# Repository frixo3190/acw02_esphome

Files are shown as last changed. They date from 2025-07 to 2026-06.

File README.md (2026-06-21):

# ACW02 ESPHome Module  

Custom ESPHome component for **Teknopoint** and **Airton** (Airton ref: 409729) AC units using the **Tuya ACW02 Wi-Fi module**.

---

## Weekly build status (auto build with last esphome version)

**ESP32 D1 Mini WROOM 32**  
 &nbsp;
 &nbsp;


**Lolin ESP32 C3 mini**  
 &nbsp;
 &nbsp;


**XIAO ESP32 C3**  
 &nbsp;
 &nbsp;


**XIAO ESP32 C6**  
 &nbsp;
 &nbsp;


---
## 📑 Table of Contents

- [⚠️ Compatibility Warning](#️-compatibility-warning)
- [✅ Community Compatibility List](#-community-compatibility-list)
- [📌 Contribute](#-contribute)
- [📋 Requirements](#-requirements)
- [⚙️ Settings](#️-settings)
  - [📁 Base Configuration](#-base-configuration)
  - [📶 Wi-Fi & Web Server Configuration](#-wi-fi--web-server-configuration)
- [🛠️ Build](#️-build)
  - [📦 Update](#-update)
- [🔍 Interface Details](#-interface-details)
- [🏠 Bonus Jeedom Configuration](#-bonus-jeedom-configuration)
- [📦 Components for Forhorse version](#-components-for-forhorse-version-thanks-to-him)
- [📦 Components for original version](#-components-for-original-version-mine)
  - [⚙️ Choosing the ESP32 Board](#️-choosing-the-esp32-board)
- [🧵 PCB Soldering & Wiring](#-pcb-soldering--wiring)
- [🧱 3D Files](#-3d-files)
  - [🖨️ Printing Material](#️-printing-material)
  - [📂 Available in the `3Dfiles/` directory](#-available-in-the-3dfiles-directory)
  - [🔩 Components](#-components-1)
  - [🧷 Assembly](#-assembly)
- [🧾 Option: QR Code Info](#-option-qr-code-info)
- [❗ Notes](#-notes)
- [⚠️ Disclaimer & Safety Notice](#️-disclaimer--safety-notice)
- [🛡️ License](#️-license)

---
## ⚠️ Compatibility Warning  

> **Important**  
> - Works on most **Teknopoint** units *(unconfirmed but no known issues so far, see the [Community Compatibility List](#-community-compatibility-list))*.  
> - Works on most **Airton** units *(unconfirmed but no known issues so far, see the [Community Compatibility List](#-community-compatibility-list))*.  
> - **Exception – Airton**: AC units using the **Wi-Fi module 409945** are **not compatible** with this firmware.  
>   - These units use a **Tuya MCU UART protocol** (`55 AA 03 ...`) instead of the custom `7A 7A ...` protocol implemented here.  
>   - You can still use **all provided hardware parts** (PCB, wiring, and 3D-printed enclosure) from this repository.  
>   - For these models, use this doc **[ACW02 ESPHome Tuya MCU integration](./docs/TUYA_MCU_SETUP.md)** instead — a basic configuration example is provided in that document and can be adapted to your needs.
> - **Exception – Some Airton mainboards**: Certain Airton units using control boards with a reference similar to `SMVHXX-XBXXXXX` may provide insufficient power on the Wi-Fi module connector for an ESP32-based ACW02 replacement.
>   - Symptoms may include random reboots, Wi-Fi instability, connection failures, or ESP32 brownout resets.
>   - If you experience these issues, power the ACW02 module from an external **5 V USB supply** (micro usb, usb c... depends on the ESP32's USB connector) while keeping the UART connection to the AC unit.
>   - In this configuration, the **original 12 V supply from the AC board must be disconnected** (but keep the GND) from the Wi-Fi/ACW02 connector to avoid back-powering or instability. (In this configuration, the polulu module is no longer necessary.)
>   - example:
    https://www.amazon.fr/dp/B0DLK81PNN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
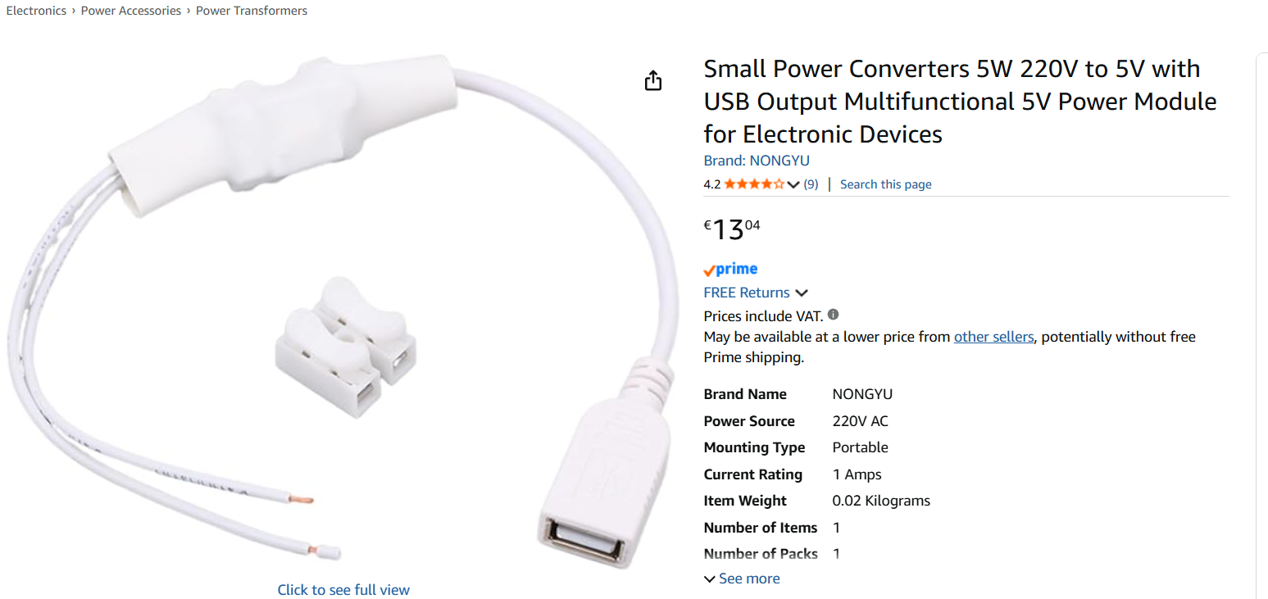
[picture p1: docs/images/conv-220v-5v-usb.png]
    
>   - This converter needs to be connected to the main power supply of the indoor unit, which is normally 220v.
>   - This issue appears to be related to the available current on specific board revisions and does not affect all Airton units.
>   - Further community feedback is welcome to identify the affected board revisions more precisely.
>   - All versions have affected my versions and that of Forhorse.

---

## ✅ Community Compatibility List  

A non-exhaustive list of tested models is available here:  
👉 [COMPATIBILITY.md](https://github.com/devildant/acw02_esphome/blob/main/COMPATIBILITY.md)  

---

## 📌 Contribute  

Help improve this project by reporting your unit compatibility.  
If your model is not referenced, please submit a report (**tested units only**):  
👉 [Submit your unit](https://github.com/devildant/acw02_esphome/issues/new?template=unit_report.yml)  
PS: If you encounter a problem, please post an issue before putting your incompatible model.

---

## 📋 Requirements

- Home Assistant with **MQTT integration** enabled and properly configured
- Enable the WIFI with the AC remote

## ⚙️ Settings

### 📁 Base Configuration

Open `esphome-acw02-en.yaml` or `esphome-acw02-fr.yaml` depending on your preferred language.

If you want to compile using the ESPHome Builder add-on in Home Assistant, use the files from the `HA-esphome-builder` folder instead (`ha-esphome-builder-acw02-en.yaml` or `ha-esphome-builder-acw02-fr.yaml`).

Edit the `substitutions` section — you can modify:

- `dev_name`
- `dev_friendly`
- `api_encrypted_key`
- `ota_password`
- `ap_password`
- `web_server_username`
- `web_server_password`

```yaml
substitutions:
  dev_name: acw02-salon
  dev_friendly: ACW02 salon
  lang: "en"
  api_encrypted_key: "D2oldc0VP++fni6src89tCSC0UwBhNPgyc8vgYN8/mA="
  ota_password: "REPLACE_WITH_YOUR_PASSWORD"
  ap_password: "fallbackpassword"
  web_server_username: admin
  web_server_password: admin
  # ESP32 D1 mini WROOM 32
  board: esp32dev
  TX: GPIO17
  RX: GPIO16
  
  ## LOLIN ESP32 C3 MINI
  # board: lolin_c3_mini
  # TX: GPIO21
  # RX: GPIO20

  ## XIAO (seeeds studio) ESP32 C3
  # board: seeed_xiao_esp32c3
  # TX: GPIO21
  # RX: GPIO20

  ## XIAO (seeeds studio) ESP32 C6
  # board: seeed_xiao_esp32c6
  # TX: GPIO16
  # RX: GPIO17
```

⚠️ **The configuration depends on the ESP32 card chosen (Comment/uncomment the blocks)**  
 - **ESP32 D1 mini WROOM 32**
    ```
    # ESP32 D1 mini WROOM 32
    board: esp32dev
    TX: GPIO17
    RX: GPIO16
    ```
 - **LOLIN ESP32 C3 MINI**
    ```
    # LOLIN ESP32 C3 MINI
    board: lolin_c3_mini
    TX: GPIO21
    RX: GPIO20
    ```
 - **XIAO (seeeds studio) ESP32 C3**
    ```
    # XIAO (seeeds studio) ESP32 C3
    board: seeed_xiao_esp32c3
    TX: GPIO21
    RX: GPIO20
    ```
 - **XIAO (seeeds studio) ESP32 C6**
    ```
    # XIAO (seeeds studio) ESP32 C6
    board: seeed_xiao_esp32c6
    TX: GPIO16
    RX: GPIO17
    ```

🔑 I recommend visiting [this page](https://esphome.io/components/api.html) to generate a unique `api_encrypted_key`.

---

### 📶 Wi-Fi & Web Server Configuration

Open `secrets.yaml` and fill in your Wi-Fi credentials and desired web server access:

```yaml
wifi_ssid: "testesp32"
wifi_password: "testesp32"
wifi_ssid2: "testesp32"
wifi_password2: "testesp32"
wifi_ssid3: "testesp32"
wifi_password3: "testesp32"
```

---

## 🛠️ Build

- [Build on Windows (native)](docs/install_from_windows_directly.md)  
- [Build on MACOS (native)](docs/install_from_macos_directly.md)
- [Build on Windows with Docker](docs/install_from_docker_win.md)
- Build with ESPHome Builder (2025.7.5 minimum) with Home Assistant add-on:  
  Use the files in the [`HA-esphome-builder`](HA-esphome-builder) folder with the Home Assistant ESPHome add-on:  
  - [`ha-esphome-builder-acw02-fr.yaml`](HA-esphome-builder/ha-esphome-builder-acw02-fr.yaml) – version française  
  - [`ha-esphome-builder-acw02-en.yaml`](HA-esphome-builder/ha-esphome-builder-acw02-en.yaml) – English version  

### 📦 Update

> **🔁 After updating:**  
> I recommend pressing the **"G1: Rebuild MQTT Entities"** button to ensure all MQTT discovery topics are refreshed properly.

---

## 🔍 Interface Details

👉 [See Interface Details](docs/interface_details.md)

---

## 🏠 Bonus Jeedom Configuration

> **Note:** Jeedom is **not officially supported**. This is provided as an **informational guide only**.

- [Enable on Jeedom](docs/enable_on_jeedom.md)  

---
### 📦 Components for Forhorse version (thanks to him)
- **PCB**
  - **[Forhorse PCB](https://github.com/devildant/acw02_esphome/blob/main/docs/version_Forhorse.md)**
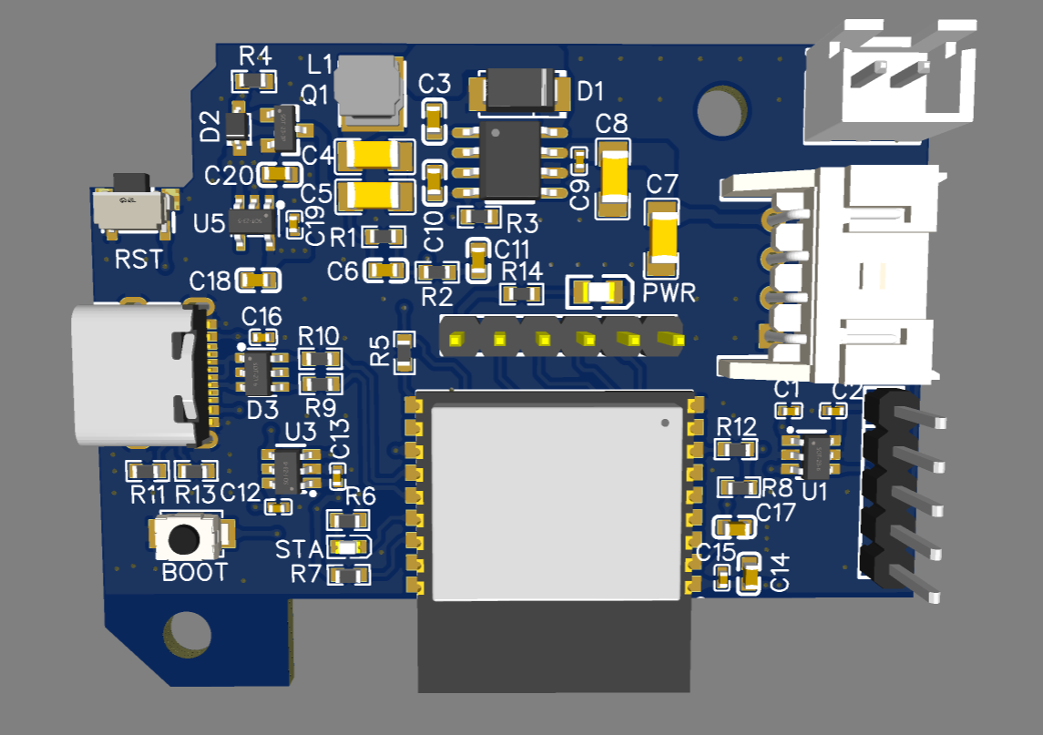
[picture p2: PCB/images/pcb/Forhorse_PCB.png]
Forhorse
    

- **Components**
  - **[Connector: JST XA 2.5 male/male 4 pins (standard direction) (x1)](https://www.aliexpress.com/item/1005008857984831.html)** 

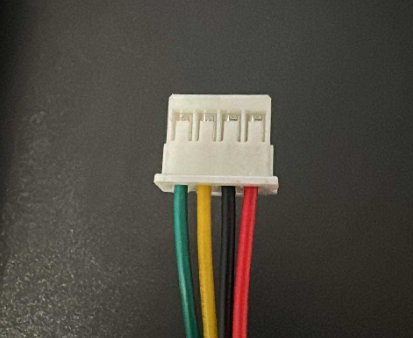
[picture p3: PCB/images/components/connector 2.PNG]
JST order
    

- **Configuration board in yaml**:
```yaml
 # LOLIN ESP32 C3 MINI
 board: lolin_c3_mini
 TX: GPIO21
 RX: GPIO20
```

- **(Optional) Additional configuration to add to the yaml file at the end (currently not linked to the firmware)**:
```yaml
## Start of the section for the STA LED
# Off when everything is OK
# slow blinking in case of warning (Wi-Fi connection issue, etc.)
# fast blinking in case of error
status_led:
  pin:
    number: GPIO03
    inverted: true
## End of the section for the STA LED

## Start of the section for the remote temperature probe
# Temperature probe
sensor:
  - platform: ntc
    id: external_temperature_sensor
    sensor: resistance_sensor
    calibration:
      b_constant: 3950
      reference_temperature: 25°C
      reference_resistance: 10kOhm
    name: NTC Temperature

  # Source sensors:
  - platform: resistance
    id: resistance_sensor
    sensor: source_sensor
    configuration: DOWNSTREAM
    resistor: 10kOhm
    name: Resistance Sensor
    internal: True

  - platform: adc
    id: source_sensor
    pin: GPIO01
    attenuation: 12db
    update_interval: never
    internal: True

switch:
  - platform: gpio
    pin: GPIO10
    id: ntc_vcc
    internal: True

interval:
  - interval: 10s #adjust frequency of measurement refresh here
    then:
      - switch.turn_on: ntc_vcc
      - component.update: source_sensor
      - switch.turn_off: ntc_vcc
## End of the section for the remote temperature probe
```

### 📦 Components for original version (mine)

- **[12V → 5V Regulator D24V10F5](https://shop.mchobby.be/fr/regulateurs/554--regul-5v-1a-step-down-d24v10f5-3232100005549-pololu.html)**  
  [Manufacturer](https://www.pololu.com/product/2831)  
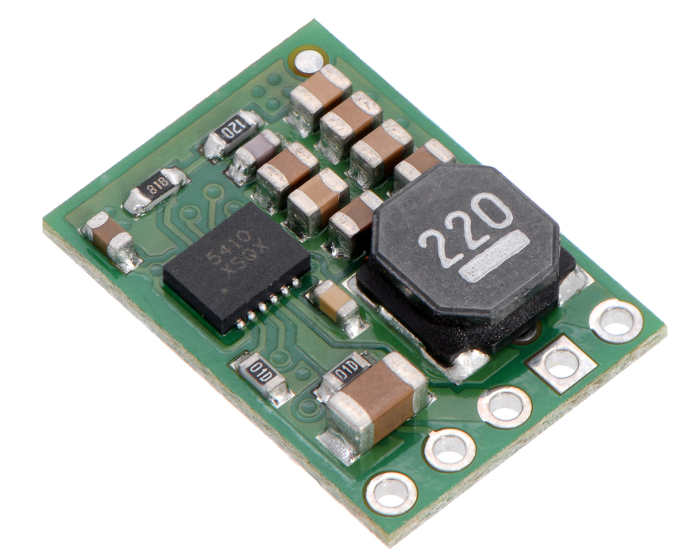
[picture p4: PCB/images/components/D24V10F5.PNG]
D24V10F5
  

- **Channels Logic Level Converter**

  > **2 options available:**  
  > You can either choose a ready-made module based on the CYT1076,  
  > or use a custom board (to be assembled by JLCPCB) designed around two SN74LVC2T45DCUR.  
  > In practice, the second solution is far more optimized for UART communication.  
  > Personally, I recommend this option: a bit more expensive but much more efficient.  
  > (Of course, I might be slightly biased since I designed it myself 🙂)

  - **[4 Channels Logic Level Converter Bi-Directional Shifter (x1): CYT1076](https://amzn.eu/d/2MhG08s)**  
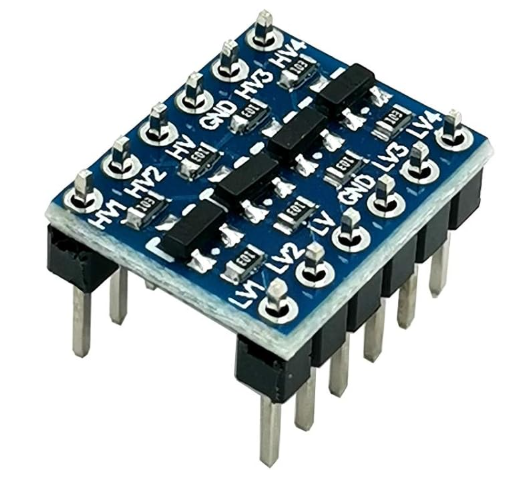
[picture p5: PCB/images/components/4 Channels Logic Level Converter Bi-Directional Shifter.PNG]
CYT1076
    

  - **Channels Logic Level Converter (x1): SN74LVC2T45DCUR**  
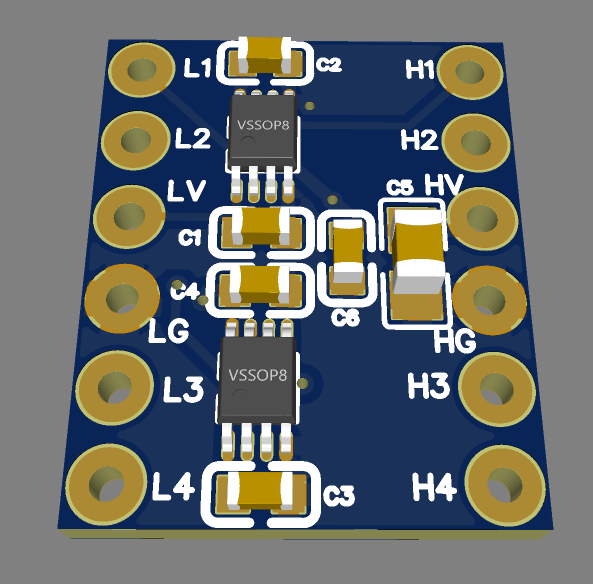
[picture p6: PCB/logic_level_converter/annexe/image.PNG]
SN74LVC2T45DCUR
      
    - 📥 [Download ZIP (GERBER, BOM, Pick & Place)](https://github.com/devildant/acw02_esphome/raw/main/PCB/logic_level_converter/uart_conv_gerber_BOM_PickAndPlace.zip)
    - 👉 [JLCPCB Assembly Guide](docs/uart_convert_jlcpcb.md)

- **PCB and ESP32 (2 options available)**

  - **[ESP32 D1 MINI WROOM 32](https://github.com/devildant/acw02_esphome/blob/main/docs/version_esp32_D1_mini_wroom32.md)**  
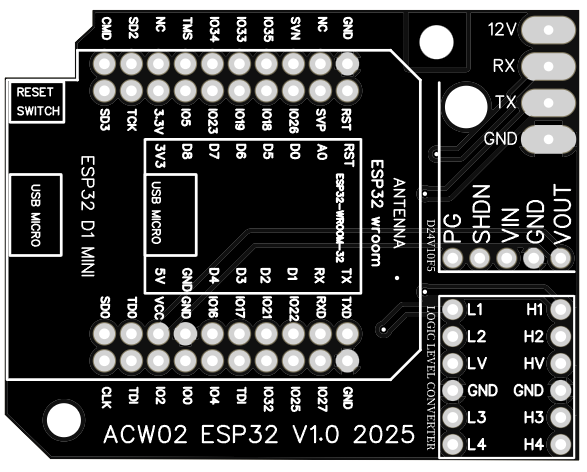
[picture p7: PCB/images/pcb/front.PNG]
front
      
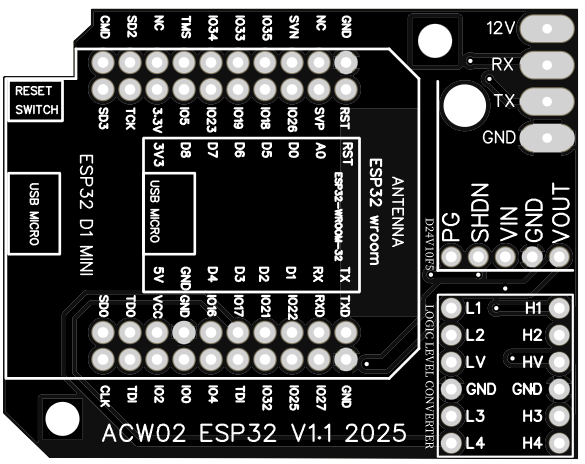
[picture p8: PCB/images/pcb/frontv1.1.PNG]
front
    

  - **[LOLIN ESP32 C3 MINI](https://github.com/devildant/acw02_esphome/blob/main/docs/version_lolin_esp32_C3.md)**  
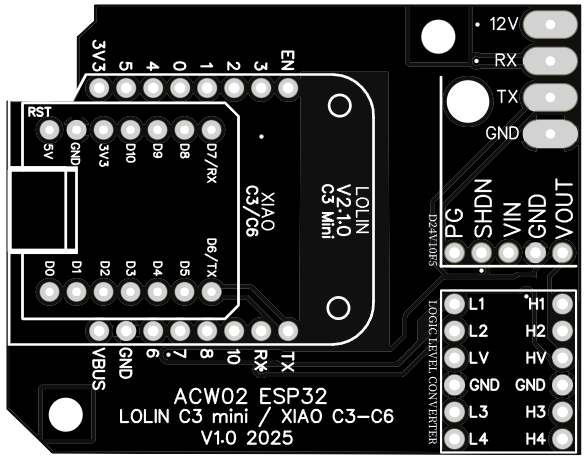
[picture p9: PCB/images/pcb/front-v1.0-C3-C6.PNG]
front
    

  - **[XIAO ESP32 C3-C6](https://github.com/devildant/acw02_esphome/blob/main/docs/version_xiao_esp32_C3_C6.md)**  
    front

- **[5 pins male 2.54mm (x1): MaleL7.5-1X5P](https://fr.aliexpress.com/item/1005007128029220.html)**  
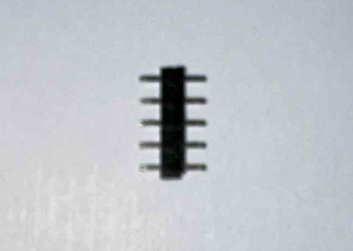
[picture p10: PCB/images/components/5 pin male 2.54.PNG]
  

- **[6 pins male 2.54mm (x2): MaleL7.5-1X6P](https://fr.aliexpress.com/item/1005007128029220.html)**  
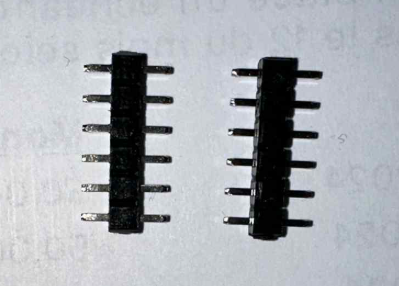
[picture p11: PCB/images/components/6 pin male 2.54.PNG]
  

- **[Connector: JST XA 2.5 male 4 pins (Reverse direction) (x1)](https://www.aliexpress.com/item/1005008857984831.html)**  
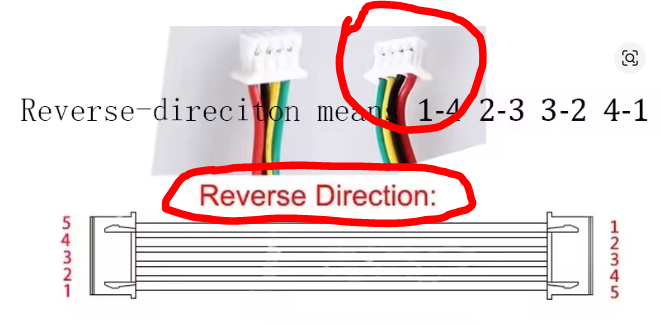
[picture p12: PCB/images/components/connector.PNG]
JST
  

📌 Important: Use reverse wiring for the following order:  
JST order

---

### ⚙️ Choosing the ESP32 Board

Several ESP32 boards can be used with this module. Each has its own pros and cons depending on your needs.

#### ESP32 D1 MINI WROOM 32
- ✅ Used for development, therefore the most tested version  
- ✅ Built-in **reset** button on the case  
- ❌ Many cheap clones with poor 5V → 3.3V regulator (may cause malfunction)  
- ❌ Slightly weaker Wi-Fi signal due to component layout and antenna position  
- ❌ No external antenna support  

#### LOLIN ESP32 C3 MINI (Not recommended)
- ✅ Built-in **reset** button on the case  
- ✅ Better Wi-Fi signal compared to ESP32 D1 MINI WROOM 32  
- ❌ No external antenna support
- ❌ Trouble with modern WIFI router > WIFI 4 (qood singal but WIFI TX/RX very slow, i detect lot of difficulty with wifi 6 in 2.4GHZ)

#### XIAO ESP32 C3
- ✅ External antenna support (Wi-Fi signal ≥ LOLIN ESP32 C3 MINI)  
- ❌ No **reset** button on the case  

#### XIAO ESP32 C6
- ✅ External antenna support  
- ❌ Antenna **not included** (must be purchased separately, internal antenna has very poor reception) 
- ❌ No **reset** button on the case  
- ❌ Average Wi-Fi signal, often weaker than ESP32 D1 MINI WROOM 32 with internal antenna (that's why you need buy the external antenna)

---

### 🧵 PCB Soldering & Wiring

- RED = 12V  
- BLACK = RX  
- YELLOW = TX  
- GREEN = GND

---

## 🧱 3D Files

### 🖨️ Printing Material  

| Material | Compatible | Notes |
|---|---|---|
| PLA | ❌ No | Not recommended (low heat resistance) |
| PETG | ✅ Yes (recommended) | Good balance of strength & printability |
| ABS | ✅ Yes | Better heat resistance |
| ASA | ✅ Yes | UV resistant, suitable for outdoors |
| PC | ✅ Yes | Very strong & heat resistant |

> ⚠️ **Why not use PLA?**  
> - PLA has a glass transition temperature of only **45–50 °C (or even lower)**.  
> - By contrast, **PETG can withstand up to ~80 °C**, making it much more reliable.  
> - For electronic components that generate heat, PLA is unsafe in warm environments — especially if your AC unit also provides **heating**.  

### 📂 Available in the `3Dfiles/` directory:

#### Version 1

- [acw02 case bottom (.stl)](https://github.com/devildant/acw02_esphome/raw/main/3Dfiles/D1-MIMI/Version%201/acw02%20case%20bot.stl)
- [acw02 case top (.stl)](https://github.com/devildant/acw02_esphome/raw/main/3Dfiles/D1-MIMI/Version%201/acw02%20case%20top.stl)
- [Alternative: top case with thermo cable hole](https://github.com/devildant/acw02_esphome/raw/main/3Dfiles/D1-MIMI/Version%201/acw02%20case%20top%20cable%20with%20thermo.stl)

#### Version 2

- [acw02 case bot with air flow (.stl)](https://github.com/devildant/acw02_esphome/raw/main/3Dfiles/D1-MIMI/Version%202/acw02%20case%20bot%20with%20air%20flow.stl)
- [acw02 case top air flow (.stl)](https://github.com/devildant/acw02_esphome/raw/main/3Dfiles/D1-MIMI/Version%202/acw02%20case%20top%20air%20flow.stl)
- [acw02 case top cable with thermo air flow (.stl)](https://github.com/devildant/acw02_esphome/raw/main/3Dfiles/D1-MIMI/Version%202/acw02%20case%20top%20cable%20with%20thermo%20air%20flow.stl)
- [acw02 case top cable with thermo plastic card (.stl)](https://github.com/devildant/acw02_esphome/raw/main/3Dfiles/D1-MIMI/Version%202/acw02%20case%20top%20cable%20with%20thermo%20plastic%20card.stl)
- [acw02 case top plastic card (.stl)](https://github.com/devildant/acw02_esphome/raw/main/3Dfiles/D1-MIMI/Version%202/acw02%20case%20top%20plastic%20card.stl)
- [card (.stl)](https://github.com/devildant/acw02_esphome/raw/main/3Dfiles/D1-MIMI/Version%202/card.stl)

#### Version 2 for pcb Forhorse
- [full pcb acw02 case bot with air flow (.stl)](https://github.com/devildant/acw02_esphome/raw/main/3Dfiles/full%20pcb%20by%20Forhorse/full%20pcb%20acw02%20case%20bot%20with%20air%20flow.stl)
- [acw02 case top air flow (.stl)](https://github.com/devildant/acw02_esphome/raw/main/3Dfiles/D1-MIMI/Version%202/acw02%20case%20top%20air%20flow.stl)
- [acw02 case top cable with thermo air flow (.stl)](https://github.com/devildant/acw02_esphome/raw/main/3Dfiles/D1-MIMI/Version%202/acw02%20case%20top%20cable%20with%20thermo%20air%20flow.stl)
- [acw02 case top cable with thermo plastic card (.stl)](https://github.com/devildant/acw02_esphome/raw/main/3Dfiles/D1-MIMI/Version%202/acw02%20case%20top%20cable%20with%20thermo%20plastic%20card.stl)
- [acw02 case top plastic card (.stl)](https://github.com/devildant/acw02_esphome/raw/main/3Dfiles/D1-MIMI/Version%202/acw02%20case%20top%20plastic%20card.stl)
- [card (.stl)](https://github.com/devildant/acw02_esphome/raw/main/3Dfiles/D1-MIMI/Version%202/card.stl)

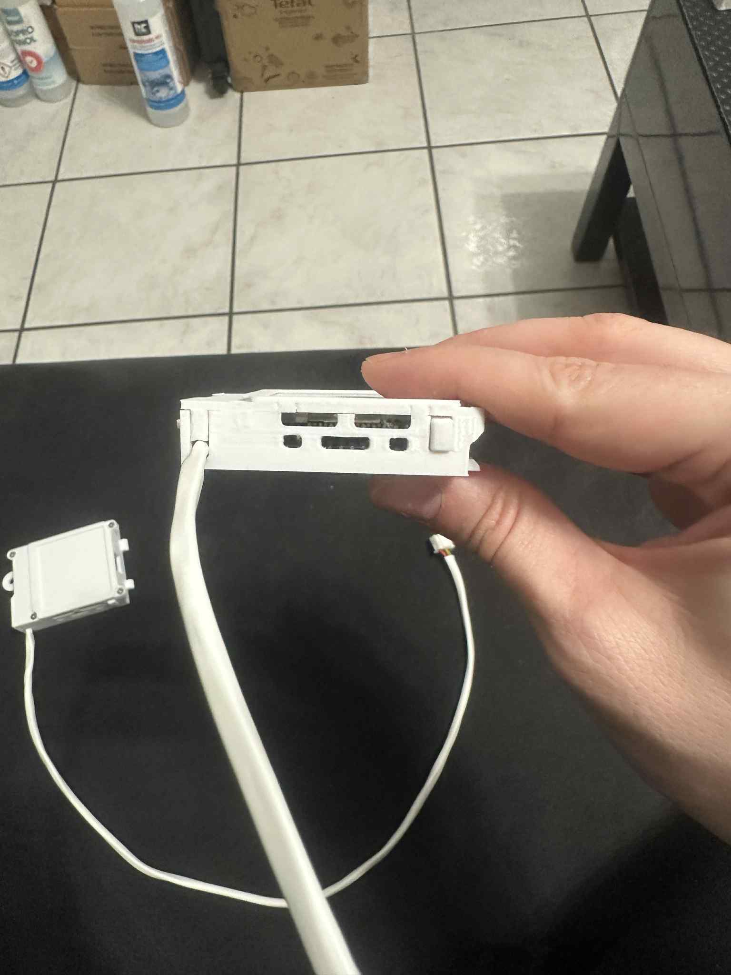
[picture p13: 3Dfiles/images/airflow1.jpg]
airflow1


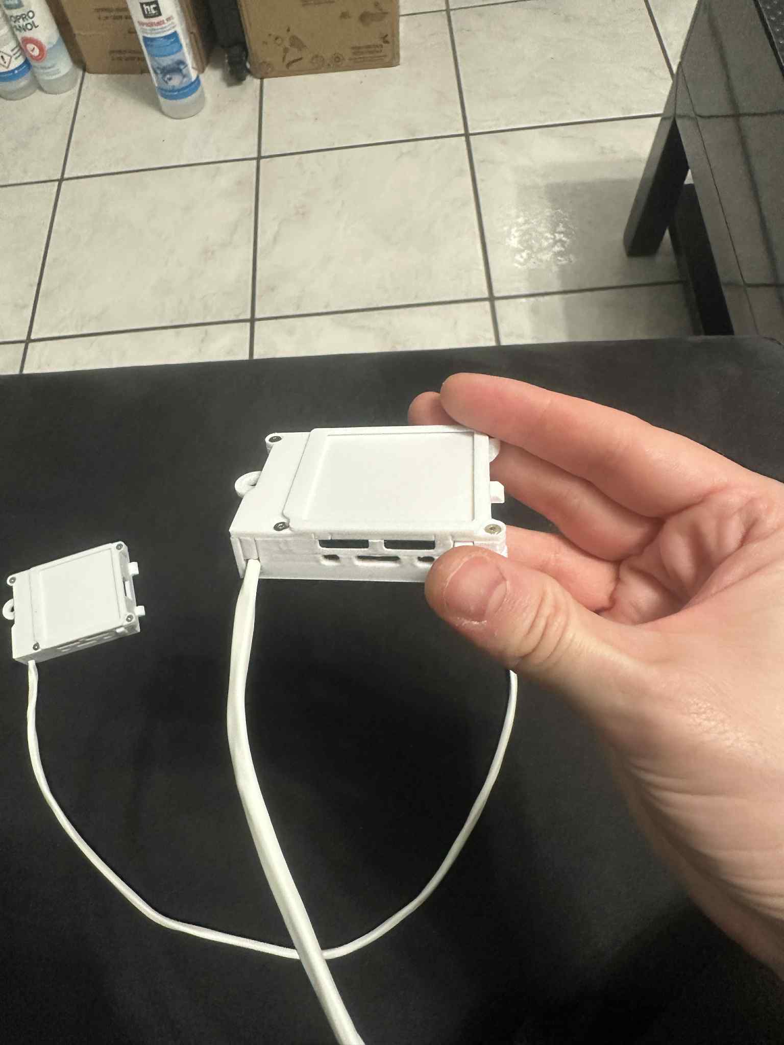
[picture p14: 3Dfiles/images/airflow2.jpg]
airflow2


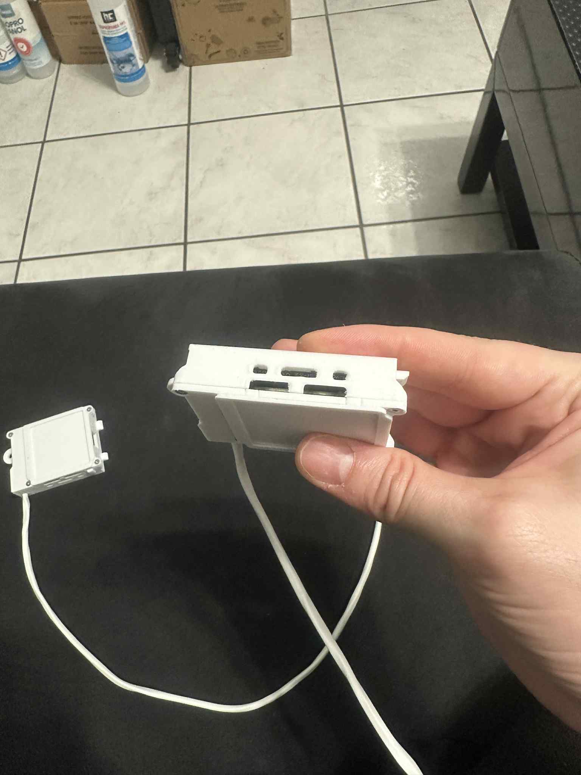
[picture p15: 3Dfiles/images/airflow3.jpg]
airflow3


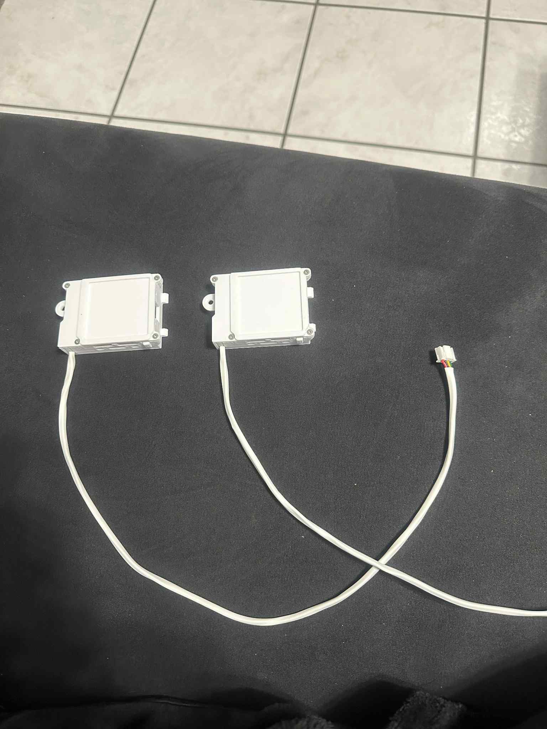
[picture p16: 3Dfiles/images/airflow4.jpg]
airflow4


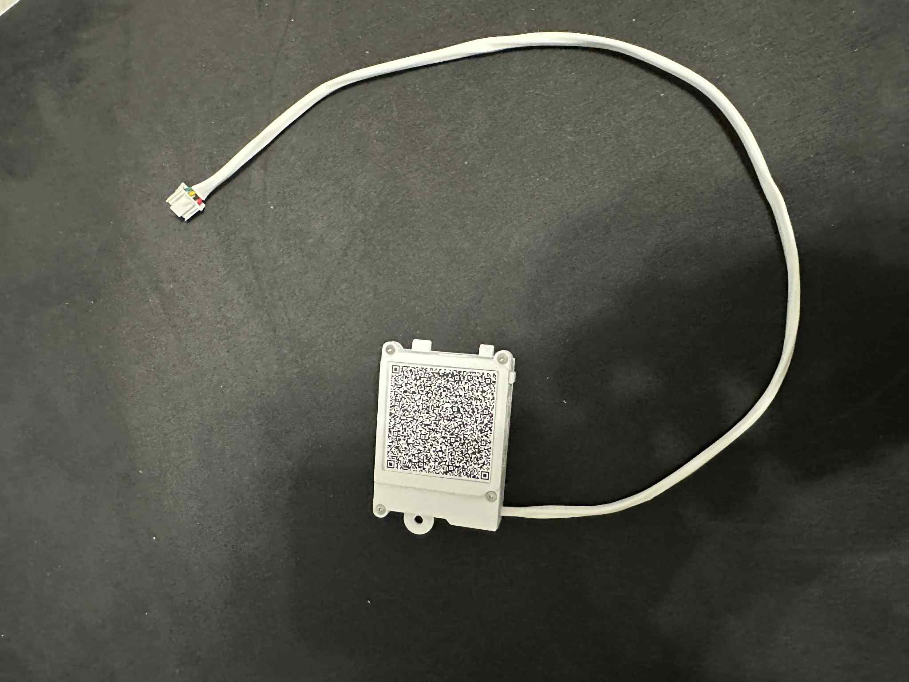
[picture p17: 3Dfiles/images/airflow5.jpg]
airflow5


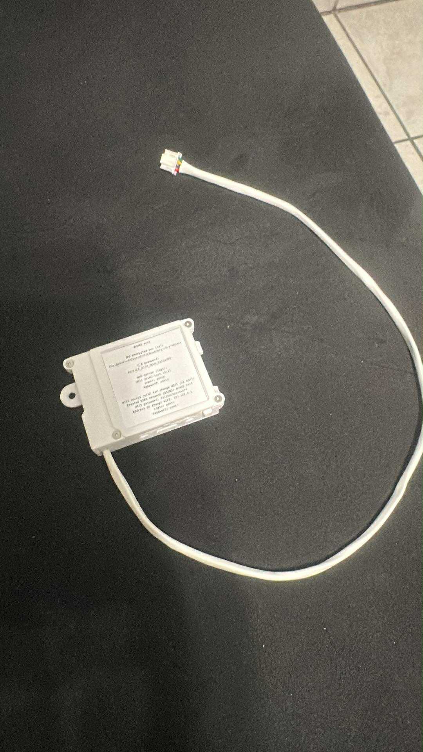
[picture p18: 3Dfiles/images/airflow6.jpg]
airflow6
 

#### For ESP32 D1 MINI WROOM 32
- [button.stl](https://github.com/devildant/acw02_esphome/raw/main/3Dfiles/D1-MIMI/button.stl)
- [solder board ESP32 D1 MINI.stl](https://github.com/devildant/acw02_esphome/raw/main/3Dfiles/D1-MIMI/solder%20board%20ESP32%20D1%20MINI.stl)

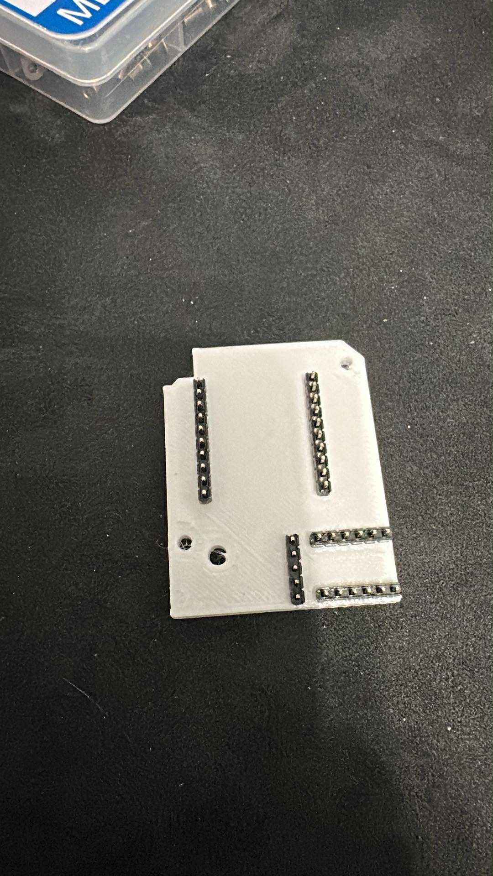
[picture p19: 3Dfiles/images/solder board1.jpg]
solder1
  

#### For LOLIN ESP32 C3 MINI
- [button lolin c3.stl](https://github.com/devildant/acw02_esphome/raw/main/3Dfiles/LOLIN-C3-XIAO-C3-C6/button%20lolin%20c3.stl)
- [solder board ESP32 C3-C6.stl](https://github.com/devildant/acw02_esphome/raw/main/3Dfiles/LOLIN-C3-XIAO-C3-C6/solder%20board%20ESP32%20C3-C6.stl)

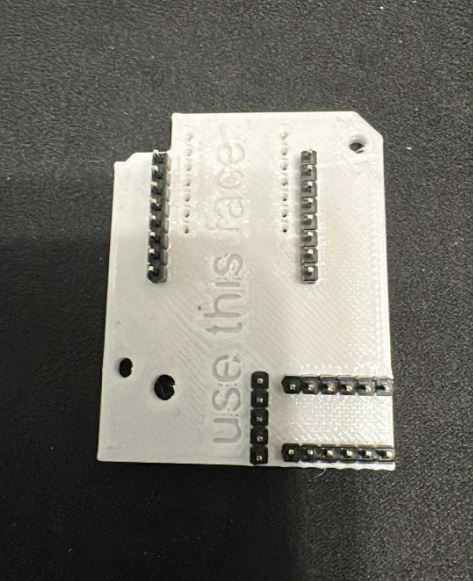
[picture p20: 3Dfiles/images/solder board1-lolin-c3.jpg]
solder1
  

#### For XIAO ESP32 C3-C6
- [solder board ESP32 C3-C6.stl](https://github.com/devildant/acw02_esphome/raw/main/3Dfiles/LOLIN-C3-XIAO-C3-C6/solder%20board%20ESP32%20C3-C6.stl)

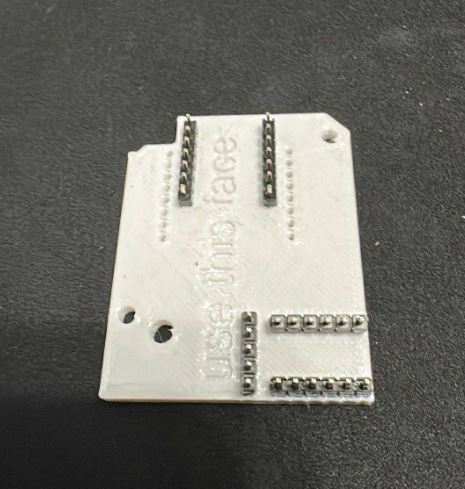
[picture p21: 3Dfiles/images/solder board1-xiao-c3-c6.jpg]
solder1
  

- support antenna (multiple config possible)
  - support antenna rigid
    - [support antenna rigid part A.stl](https://github.com/devildant/acw02_esphome/raw/main/3Dfiles/LOLIN-C3-XIAO-C3-C6/support%20antenna%20rigid%20part%20A.stl)
    - [support antenna rigid part B.stl](https://github.com/devildant/acw02_esphome/raw/main/3Dfiles/LOLIN-C3-XIAO-C3-C6/support%20antenna%20rigid%20part%20B.stl)

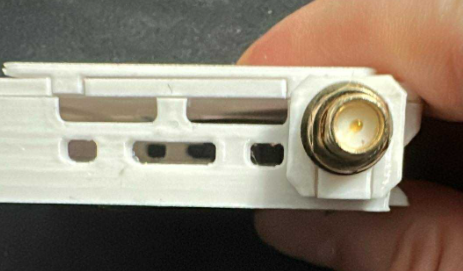
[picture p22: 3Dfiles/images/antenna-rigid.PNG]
      
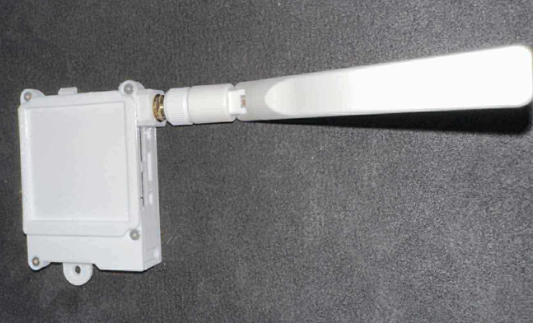
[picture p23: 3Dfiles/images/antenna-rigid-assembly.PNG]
      

  - [support antenna flex horizontal.stl](https://github.com/devildant/acw02_esphome/raw/main/3Dfiles/LOLIN-C3-XIAO-C3-C6/support%20antenna%20flex%20horizontal.stl)

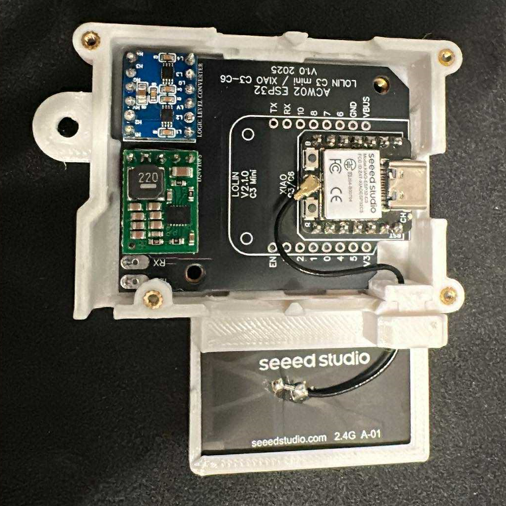
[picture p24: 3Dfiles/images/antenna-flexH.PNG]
    
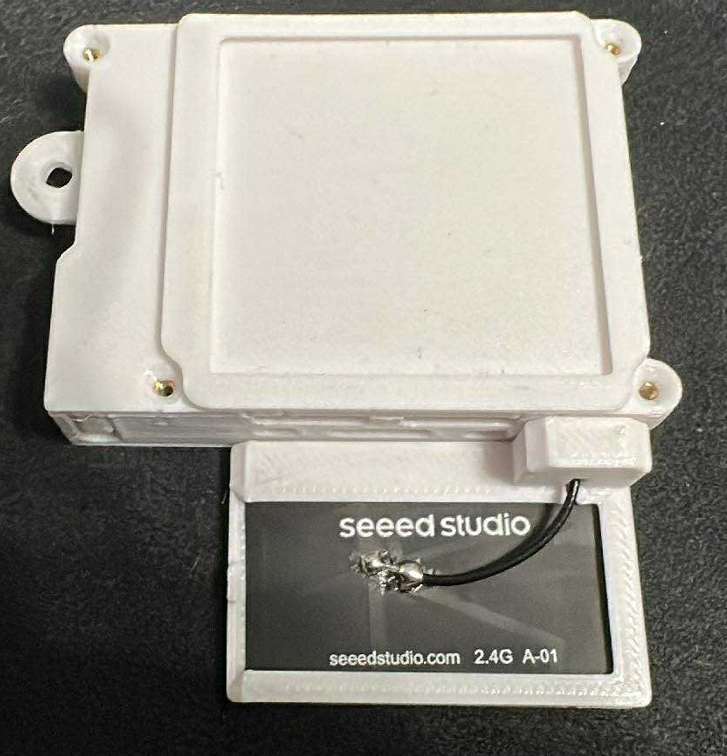
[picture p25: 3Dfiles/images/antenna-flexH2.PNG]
    

  - [support antenna flex vertical.stl](https://github.com/devildant/acw02_esphome/raw/main/3Dfiles/LOLIN-C3-XIAO-C3-C6/support%20antenna%20flex%20vertical.stl)

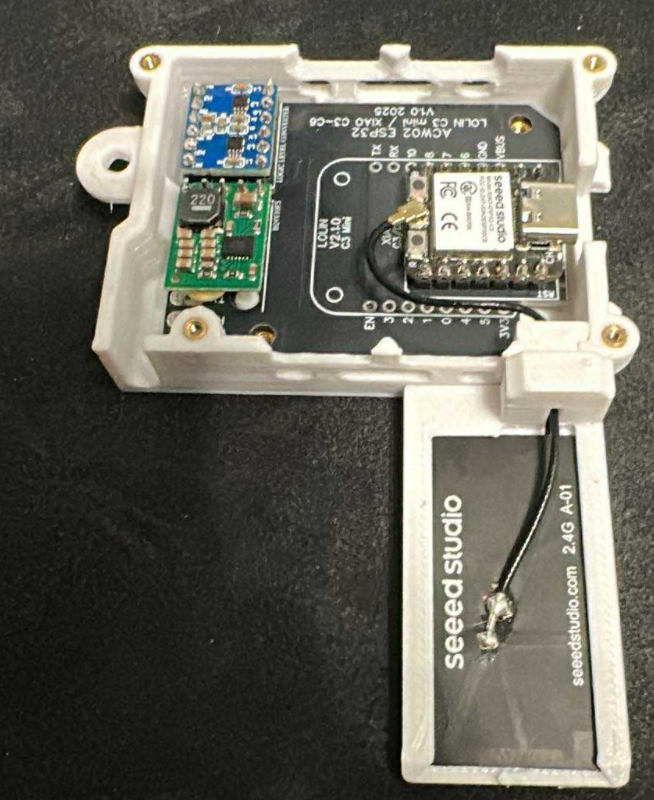
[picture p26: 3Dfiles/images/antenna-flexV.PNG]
    
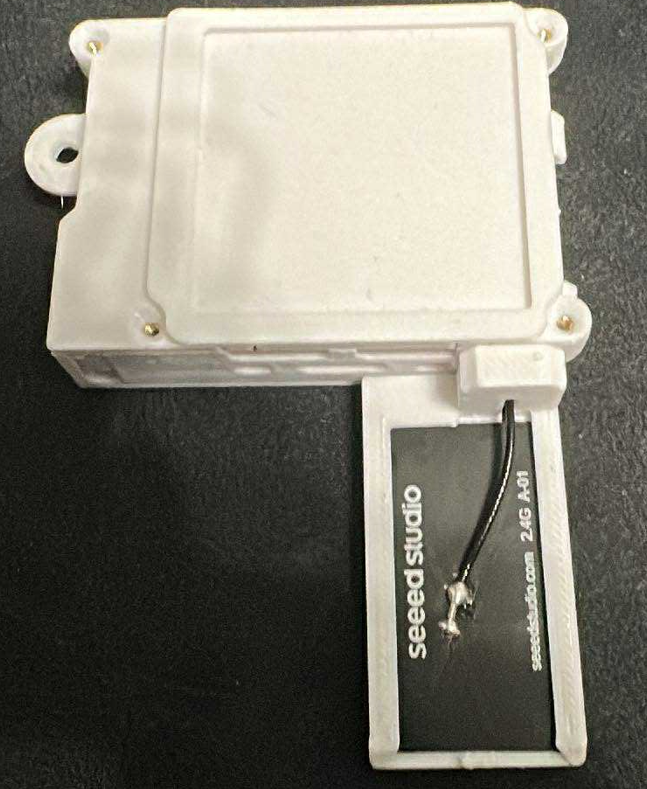
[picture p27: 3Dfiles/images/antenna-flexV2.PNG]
    

  - [support antenna flex free.stl](https://github.com/devildant/acw02_esphome/raw/main/3Dfiles/LOLIN-C3-XIAO-C3-C6/support%20antenna%20flex%20free.stl)

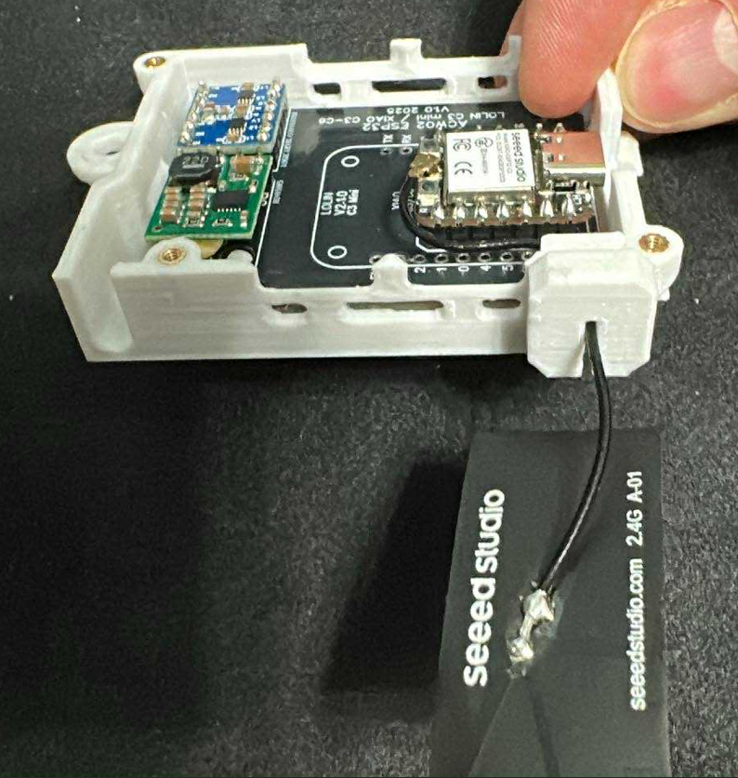
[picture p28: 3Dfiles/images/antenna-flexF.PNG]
    
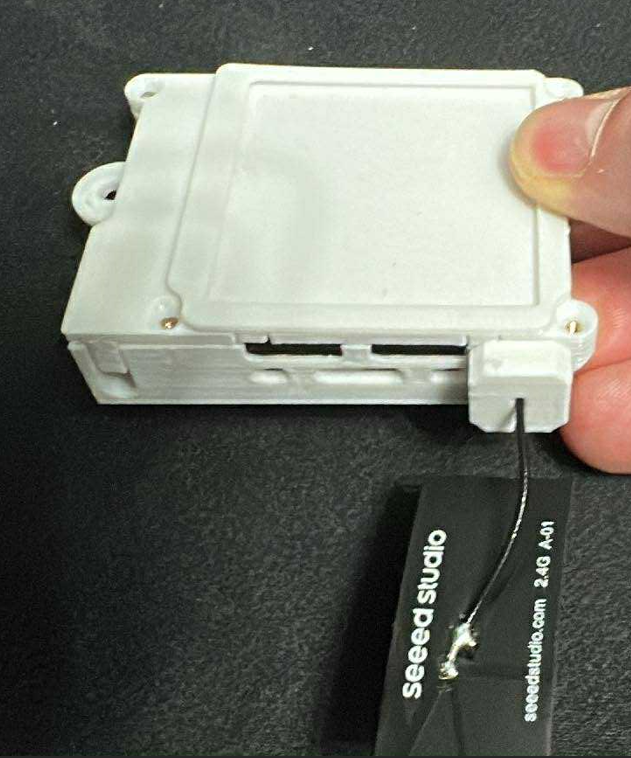
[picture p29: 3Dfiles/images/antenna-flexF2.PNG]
    

#### BONUS: for airton support
You don't seem to have a mounting bracket for the module, so I'll provide one for you to stick on your air conditioner. :) (fix with double-sided tape)

- [support airton (.stl)](https://github.com/devildant/acw02_esphome/raw/main/3Dfiles/support%20for%20airton/support%20airton.stl)

---

### 🔩 Components

- [insert M2(OD3.2mm) Length 2.5mm 50pcs (x4)](https://www.aliexpress.com/item/1005003582355741.html)  
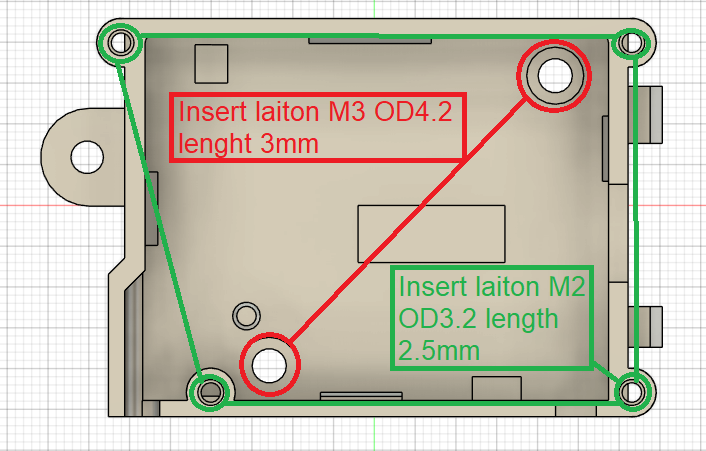
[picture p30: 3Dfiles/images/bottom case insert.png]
insert M2
  

- [insert M3(OD4.2mm) Length 3mm 50pcs (x2)](https://www.aliexpress.com/item/1005003582355741.html)  
  insert M3

- [Optional: thermo white 4.8 mm x 10 m](https://amzn.eu/d/8Y1PVUU)  
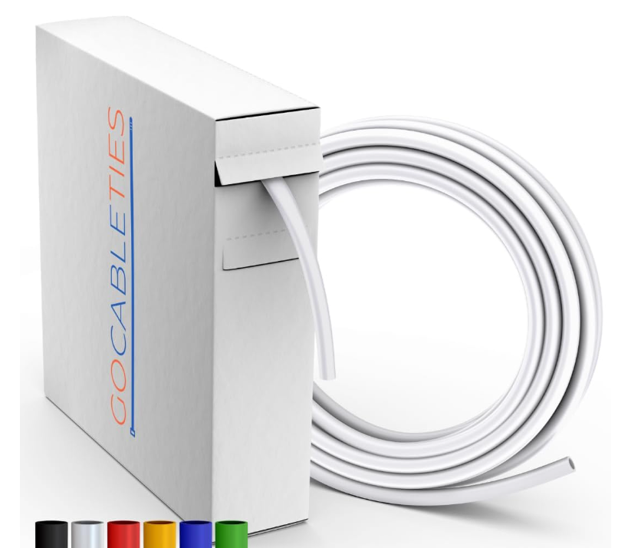
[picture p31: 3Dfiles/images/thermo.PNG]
thermo
    
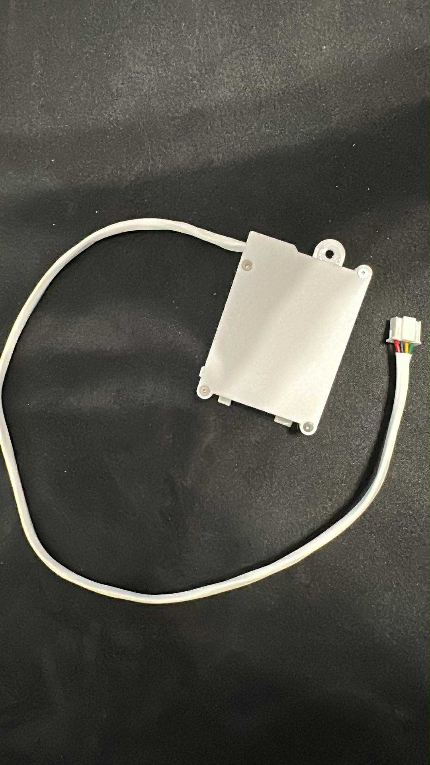
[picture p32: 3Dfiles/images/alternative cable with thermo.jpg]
thermo in place
  

- Countersunk head screw M2x6mm (x4)  
- Screw M3x4mm (x2) (+1 for airton support)

---

### 🧷 Assembly

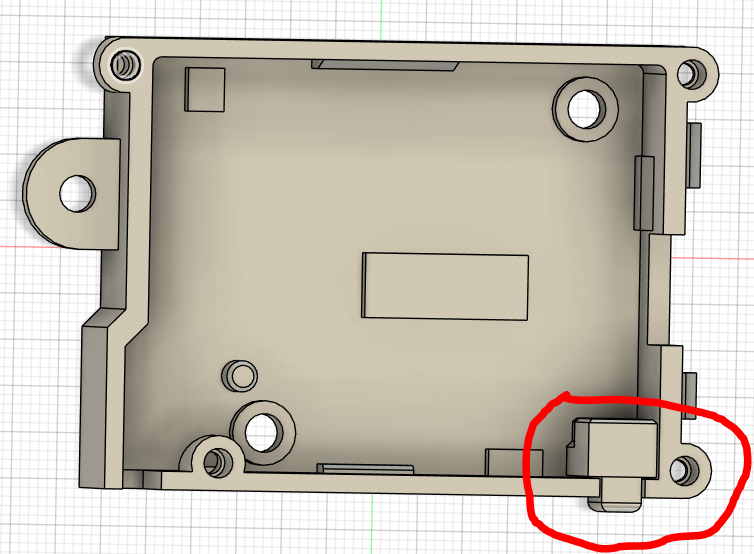
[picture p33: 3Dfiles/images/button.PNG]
button
1.   
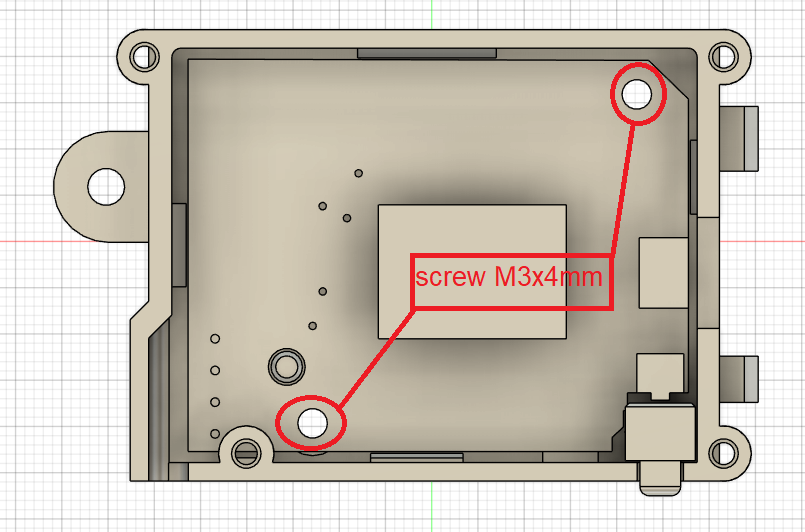
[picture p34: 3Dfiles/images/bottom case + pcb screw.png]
bottom case
2.   
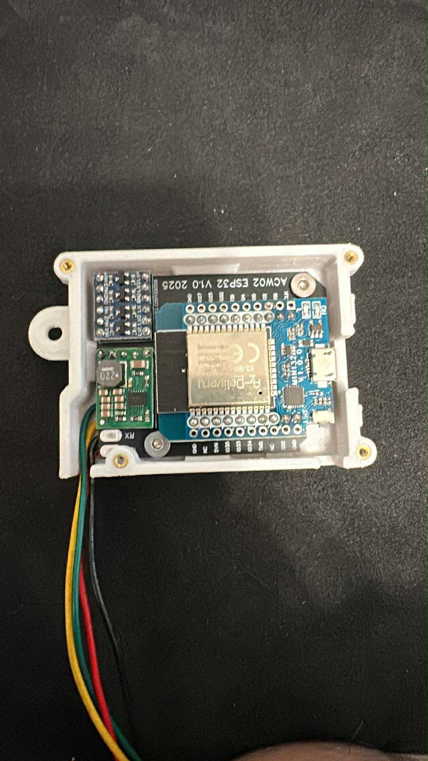
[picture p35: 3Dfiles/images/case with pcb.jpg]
case + PCB
3.   
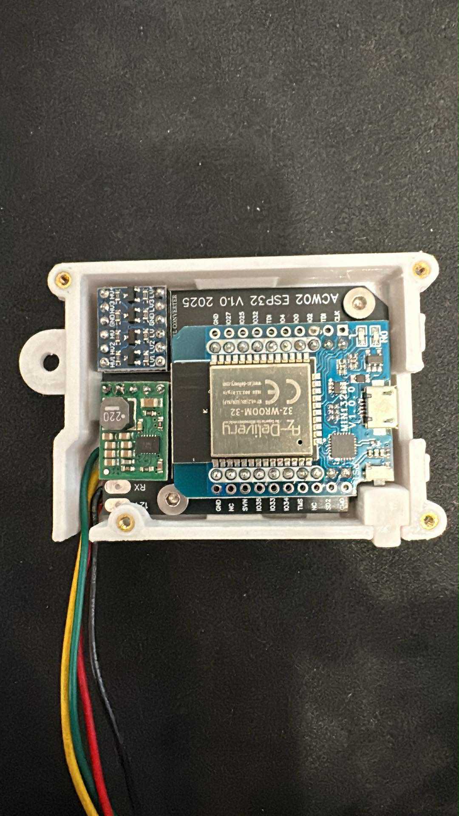
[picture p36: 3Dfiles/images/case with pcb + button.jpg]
case + PCB + button
4.   
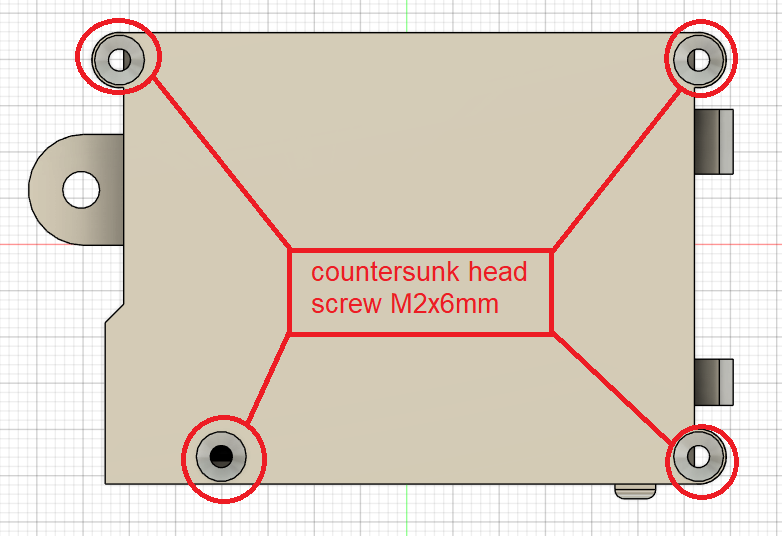
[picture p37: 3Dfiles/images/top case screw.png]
top case
5.   
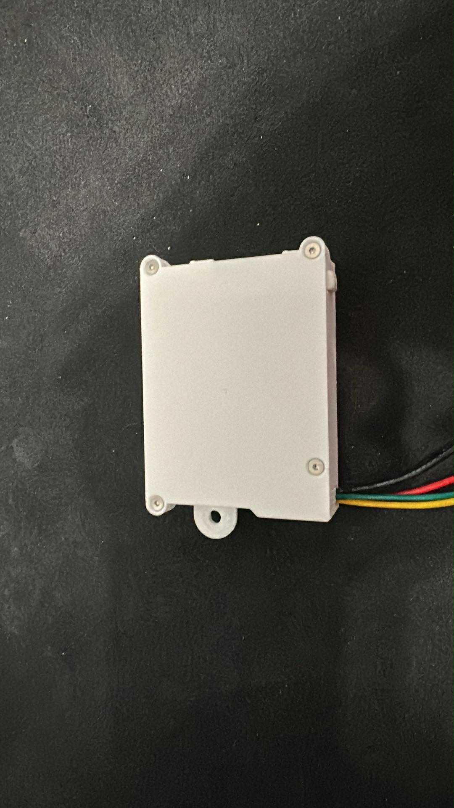
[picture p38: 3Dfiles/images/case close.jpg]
closed
6. 

#### BONUS : support airton

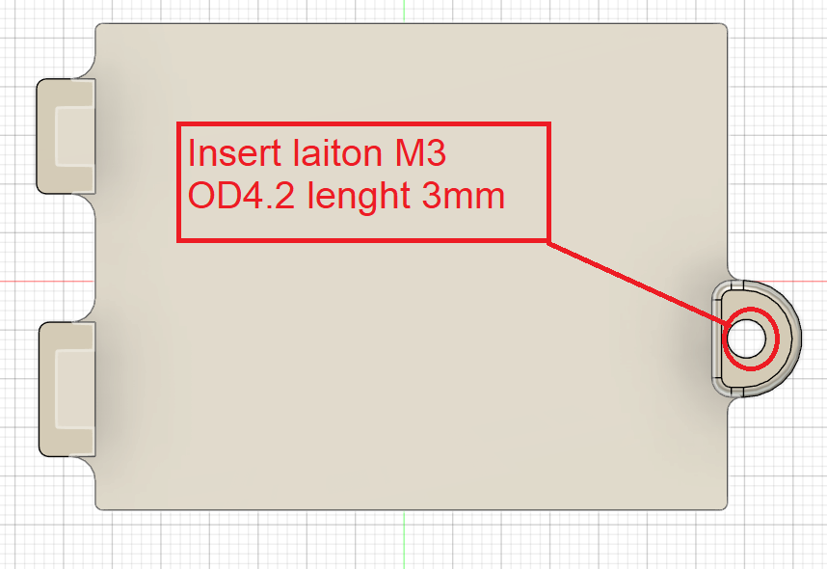
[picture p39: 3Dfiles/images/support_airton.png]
support1
1. 

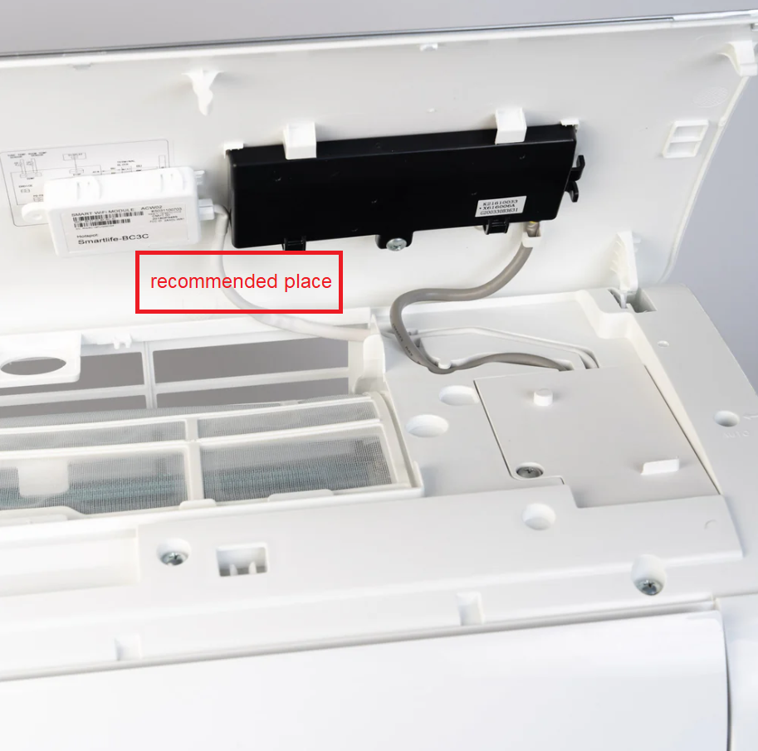
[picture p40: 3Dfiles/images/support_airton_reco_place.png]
support2
2. 

3. support3

4. support4

5. support5

---

## 🧾 Option: QR Code Info

You can generate a QR code to store module information:

1. Open `create_QRcode_info.html` in your browser.  
2. Import your YAML file (`esphome-acw02-en.yaml` or `esphome-acw02-fr.yaml`).  
3. Verify the data and click the QR code to download.  
4. Print and stick it on the module.

---

## ❗ Notes

This component requires **MQTT** to work properly.  
Please ensure you understand how to configure it with Home Assistant.

---

## ⚠️ Disclaimer & Safety Notice

🚨 **IMPORTANT — PLEASE READ BEFORE USING**  

 Working with electrical devices, HVAC systems, and embedded electronics carries inherent risks.  
Proceed **only if you fully understand what you are doing** and have the proper knowledge and equipment.  

- 🔌 Always disconnect power before modifying or connecting hardware.  
- ⚙️ Double-check wiring, pin assignments, and voltages before powering on.  
- 💥 Incorrect wiring or configuration may permanently damage your **AC unit**, **ESP module**, or **other connected components**.  
- 🔥 Electrical work should be done at your own risk and in compliance with local regulations.  

**I take no responsibility** for any direct, indirect, incidental, or consequential damages,  
including (but not limited to) **hardware failure, data loss, personal injury, fire, or electric shock** resulting from the use of this project.  

By using the files, code, or documentation provided in this repository,  
you acknowledge that you do so **entirely at your own risk**.

---

# 🛡️ License

This repository uses multiple licenses depending on content type:

- **Code** (`*.yaml`, `*.cpp`, `*.h`) — [GNU GPLv3](https://www.gnu.org/licenses/gpl-3.0.html)
- **PCB files** (`*.zip`, `*.json`) — [CC BY-NC-SA 4.0](https://creativecommons.org/licenses/by-nc-sa/4.0/)
- **3D models** (`*.f3d`, `*.stl`) — [CC BY-NC-SA 4.0](https://creativecommons.org/licenses/by-nc-sa/4.0/)

> Commercial use of PCB and 3D files is **strictly prohibited**.

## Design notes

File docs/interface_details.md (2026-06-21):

# 🔍 Interface Details

## 🎛️ Controls

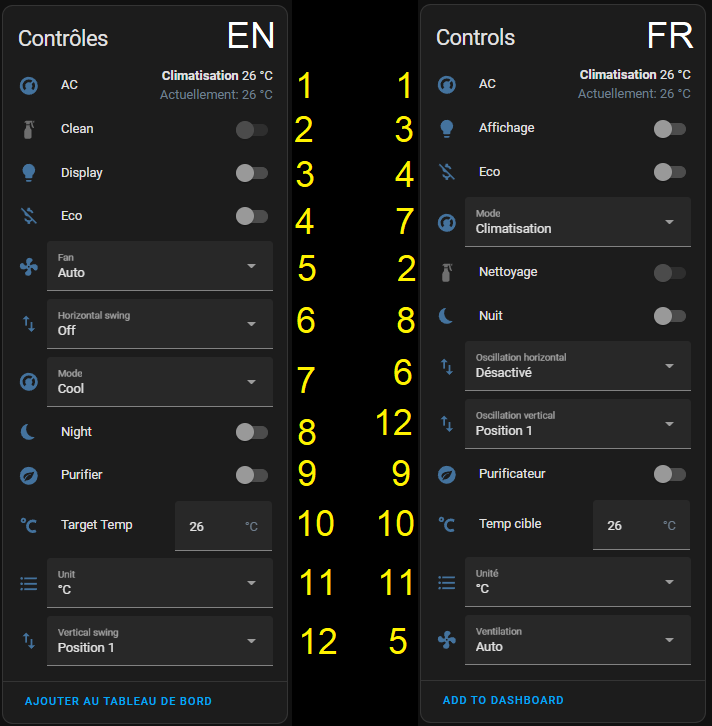
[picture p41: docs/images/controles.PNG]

controls

| #  | Description |
|---:|---|
| 1  | Climate (configured in section below) |
| 2  | Clean option — available when AC is off |
| 3  | Display option |
| 4  | Eco option — available when mode is "cool" and AC is on |
| 5  | Fan speed — available when AC is on and eco is off |
| 6  | Horizontal swing (select) |
| 7  | AC mode (select) |
| 8  | Night mode — available when mode is cool/dry/heat and AC is on |
| 9  | Purifier — available when AC is on |
| 10 | Target temperature — unavailable when eco is on or mode is auto |
| 11 | Temperature unit (°C or °F) (select) |
| 12 | Vertical swing (select) |
|  A | Configured presets (see section ⚙️ Configuration) |

---

## 📡 Sensors

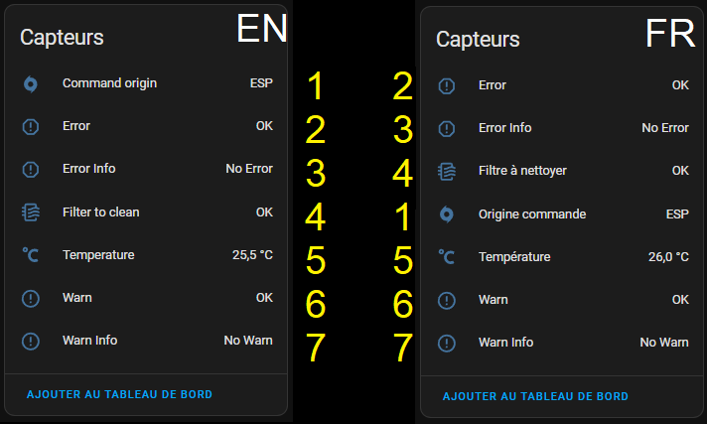
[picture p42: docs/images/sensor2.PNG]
sensor


| #  | Description |
|---:|---|
| 1  | Source of last command — Whether the last command came from the ESP or the remote |
| 2  | AC error detected |
| 3  | AC error info |
| 4  | Filter status — Indicates whether cleaning is needed (`OK` if everything is fine) |
| 5  | Ambient temperature — The current temperature reported by the AC |
| 6  | AC warn detected |
| 7  | AC warn info |

---

## ⚙️ Configuration

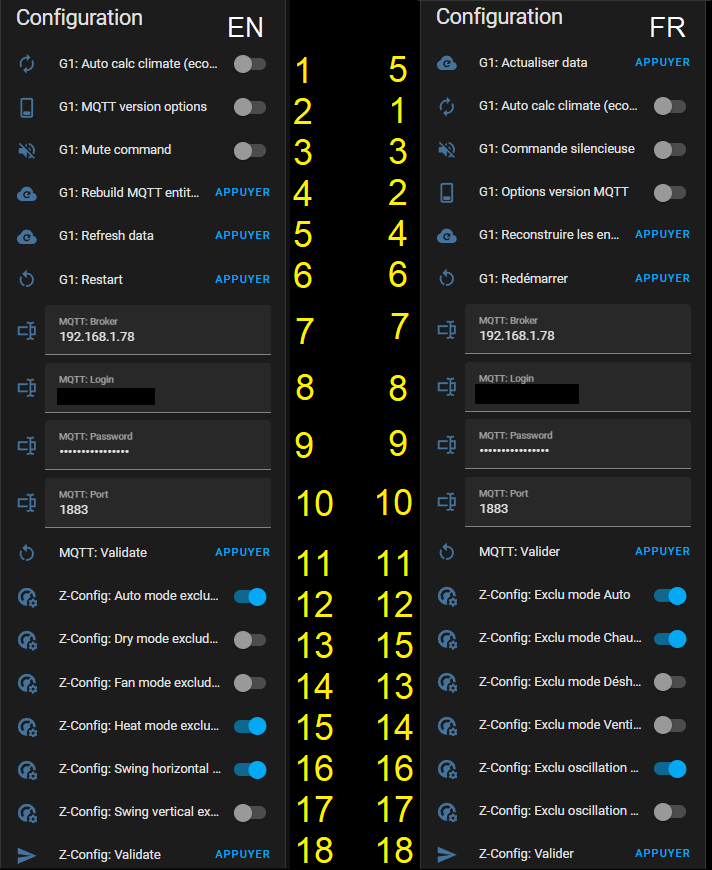
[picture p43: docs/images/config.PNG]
config

config
config
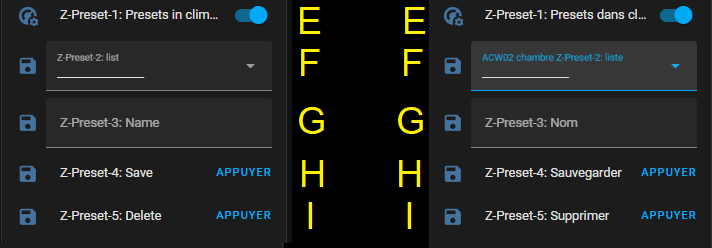
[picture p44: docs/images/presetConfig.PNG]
config


| #  | Description |
|---:|---|
| 1  | Destroy and recreate the Climate entity to reflect options like eco |
| 2  | Enable MQTT version of G1 command, Z-config exclusion and diagnostic (useful if not using ESPHome integration in Home Assistant, or if you want use the module on jeedom) |
| 3  | Mute all commands sent from ESP to the AC (except for clean action) |
| 4  | Destroy and recreate all MQTT entities |
| 5  | Request status update from AC |
| 6  | Restart the ESP |
| 7  |  MQTT IP (auto-saved; the validate button only restarts the ESP) |
| 8  |  MQTT username (auto-saved; the validate button only restarts the ESP) |
| 9  |  MQTT password (auto-saved; the validate button only restarts the ESP) |
| 10 |  MQTT port (auto-saved; the validate button only restarts the ESP) |
| 11 | Restart ESP to apply MQTT access changes |
| 12 | Disable "Auto" mode (auto-saved; validate button will recreate MQTT entities) |
| 13 | Disable "Dry" mode (auto-saved; validate button will recreate MQTT entities) |
| 14 | Disable "Fan only" mode (auto-saved; validate button will recreate MQTT entities) |
| 15 | Disable "Heat" mode (auto-saved; validate button will recreate MQTT entities) |
| 16 | Disable horizontal swing (auto-saved; validate button will recreate MQTT entities) |
| 17 | Disable vertical swing (auto-saved; validate button will recreate MQTT entities) |
| 18 | Manually recreate MQTT entities (to apply disable settings) |
| A  | option for reset or not eco/purifier when ac is turn off |
| B  | publish state delay (in ms) between 2 commands after power on, possible value [0-1000] (max 1s), 0 to disable this feature |
| C  | mute delay (in ms) between 2 commands, possible value [0-60000] (max 60s), 0 to disable this feature |
| D  | mute delay (in ms) between 2 commands after power on, possible value [0-60000] (max 60s), 0 to disable this feature |
| E  | Option to add presets to the climate entity. However, if Swing H is also enabled in the climate entity, it will be disabled |
| F  | Choose a preset from the list to configure |
| G  | Enter a name for the selected preset (limit 22 char) |
| H  | Store the current AC state in the selected preset (warning: if the mute option is enabled, the preset will be saved as muted without enabling mute) |
| I  | Delete the selected preset |

---

## 🧪 Diagnostics

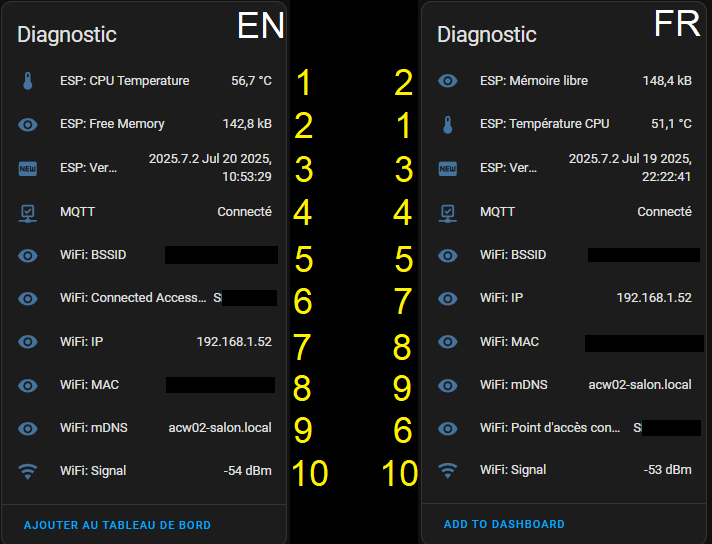
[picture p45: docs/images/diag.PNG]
diag


| #  | Description |
|---:|---|
| 1  | ESP internal temperature |
| 2  | Free memory |
| 3  | ESPHome build version |
| 4  | MQTT connection status |
| 5  | Wi-Fi BSSID |
| 6  | Wi-Fi AP name |
| 7  | Wi-Fi IP address |
| 8  | Wi-Fi MAC address |
| 9  | Local domain name for ESP web access |
| 10 | Wi-Fi signal quality |

---

## 🌐 Web Interface (example access: http://acw02-salon.local/)

### English

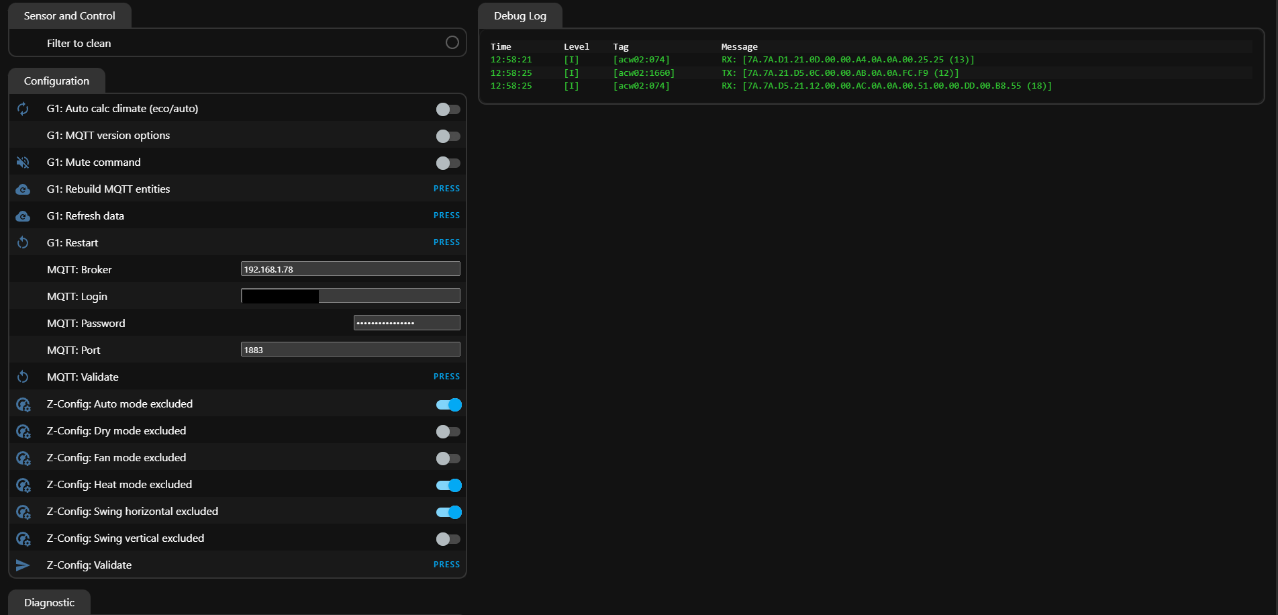
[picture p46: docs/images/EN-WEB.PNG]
weben


### French

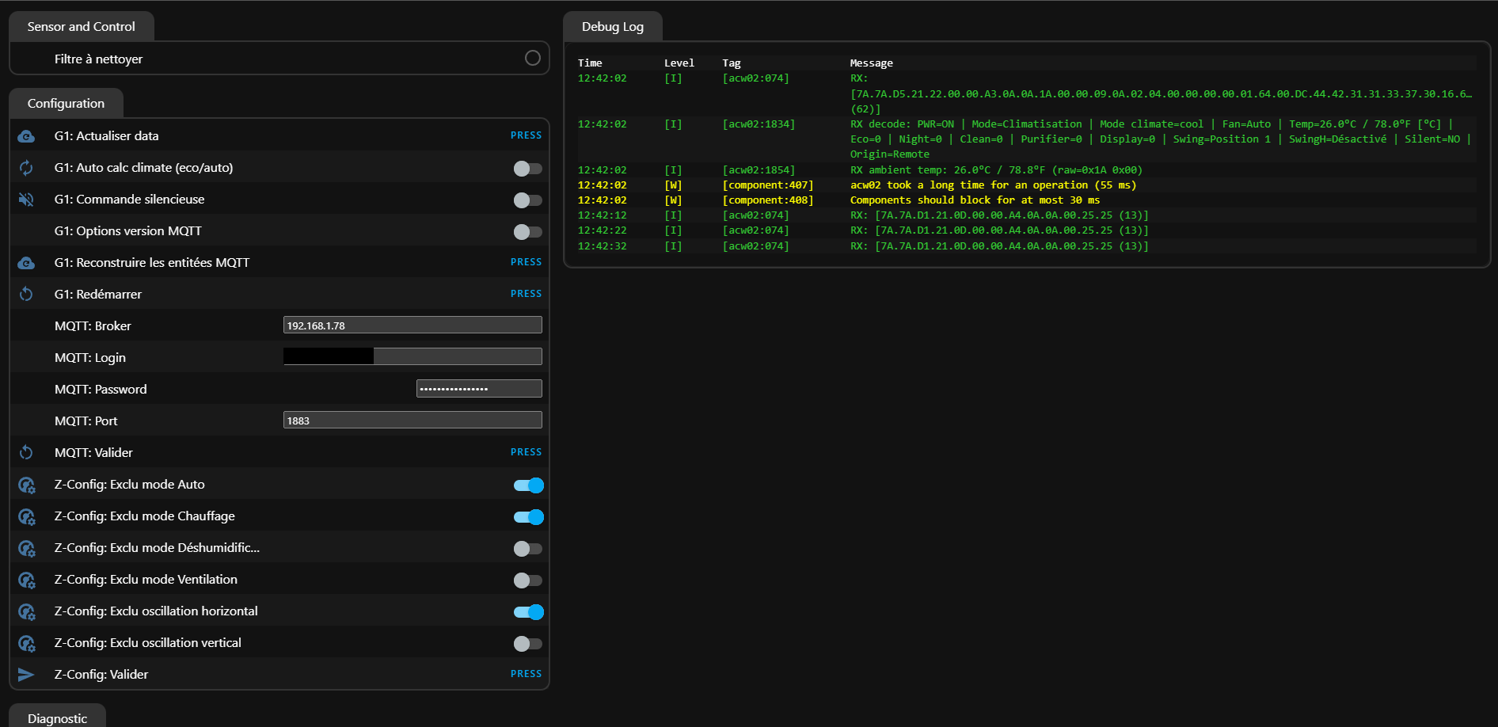
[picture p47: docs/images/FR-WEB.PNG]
webfr


## 🧩 Optional: MQTT Only Without ESPHome HA Integration (ex not connect to ha with esphome or jeedom)

### 📄 In `yaml`

Remove from the `substitutions` section:

```yaml
api_encrypted_key: "D2oldc0VP++fni6src89tCSC0UwBhNPgyc8vgYN8/mA="
```

Remove the entire `api` section:

~~api:~~  
&nbsp;&nbsp;~~encryption:~~  
&nbsp;&nbsp;&nbsp;&nbsp;~~key: ${api_encrypted_key}~~  
&nbsp;&nbsp;~~reboot_timeout: 0s # in test to avoid forcing ESPHome native integration~~

---

After connecting the climate entity, open the web interface (example: [http://acw02-salon.local/](http://acw02-salon.local/)) and configure it like this:

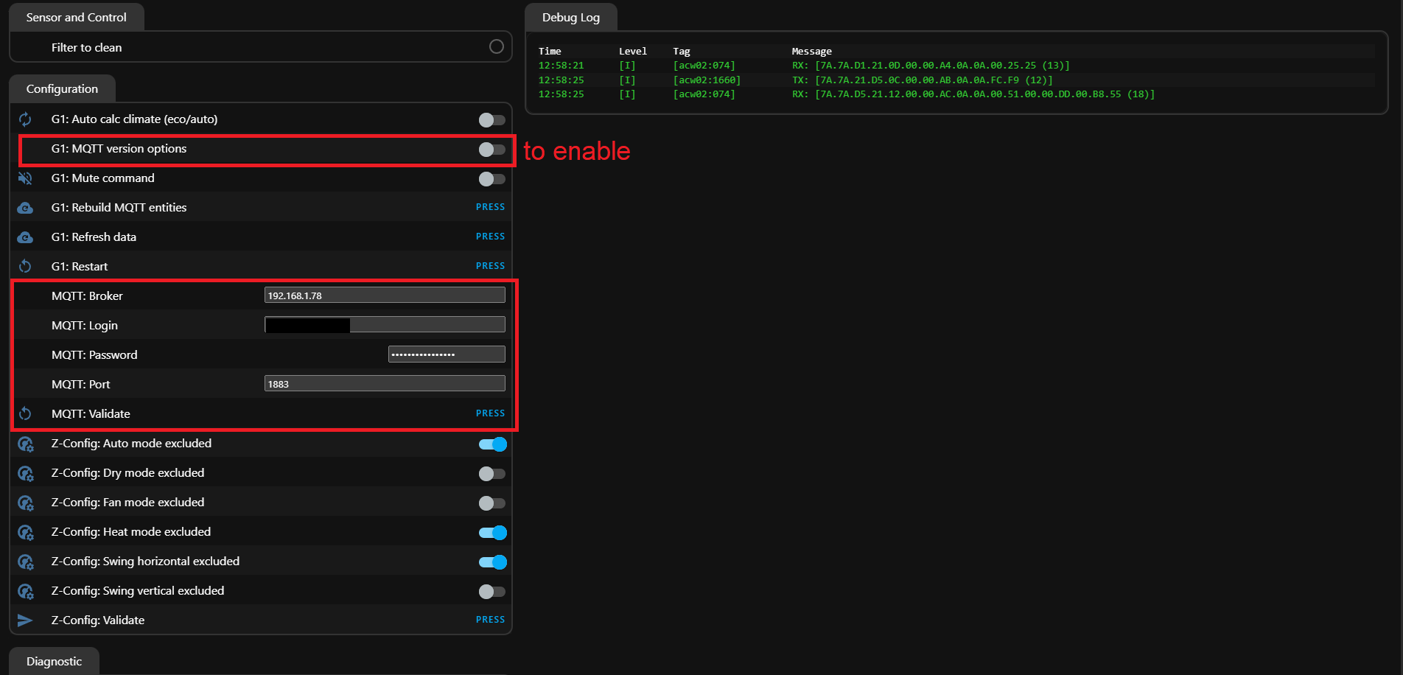
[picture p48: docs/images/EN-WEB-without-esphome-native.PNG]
webennative


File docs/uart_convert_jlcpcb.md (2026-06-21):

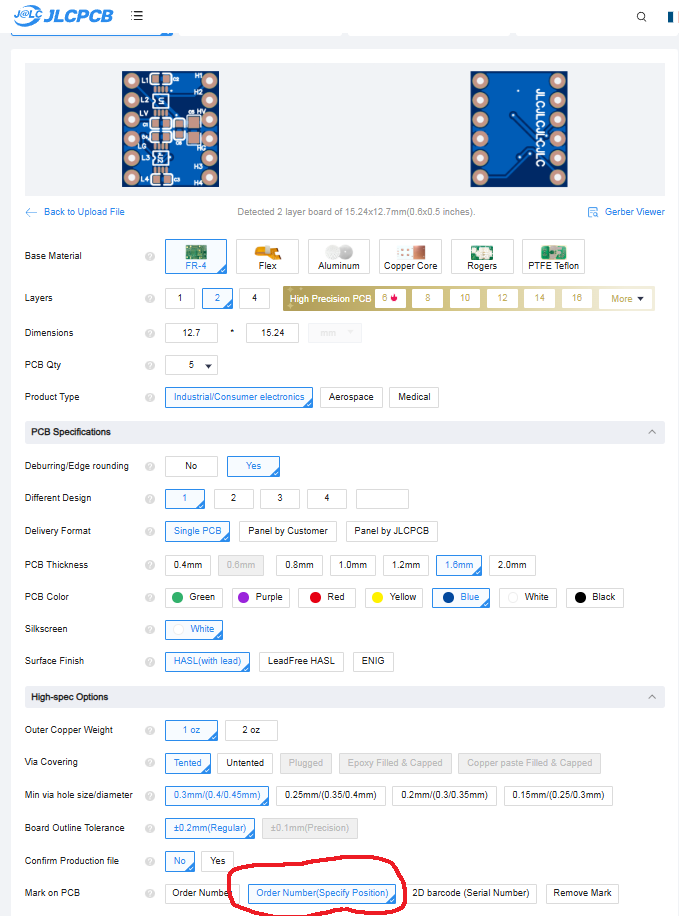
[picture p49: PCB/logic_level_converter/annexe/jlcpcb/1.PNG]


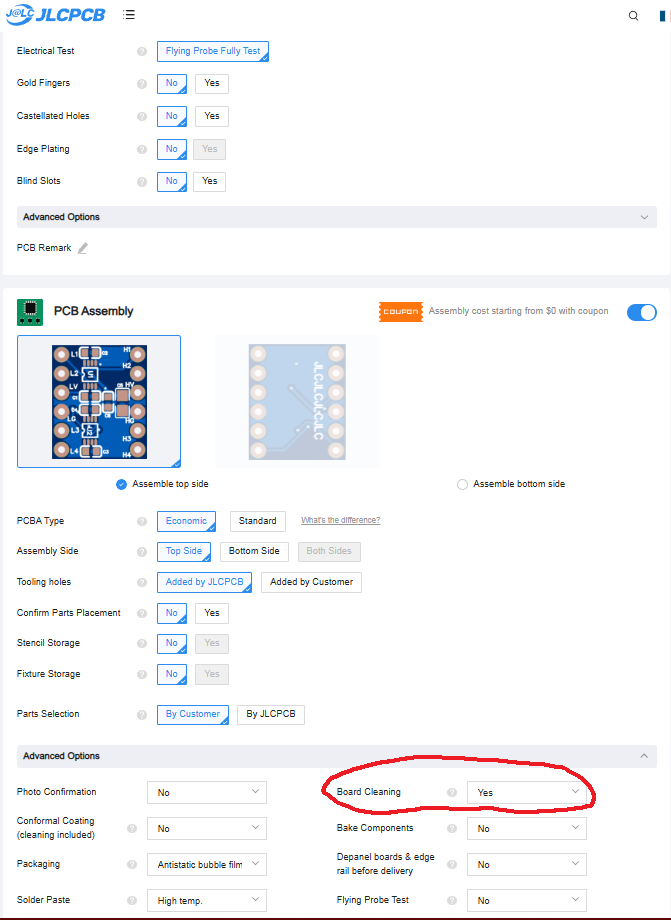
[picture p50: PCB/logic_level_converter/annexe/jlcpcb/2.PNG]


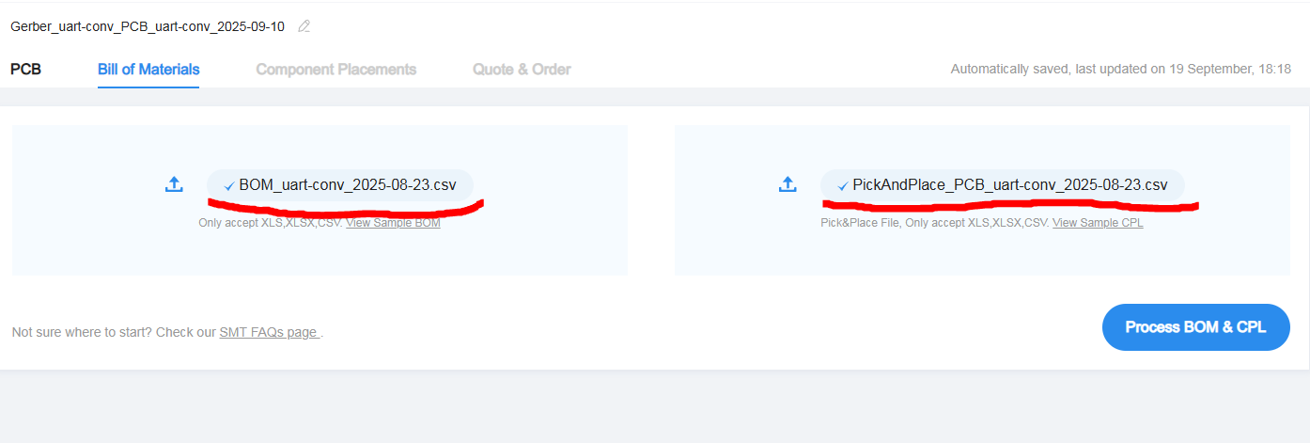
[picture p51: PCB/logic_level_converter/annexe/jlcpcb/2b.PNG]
2b


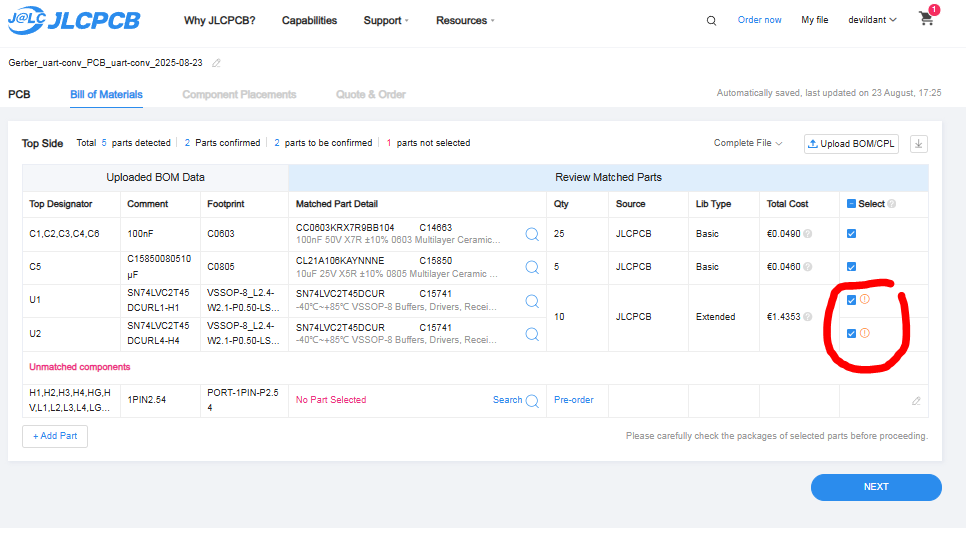
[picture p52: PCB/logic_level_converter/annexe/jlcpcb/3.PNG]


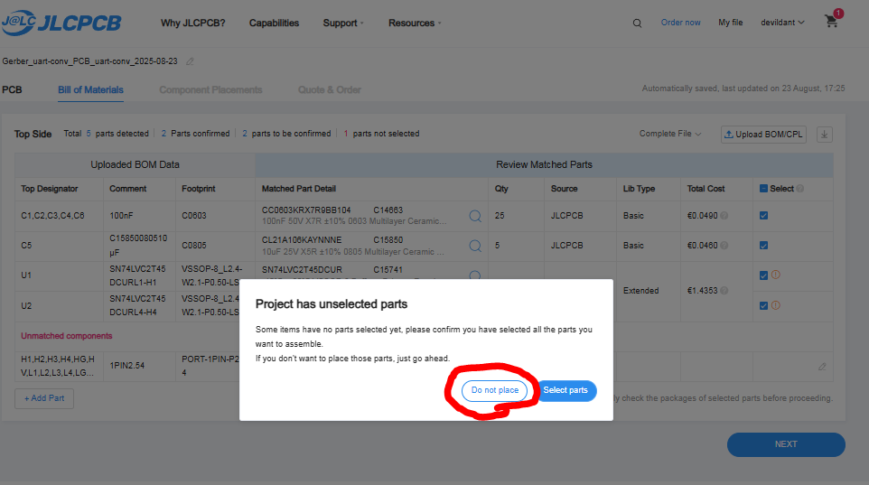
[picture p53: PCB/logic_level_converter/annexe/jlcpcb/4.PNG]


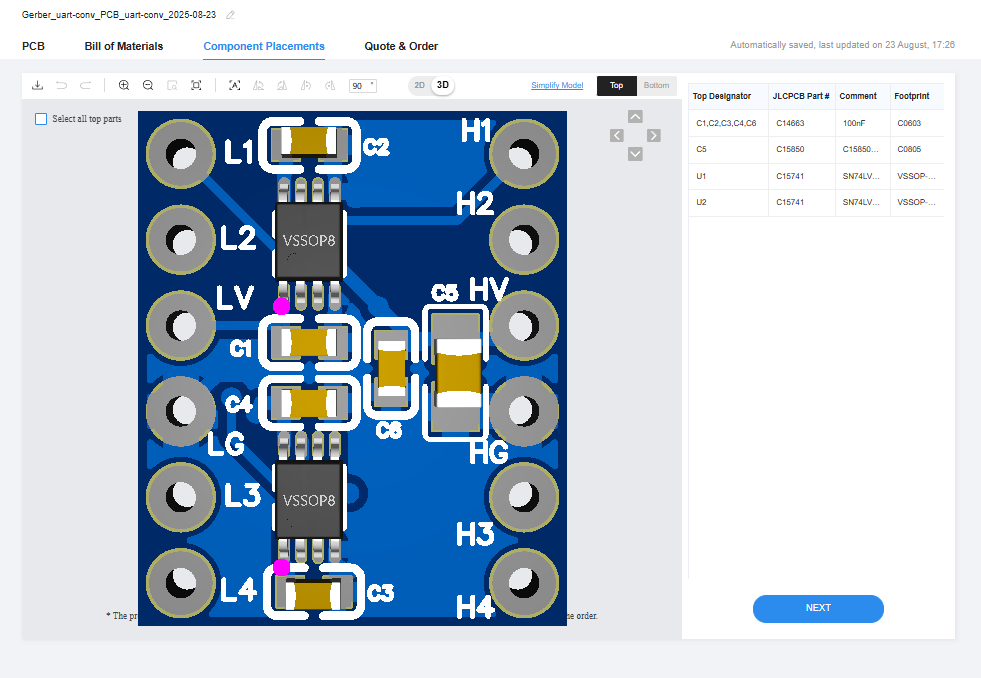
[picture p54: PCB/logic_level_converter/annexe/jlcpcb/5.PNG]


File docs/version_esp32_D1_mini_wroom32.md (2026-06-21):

# ESP32 D1 mini WROOM 32 version
## 🧩 PCB

### 📂 Gerber files available in the `PCB/` directory:

#### 🟢 Stable version (v1.0) :
📥 [Download GERBER file](https://github.com/devildant/acw02_esphome/raw/main/PCB/esp32_D1_mini_wroom32/v1.0/Gerber_climEspHome_esp32_d1_mini_PCB_climEspHome_esp32_d1_mini_2025-07-03.zip)

front  
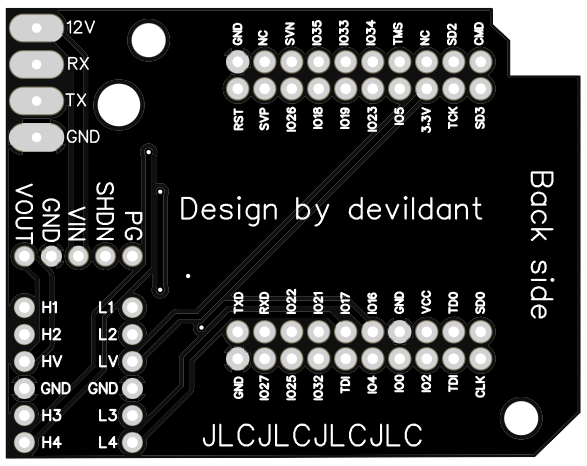
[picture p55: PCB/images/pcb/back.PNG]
back


#### 🟢 Stable version (v1.1) :
📥 [Download GERBER file](https://github.com/devildant/acw02_esphome/raw/main/PCB/esp32_D1_mini_wroom32/v1.1/Gerber_climEspHome_esp32_d1_mini_v1.1_PCB_climEspHome_esp32_d1_mini_v1.1_2025-09-0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)
 
> This revision removes the traces and copper layers under the **ESP32 antenna** to potentially improve Wi-Fi signal.  
> However, since the antenna is already raised above the PCB by the pin headers, the improvement may be negligible.  
> The PCB is **ordered but not yet tested**. 

front  
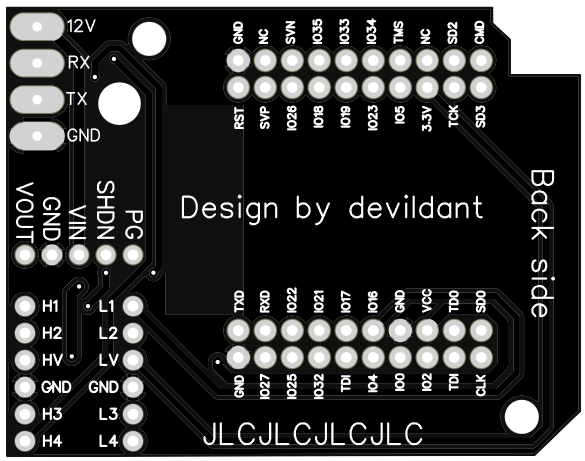
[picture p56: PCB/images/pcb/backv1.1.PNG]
back


---

### 📦 Components

- **[ESP32-WROOM-32 D1 Mini NodeMCU (micro usb version recommended (x1))](https://amzn.eu/d/3mS1B7W)**  
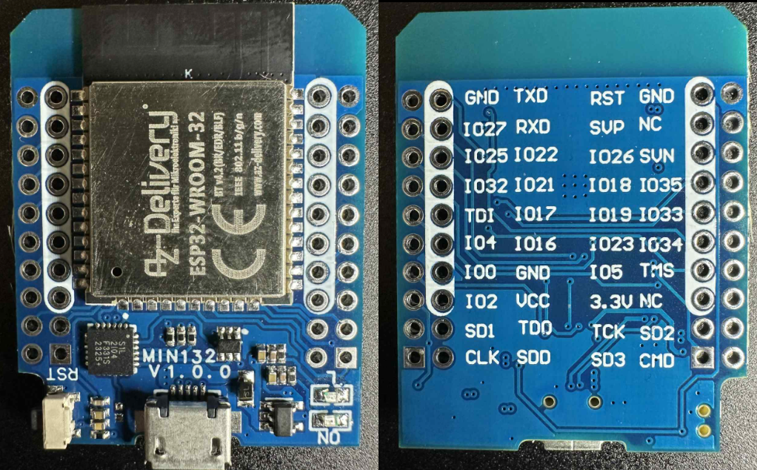
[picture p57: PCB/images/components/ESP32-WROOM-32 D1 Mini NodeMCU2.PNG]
ESP32
  

  > ⚠️ **Compatibility Warning**  
  > Avoid very cheap ESP32 D1 Mini clones (often found on AliExpress).  
  > Several users reported issues with these boards.  
  > Prefer trusted brands such as **AZDelivery** or other well-reviewed suppliers.  

  **❌ Symptoms of low-cost ESP32 incompatibility**  
  - Wi-Fi cannot be enabled on the AC (Wi-Fi logo never appears).  
  - ESP LED turns on briefly, then shuts off.  
  - Voltage on VCC drops from 5 V to ~1.8–2 V when connected to the AC board.  

  **🛠️ Why does this happen?**  
  Cheap ESP32 D1 Mini clones often cut corners in **power regulation** and **stability**:  
  - *Weak 5 V → 3.3 V regulator* — old AMS1117 regulators waste power and cannot handle Wi-Fi current peaks.  
  - *Poor decoupling capacitors* — cheap boards lack the capacitors needed to smooth fast spikes.  
  - *Inconsistent ESP32 modules* — some clones use non-genuine or B-grade chips.  

  **✅ Why AZDelivery & trusted brands work**  
  - Use original **Espressif WROOM-32** modules.  
  - Include a **modern LDO regulator** that tolerates bursts up to 500–600 mA.  
  - Proper capacitors ensure stable operation during Wi-Fi activity.  
  - As a result, even when powered from the AC’s limited 12 V port, they stay stable and connect without issue.

  **🔍 Observation**  
  By comparing ESP32 boards that work and those that don’t, I noticed visible differences.  
  If your ESP has the same configuration as in the image below (red square), it should *theoretically* be compatible.  
  It's just an observation, I don't know how to differentiate the good esp32 d1 mini cards from the bad ones, it's possible that cards with differences work
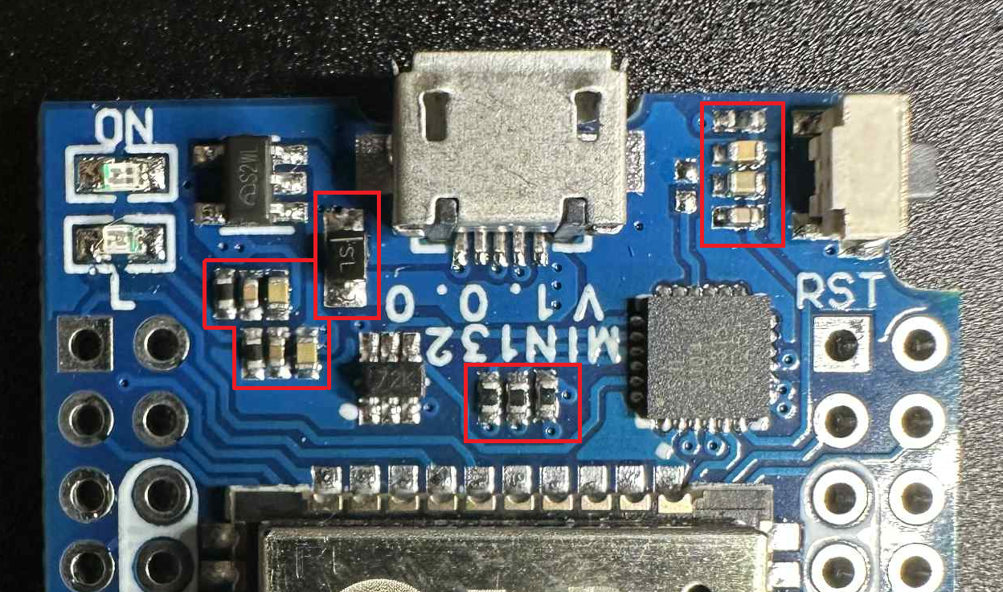
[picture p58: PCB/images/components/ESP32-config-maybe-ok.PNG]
ESP32 config
   

  Note: The images on the official AZDelivery website are not up to date, but they are on Amazon.

- **[10 pins male 2.54mm (x2): MaleL7.5-1X10P](https://fr.aliexpress.com/item/1005007128029220.html)**  
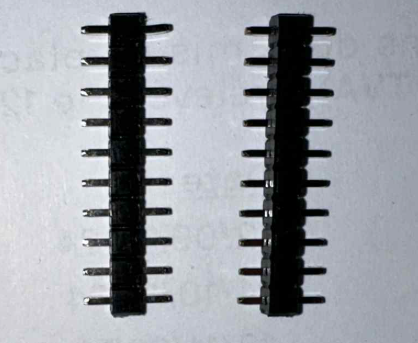
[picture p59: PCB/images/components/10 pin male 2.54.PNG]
MaleL7.5-1X5P
  

  ---
  
  ### 🧵 PCB Soldering & Wiring
  
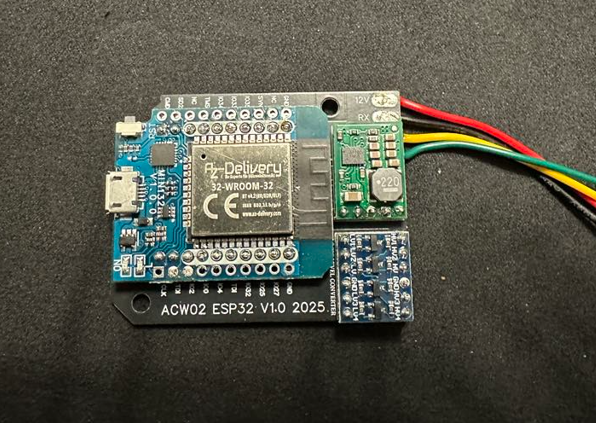
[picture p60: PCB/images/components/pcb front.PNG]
pcb front
    
  
  - RED = 12V  
  - BLACK = RX  
  - YELLOW = TX  
  - GREEN = GND
  
  🔧 Solder pins between ESP32 and PCB (red square):  
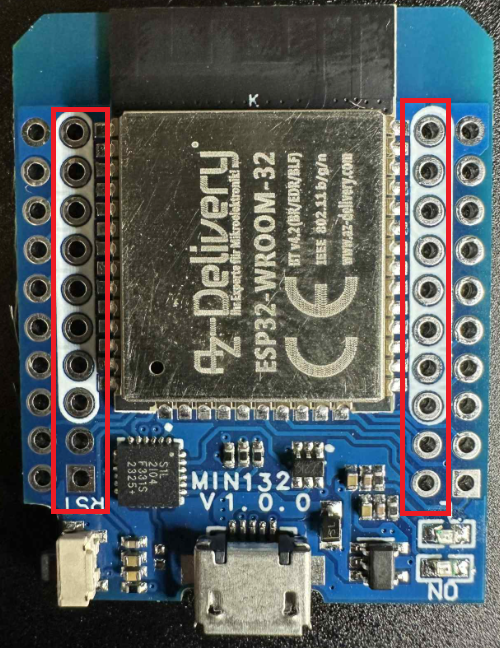
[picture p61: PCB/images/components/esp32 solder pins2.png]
solder
  
  
---

### 🧰 Solder Board Helper

[solder board ESP32 D1 MINI.stl](https://github.com/devildant/acw02_esphome/raw/main/3Dfiles/D1-MIMI/solder%20board%20ESP32%20D1%20MINI.stl)  
solder1  
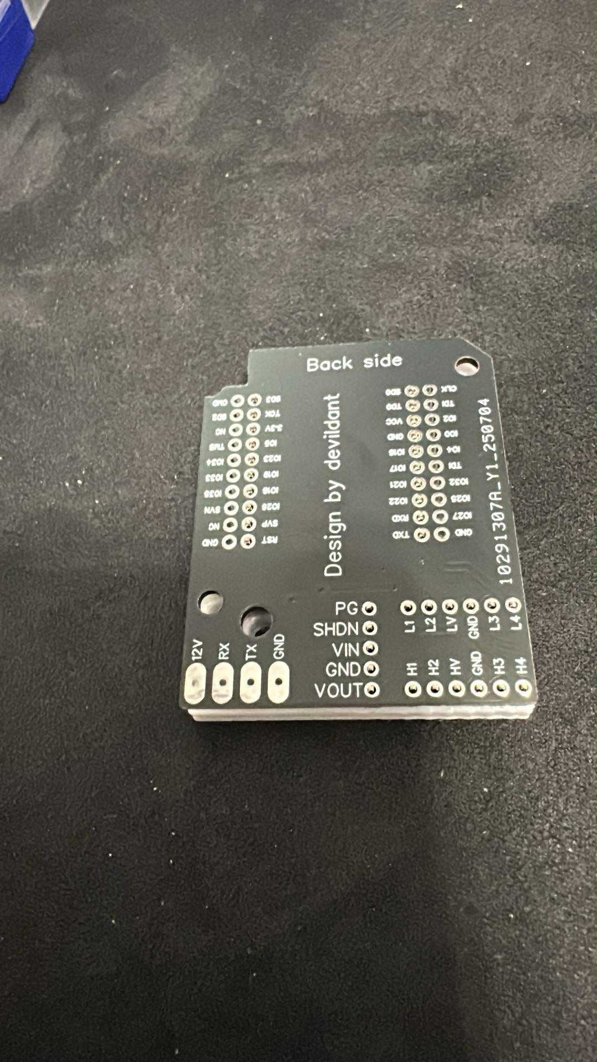
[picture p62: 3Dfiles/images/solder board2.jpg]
solder2


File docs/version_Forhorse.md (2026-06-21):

# Forhorse version
## 🧩 PCB

### 📂 Gerber files available in the `PCB/` directory:

#### Download final files:

📥 [Download GERBER file](https://github.com/devildant/acw02_esphome/raw/refs/heads/main/PCB/Forhorse_acw02_esphome_v2/Gerber_Forhorse_acw02_esphome_v2_1-PCB_PCB_acw02_esphome_2026-06-07.zip)

📥 [Download BOMM](https://github.com/devildant/acw02_esphome/raw/refs/heads/main/PCB/Forhorse_acw02_esphome_v2/BOM_Forhorse_acw02_esphome_v2_2026-06-07.csv)

📥 [Download PickAndPlace](https://github.com/devildant/acw02_esphome/raw/refs/heads/main/PCB/Forhorse_acw02_esphome_v2/PickAndPlace_1-PCB_PCB_acw02_esphome_2026-06-07.csv)

#### Download easyeda file (to import):

📥 [easyeda](https://github.com/devildant/acw02_esphome/raw/refs/heads/main/PCB/Forhorse_acw02_esphome_v2/easyeda/acw02_esphome_v2_2d715029c8f440eeab2c7ecb8ce80326.zip)

front  

---

### 📦 Components

  - **[Connector: JST XA 2.5 male/male 4 pins (standard direction) (x1)](https://www.aliexpress.com/item/1005008857984831.html)** 

  JST order

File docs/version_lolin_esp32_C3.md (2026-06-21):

# LOLIN ESP32 C3 MINI version
## 🧩 PCB

### 📂 Gerber files available in the `PCB/` directory:

#### 🟢 Stable version (v1.0) :
📥 [Download GERBER file](https://github.com/devildant/acw02_esphome/raw/main/PCB/lolin_c3_xiao_c3_xiao_c6/v1.0/Gerber_climEspHome_esp32_lolin_c3_xiao_c3_c6_PCB_climEspHome_esp32_lolin_c3_xia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)

front  
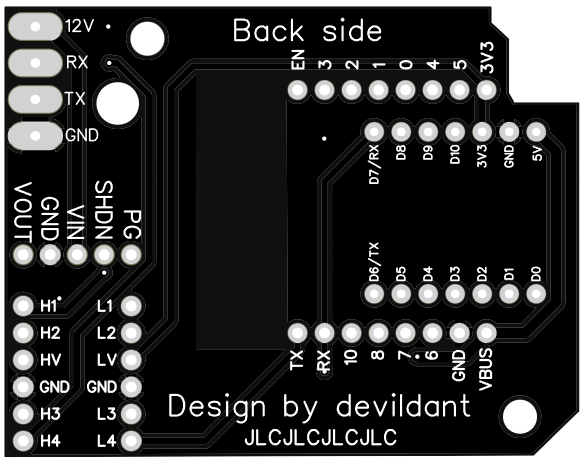
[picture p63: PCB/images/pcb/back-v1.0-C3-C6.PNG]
back


---

### 📦 Components

- **[LOLIN ESP32 C3 mini (x1)](https://www.wemos.cc/en/latest/c3/c3_mini.html)**  
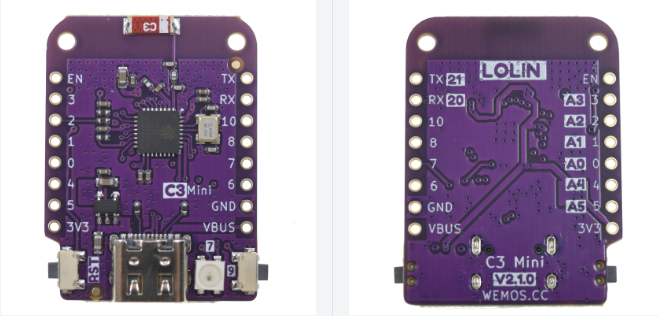
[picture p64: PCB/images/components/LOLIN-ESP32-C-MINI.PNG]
ESP32
  

- **[8 pins male 2.54mm (x2): MaleL7.5-1X8P](https://fr.aliexpress.com/item/1005007128029220.html)**  
  MaleL7.5-1X5P

  ---
  
  ### 🧵 PCB Soldering & Wiring
  
  pcb front  
  
  - RED = 12V  
  - BLACK = RX  
  - YELLOW = TX  
  - GREEN = GND

---

### 🧰 Solder Board Helper

[solder board ESP32 C3-C6.stl](https://github.com/devildant/acw02_esphome/raw/main/3Dfiles/LOLIN-C3-XIAO-C3-C6/solder%20board%20ESP32%20C3-C6.stl)  
solder1  
solder2

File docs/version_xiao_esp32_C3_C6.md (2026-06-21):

# XIAO ESP32 C3-C6 version
## 🧩 PCB

### 📂 Gerber files available in the `PCB/` directory:

#### 🟢 Stable version (v1.0) :
📥 [Download GERBER file](https://github.com/devildant/acw02_esphome/raw/main/PCB/lolin_c3_xiao_c3_xiao_c6/v1.0/Gerber_climEspHome_esp32_lolin_c3_xiao_c3_c6_PCB_climEspHome_esp32_lolin_c3_xia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)

front  
back

---

### 📦 Components

- **[ESP32 xiao C3 or C6 (x1)]**
  - **[LOLIN ESP32 C3 (x1)](https://www.seeedstudio.com/Seeed-XIAO-ESP32C3-p-5431.html)**  
  ESP32
  - **[LOLIN ESP32 C6 (x1)](https://www.seeedstudio.com/Seeed-Studio-XIAO-ESP32C6-p-5884.html)**  
  ESP32
    - **[external antenna (for c6 only because not provide, and internal antenna has very poor reception) (x1)](https://www.seeedstudio.com/2-4GHz-FPC-Antenna-2-9dBi-for-XIAO-ESP32C3-p-6439.html)**  
    ESP32

- **[7 pins male 2.54mm (x2): MaleL7.5-1X7P](https://fr.aliexpress.com/item/1005007128029220.html)**  
  MaleL7.5-1X5P

  ---
  
  ### 🧵 PCB Soldering & Wiring
  
  pcb front xiao c3  
  pcb front xiao c6  
  
  - RED = 12V  
  - BLACK = RX  
  - YELLOW = TX  
  - GREEN = GND

---

### 🧰 Solder Board Helper

[solder board ESP32 C3-C6.stl](https://github.com/devildant/acw02_esphome/raw/main/3Dfiles/LOLIN-C3-XIAO-C3-C6/solder%20board%20ESP32%20C3-C6.stl)  
solder1  
solder2

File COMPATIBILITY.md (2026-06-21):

# ACW02 ESPHome Compatibility List

_This file is generated from issues labeled `Compatibility`._

## Airton

| Commercial Model | Ref Model | Status | Notes |
|---|---|---|---|
| 409936 | SMVH18B-4B2A3NM(I) | ✅ Yes | Le module fonctionne correctement, il y a bien toutes les fonctions. Par contre, je n'ai pas de jus venant de la clim, j'ai du alimenter le module via le port USB. Je ne sais pas si c'est lié à ma clim ou à ttes les clim de cette référence. |
| 409683 | SMVH12B-2A2A3NH | ✅ Yes | _No response_ |
| 409944 | N/A | ⚠️ Partially (some functions missing) | This AC use the 409945 module, this module use tuya MCU, look this doc  **[ACW02 ESPHome Tuya MCU integration](./docs/TUYA_MCU_SETUP.md)** |
| 409943 | SMVH12L-3A1A3NB(I) | ⚠️ Partially (some functions missing) | This AC use the 409945 module, this module use tuya MCU, look this doc  **[ACW02 ESPHome Tuya MCU integration](./docs/TUYA_MCU_SETUP.md)** |
| 409942 | N/A | ⚠️ Partially (some functions missing) | This AC use the 409945 module, this module use tuya MCU, look this doc  **[ACW02 ESPHome Tuya MCU integration](./docs/TUYA_MCU_SETUP.md)** |
| 409913 | SMVH09B-2A2A3NG | ✅ Yes | _No response_ |
| 409730 | SMVH09B-2A2A3NH(I) | ✅ Yes | _No response_ |
| 409733 | SMVH12B-3A2A3NG(I) | ✅ Yes | _No response_ |
| 409731 | SMVH12B-2A2A3NH(I) | ✅ Yes | _No response_ |

## Teknopoint

| Commercial Model | Ref Model | Status | Notes |
|---|---|---|---|
| TW-SKIV-07 | N-TW-SMVH07A-2C1A3NG(I) | ✅ Yes | _No response_ |
| TW-SKIV-12 | - | ✅ Yes | No ref model found |
| TW-SKIV-12 | N-TW-SMVH12A-3C1A3NG(I) | ✅ Yes | _No response_ |

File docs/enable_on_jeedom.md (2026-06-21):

# ⚡ Activation on Jeedom

## ✅ Prerequisites
- 🔌 **MQTT Broker plugin** must be installed  
- 🧭 **MQTT Discovery plugin** *(optional but highly recommended)*  

---

## 1️⃣ Installing MQTT Discovery
1. 📥 Install the plugin  
2. ▶️ Activate it  
3. ⚙️ Configure (automatic if you already use **MQTT Manager**)  
4. 🔎 In the plugin, enable **Automatic Discovery**  
   - Or manually add your ESP topic → `dev_name` (e.g. `acw02-salon`)  

---

## 2️⃣ From ESP Web Interface
- 🌐 Configure your **MQTT broker**  
  👉 See the [Specific Jeedom Documentation](https://github.com/devildant/acw02_esphome/blob/main/docs/interface_details.md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) for details.  

---

## 3️⃣ From Jeedom
- ✅ Check that the module was **automatically added**  
  jeedom discovery  

- 👀 View the available **commands**  
  jeedom commands  

- 👀 **Module**  
jeedom module

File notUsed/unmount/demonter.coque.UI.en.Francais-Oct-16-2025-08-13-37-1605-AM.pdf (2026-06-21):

Manuel démontage coque complète Unité Int.

Déballage et dévissage de la petite vis en façade sous le petit cache


Ouvrir le capot


Dévisser le cache câble


Détacher le capot en appuyant sur les guides


Dévisser l'afficheur LCD
Et le détacher en declipsant a l'aide du tournevis plat


Dévisser le capot en plastic de l'unité intérieure (4 vis en façade)

Déclipser le capot en plastic de l'unité (partie haute - 4 clips)


Soulever et désolidariser le capot


Démonter le cache de la carte mère

Déclipser le fil jaune du capteur de température


Déclipser le cache carte mère
En appuyant sur le clipse au-dessus et en écartant celui sur le côté en même temps à l'aide un tournevis plat



Le cache devrait sortir sans effort


Déloger les câbles du passe-câble pour pouvoir sortir la carte mère



# Etape pour remontage de la Coque Complete UI

Reloger la carte mère ,ranger les câbles dans le passe-câble


Remettre le capot de l'unité intérieure et le reclipser


Revisser et reclipser l'ensemble des 5 vis en façade


Revisser le cache


Refixer et revisser l'afficheur LCD sur son logement derrière le capot amovible



Réinstaller le capot amovible



Merci de respecter les étapes

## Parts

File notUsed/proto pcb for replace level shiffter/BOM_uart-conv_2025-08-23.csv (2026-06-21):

ID | Name | Designator | Footprint | Quantity | Manufacturer Part | Manufacturer | Supplier | Supplier Part | Price | JLCPCB Part Class
1 | SN74LVC2T45DCUR L1-H1 | U1 | VSSOP-8_L2.4-W2.1-P0.50-LS3.2-BR | 1 | SN74LVC2T45DCUR | TI(德州仪器) | LCSC | C15741 | 0.172 | C15741
2 | SN74LVC2T45DCUR L4-H4 | U2 | VSSOP-8_L2.4-W2.1-P0.50-LS3.2-BR | 1 | SN74LVC2T45DCUR | TI(德州仪器) | LCSC | C15741 | 0.172 | C15741
3 | 1 PIN 2.54 | H1,H2,H3,H4,HG,HV,L1,L2,L3,L4,LG,LV | PORT-1PIN-P2.54 | 12
4 | C15850 0805 10µF | C5 | C0805 | 1 | CL21A106KAYNNNE | SAMSUNG(三星) | LCSC | C15850 | 0.011 | Basic Part
5 | 100nF | C1,C2,C3,C4,C6 | C0603 | 5 | CC0603KRX7R9BB104 | YAGEO(国巨) | LCSC | C14663 | 0.002 | Basic Part

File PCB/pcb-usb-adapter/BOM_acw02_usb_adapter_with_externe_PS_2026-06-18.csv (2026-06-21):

ID | Name | Designator | Footprint | Quantity | Manufacturer Part | Manufacturer | Supplier | Supplier Part | Price
1 | S04B-XASK-1(LF)(SN) | J1 | CONN-TH_S04B-XASK-1-LF-SN | 1 | S04B-XASK-1(LF)(SN) | JST | LCSC | C265097 | 0.227
2 | U-G-04DD-W-01 | USB2 | USB-A-TH_U-G-04WD-W-01 | 1 | U-G-O4DD-W-1 | 韩国韩荣 | LCSC | C98125 | 0.113
3 | 1 PIN 2.54 | GND,VCC | PORT-1PIN-P2.54 | 2

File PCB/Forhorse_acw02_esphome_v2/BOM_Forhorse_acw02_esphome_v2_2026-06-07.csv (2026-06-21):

ID | Name | Designator | Footprint | Quantity | Manufacturer Part | Manufacturer | Supplier | Supplier Part | Price
1 | SS34_C8678 | D1 | SMA_L4.3-W2.6-LS5.2-RD | 1 | SS34 | MDD(辰达半导体) | LCSC | C8678 | 0.03
2 | TS-1088-AR02016 | BOOT | SW-SMD_L3.9-W3.0-P4.45 | 1 | TS-1088-AR02016 | XUNPU(讯普) | LCSC | C720477 | 0.057
3 | 47uF | C4,C5 | C1206 | 2 | CL31A476MPHNNNE | SAMSUNG(三星) | LCSC | C96123 | 0.142
4 | 10uF | C7,C8 | C1206 | 2 | CL31A106KBHNNNE | SAMSUNG(三星) | LCSC | C13585 | 0.093
5 | 100nF | C16,C1,C2,C12,C13,C15,C19 | C0402 | 7 | CL05B104KO5NNNC | SAMSUNG(三星) | LCSC | C1525 | 0.002
6 | 100nF | C9 | C0402 | 1 | CL05B104KB54PNC | SAMSUNG(三星) | LCSC | C307331 | 0.007
7 | 150pF | C10 | C0603 | 1 | 0603B151K500NT | FH(风华) | LCSC | C1594 | 0.004
8 | 10uF | C14,C18,C20 | C0603 | 3 | CL10A106KP8NNNC | SAMSUNG(三星) | LCSC | C19702 | 0.015
9 | 1uF | C17 | C0603 | 1 | CL10A105KB8NNNC | SAMSUNG(三星) | LCSC | C15849 | 0.011
10 | 0805G (Green) | PWR | LED0805-R-RD | 1 | KT-0805G | KENTO | LCSC | C2297 | 0.016
11 | KT-0603R | STA | LED0603-RD | 1 | KT-0603R | KENTO | LCSC | C2286 | 0.007
12 | 1N5819WS | D2 | SOD-323_L1.8-W1.3-LS2.5-RD | 1 | 1N5819WS | Hottech(合科泰) | LCSC | C191023 | 0.011
13 | 10nF | C3 | C0603 | 1 | 0603B103K500NT | FH(风华) | LCSC | C57112 | 0.008
14 | 2.7nF | C6 | C0603 | 1 | GRM1885C1H272JA01D | muRata(村田) | LCSC | C77034 | 0.025
15 | 56nF | C11 | C0603 | 1 | CC0603KRX7R9BB563 | YAGEO(国巨) | LCSC | C282072 | 0.005
16 | USBLC6-2SC6 | D3 | SOT-23-6_L2.9-W1.6-P0.95-LS2.8-BL | 1 | USBLC6-2SC6 | ST(意法半导体) | LCSC | C7519 | 0.154
17 | S04B-XASK-1(LF)(SN) | J1 | CONN-TH_S04B-XASK-1-LF-SN | 1 | S04B-XASK-1(LF)(SN) | JST | LCSC | C265097 | 0.226
18 | 2.54mm 1*5P Header | J2 | HDR-TH_5P-P2.54-V-M | 1 | 2.54mm 1*5P Header | ReliaPro | LCSC | C50951
19 | DS1021-1X6SF11-B | J3 | CONN-TH_DS1021-1X6SF11-B | 1 | DS1021-1x6SF11-B | CONNFLY | LCSC | C7430362 | 0.031
20 | B2B-XH-A (LF)(SN) | J4 | CONN-TH_B2B-XH-A-LF-SN | 1 | B2B-XH-A(LF)(SN) | JST | LCSC | C158012 | 0.04
21 | 68uH | L1 | IND-SMD_L4.0-W4.0_FNR40XXS | 1 | FNR4030S680MT | cjiang(长江微电) | LCSC | C167892 | 0.079
22 | AO3401A | Q1 | SOT-23_L2.9-W1.3-P1.90-LS2.4-BR | 1 | AO3401A | AOS | LCSC | C15127 | 0.072
23 | 10kΩ | R1,R5,R7,R8,R12 | R0603 | 5 | 0603WAF1002T5E | UNI-ROYAL(厚声) | LCSC | C25804 | 0.003
24 | 1.78kΩ | R2 | R0603 | 1 | 0603WAF1781T5E | UNI-ROYAL(厚声) | LCSC | C22849 | 0.001
25 | 3.24kΩ | R3 | R0603 | 1 | 0603WAF3241T5E | UNI-ROYAL(厚声) | LCSC | C22994 | 0.002
26 | 100kΩ | R4 | R0603 | 1 | 0603WAF1003T5E | UNI-ROYAL(厚声) | LCSC | C25803 | 0.002
27 | 22Ω | R9,R10 | R0603 | 2 | 0603WAF220JT5E | UNI-ROYAL(厚声) | LCSC | C23345 | 0.002
28 | 5.1kΩ | R11,R13 | R0603 | 2 | 0603WAF5101T5E | UNI-ROYAL(厚声) | LCSC | C23186 | 0.002
29 | 2.2kΩ | R14,R6 | R0603 | 2 | 0603WAF2201T5E | UNI-ROYAL(厚声) | LCSC | C4190 | 0.002
30 | TS24CA | RST | SW-SMD_2P-TS24CA | 1 | TS24CA | SHOU HAN(首韩) | LCSC | C393942 | 0.025
31 | 74LVC1T45W6-7 | U1,U3 | SOT-23-6_L2.9-W1.6-P0.95-LS2.8-BR | 2 | 74LVC1T45W6-7 | DIODES(美台) | LCSC | C168856 | 0.097
32 | TPS5410DR | U2 | SOIC-8_L5.0-W4.0-P1.27-LS6.0-BL | 1 | TPS5410DR | TI(德州仪器) | LCSC | C28867 | 0.743
33 | ESP32-C3-WROOM-02-N4(4MB) | U4 | BULETM-SMD_ESPRESSIF_ESP32-C3-WROOM-02-N4-4MB | 1 | ESP32-C3-WROOM-02-N4 | ESPRESSIF(乐鑫) | LCSC | C2934560 | 3.133
34 | ME6211C33M5G-N | U5 | SOT-23-5_L3.0-W1.7-P0.95-LS2.8-BL | 1 | ME6211C33M5G-N | MICRONE(南京微盟) | LCSC | C82942 | 0.051
35 | TYPE-C 16PIN 2MD(073) | USB1 | USB-C-SMD_TYPE-C-6PIN-2MD-073 | 1 | TYPE-C 16PIN 2MD(073) | SHOU HAN(首韩) | LCSC | C2765186 | 0.074

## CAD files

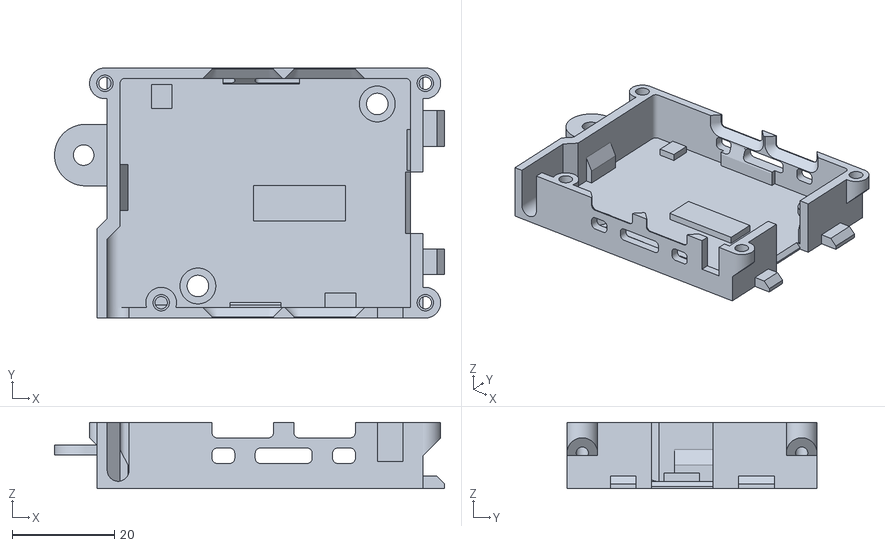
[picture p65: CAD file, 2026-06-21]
3Dfiles/full pcb by Forhorse/full pcb acw02 case bot with air flow.stl
76.2 x 48.9 x 12.9

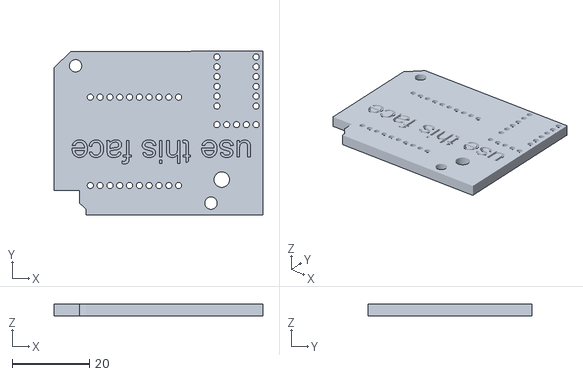
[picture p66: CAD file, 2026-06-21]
3Dfiles/D1-MIMI/solder board ESP32 D1 MINI.stl
54.1 x 42.4 x 3.00

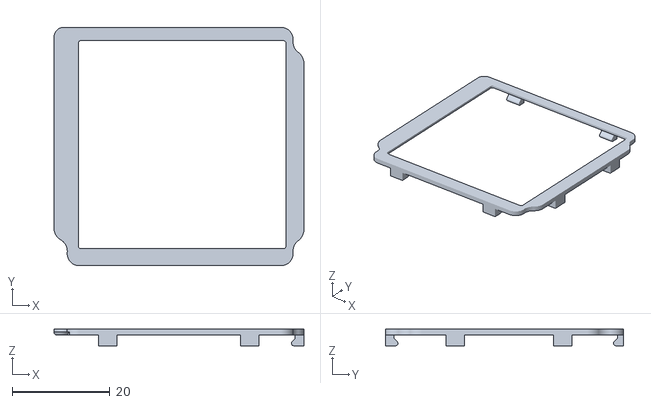
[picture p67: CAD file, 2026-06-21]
3Dfiles/D1-MIMI/Version 2/card.stl
51.2 x 48.8 x 3.40

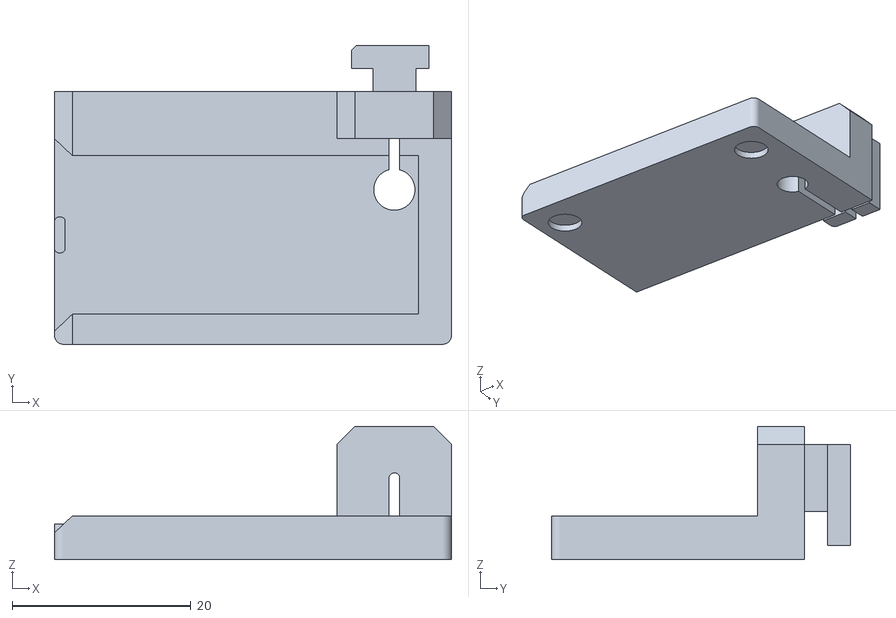
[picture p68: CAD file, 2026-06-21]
3Dfiles/LOLIN-C3-XIAO-C3-C6/support antenna flex horizontal.stl
44.4 x 33.4 x 14.9

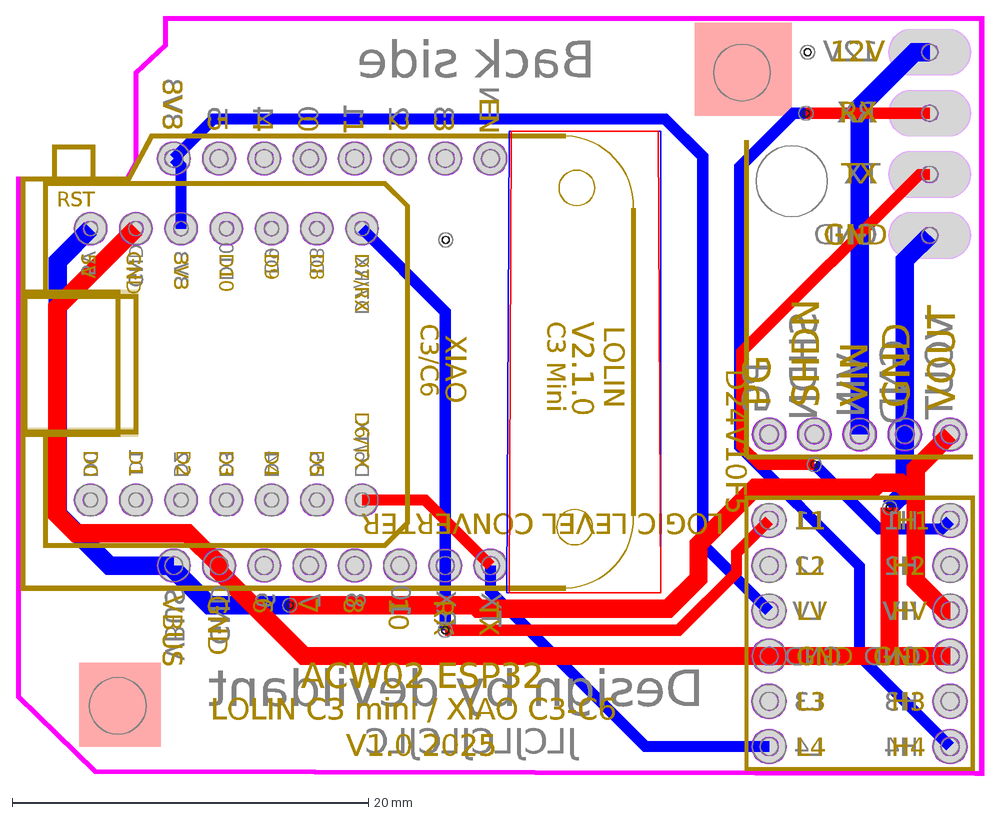
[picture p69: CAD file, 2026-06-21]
notUsed/pcb lolin c3 mini - xiao C3-C6/PCB_climEspHome_esp32_lolin_c3_xiao_c3_c6_2025-09-13.dxf
H1
H2
HV
GND
H3
H4
L4
L3
LV
L2
L1
VOUT
VIN
SHDN
PG
12V
RX
TX
Back side
Design by devildant
JLCJLCJLCJLC
EN
3
2
1
0
4
5
3V3
VBUS
6
7
8
10
D7/RX
D8
D9
D10
5V
D0
D1
D2
D3
D4
D5
D6/TX
ACW02 ESP32
V2.1.0
V1.0 2025
C3/C6
LOLIN C3 mini / XIAO C3-C6
XIAO
LOLIN
C3 Mini
RST
D24V10F5
LOGIC LEVEL CONVERTER

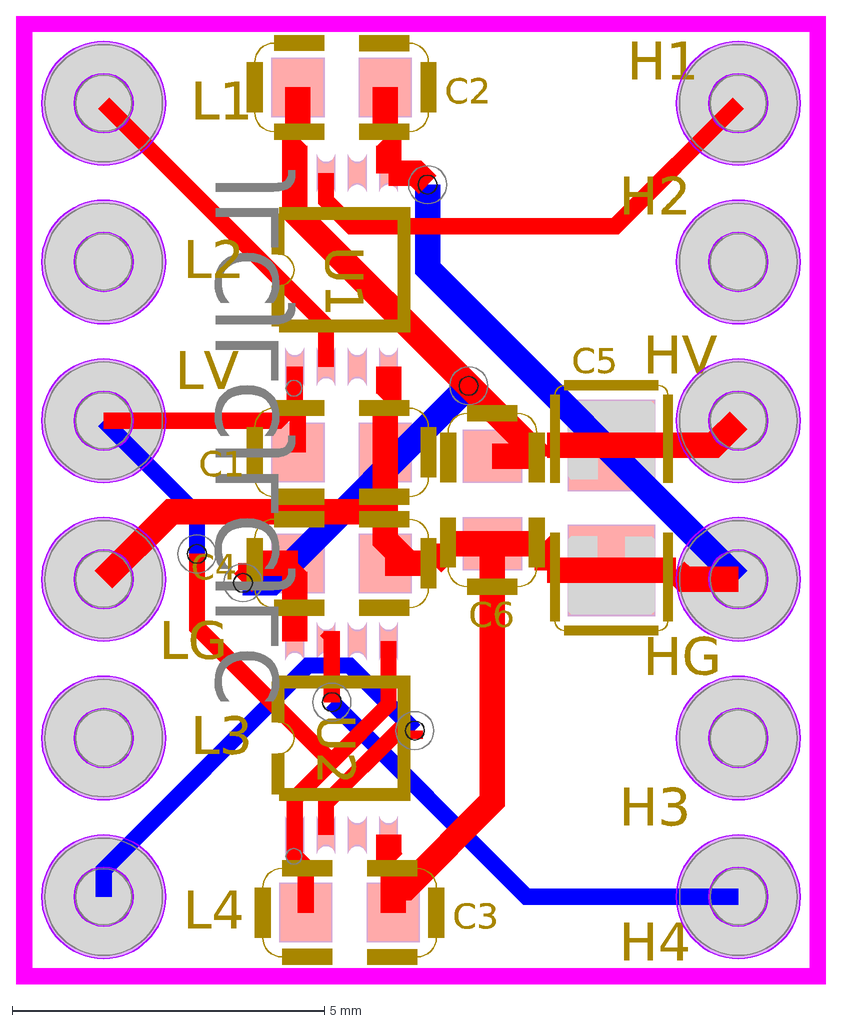
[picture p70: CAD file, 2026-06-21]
notUsed/proto pcb for replace level shiffter/annexe/PCB_uart-conv_2025-08-23.dxf
JLCJLCJLCJLC
U1
U2
H1
H2
H3
H4
HG
HV
L1
L2
L3
L4
LG
LV
C5
C1
C2
C3
C4
C6

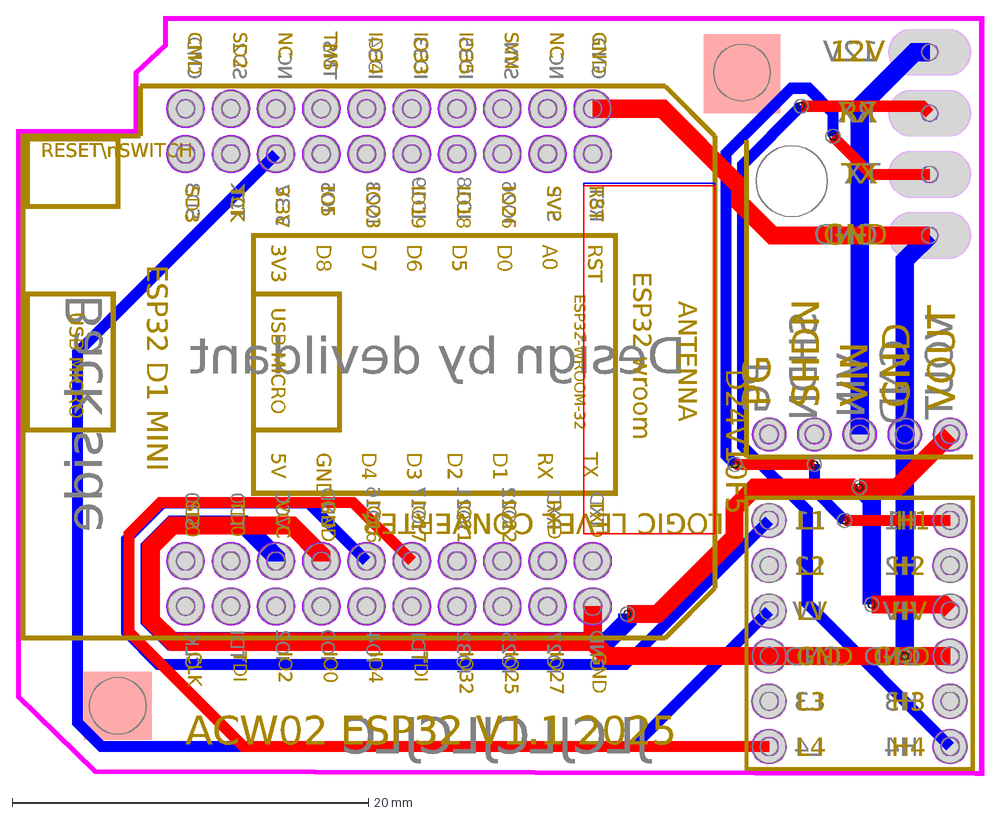
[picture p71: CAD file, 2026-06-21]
PCB/esp32_D1_mini_wroom32/v1.1/dxf/PCB_climEspHome_esp32_d1_mini_v1.1_2025-09-08.dxf
H1
H2
HV
GND
H3
H4
L4
L3
LV
L2
L1
VOUT
VIN
SHDN
PG
12V
RX
TX
IO27
IO25
IO32
TDI
IO4
IO0
IO2
CLK
SD0
TD0
VCC
IO16
IO17
IO21
IO22
RXD
TXD
Back side
Design by devildant
NC
SVN
IO35
IO33
IO34
TMS
SD2
CMD
SD3
TCK
3.3V
IO5
IO23
IO19
IO18
IO26
SVP
RST
JLCJLCJLCJLC
ACW02 ESP32 V1.1 2025
D24V10F5
LOGIC LEVEL CONVERTER
ESP32 D1 MINI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

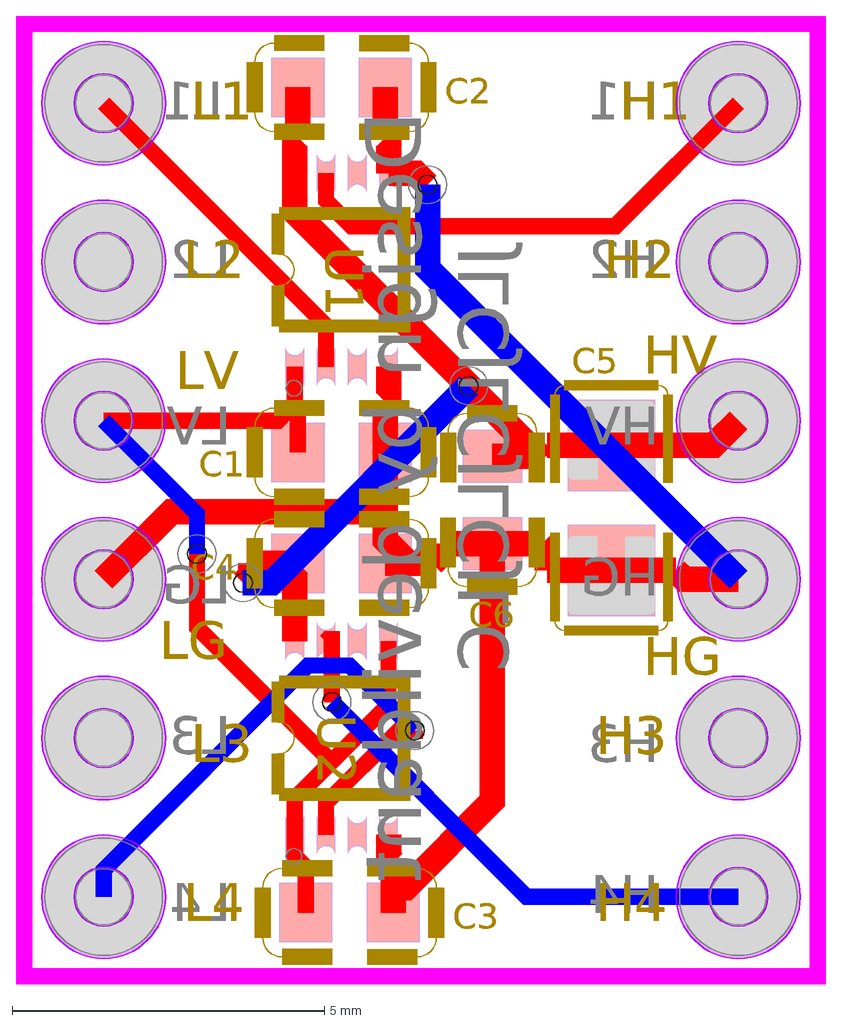
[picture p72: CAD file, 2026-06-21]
PCB/logic_level_converter/annexe/PCB_uart-conv_2025-09-10.dxf
JLCJLCJLCJLC
Design by devildant
HV
H2
H1
HG
H3
H4
L4
L3
LG
LV
L2
L1
U1
U2
C5
C1
C2
C3
C4
C6

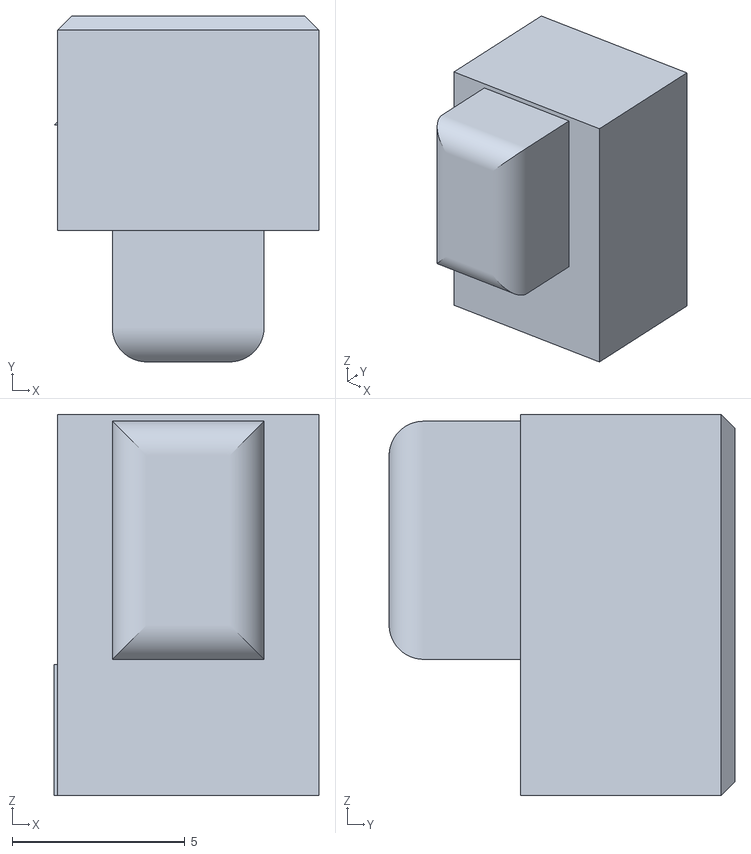
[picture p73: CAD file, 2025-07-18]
3Dfiles/D1-MIMI/button.stl
7.67 x 10.0 x 11.0

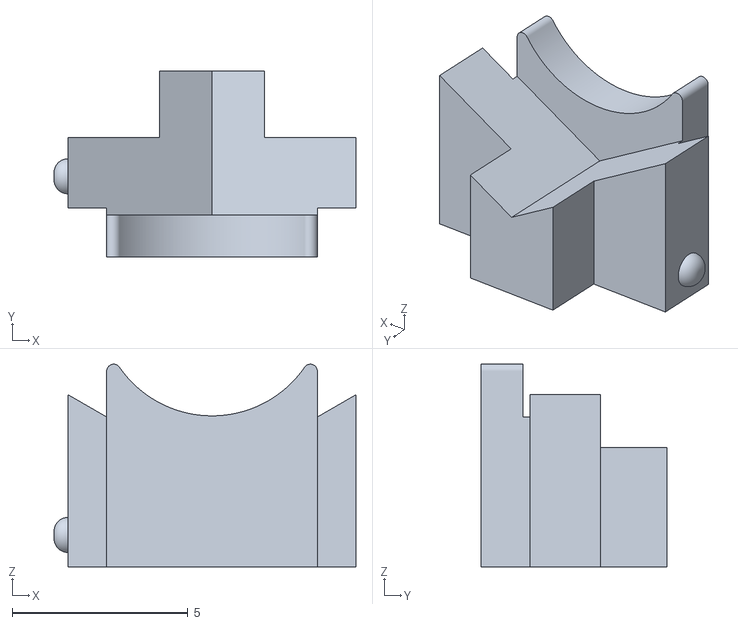
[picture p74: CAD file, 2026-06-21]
3Dfiles/LOLIN-C3-XIAO-C3-C6/support antenna rigid part B.stl
8.60 x 5.30 x 5.77

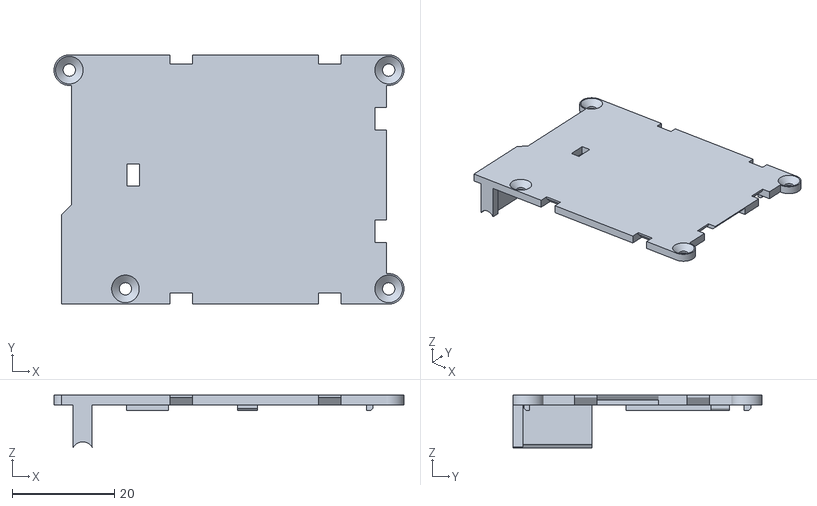
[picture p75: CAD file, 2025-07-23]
3Dfiles/D1-MIMI/Version 2/acw02 case top plastic card.stl
68.6 x 48.9 x 10.4

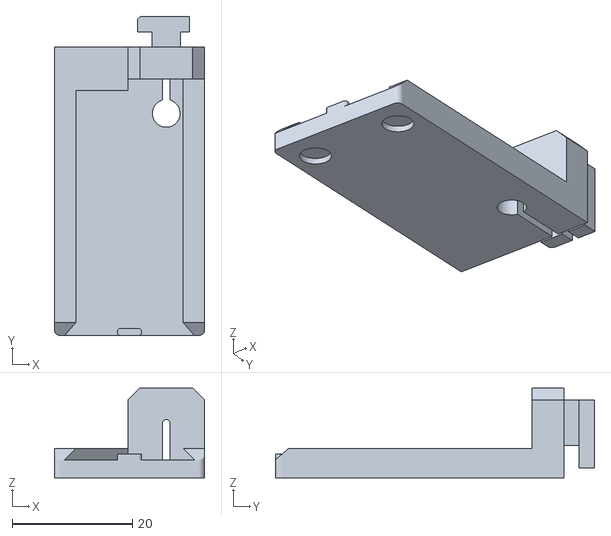
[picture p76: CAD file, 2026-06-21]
3Dfiles/LOLIN-C3-XIAO-C3-C6/support antenna flex vertical.stl
25.0 x 53.0 x 14.9

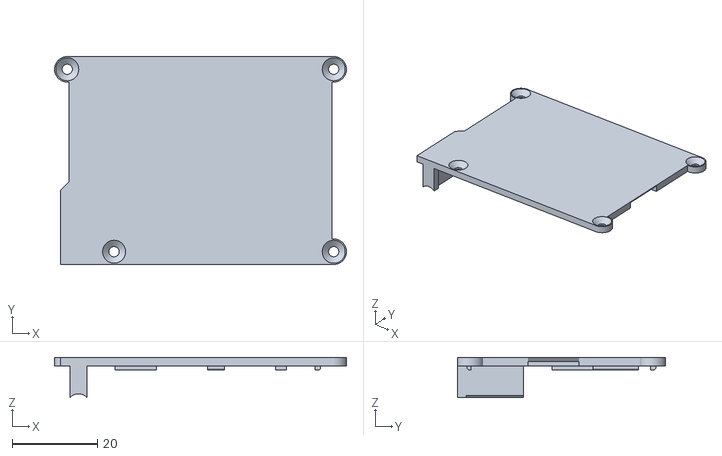
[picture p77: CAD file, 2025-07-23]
3Dfiles/D1-MIMI/Version 2/acw02 case top cable with thermo air flow.stl
68.6 x 48.9 x 9.49

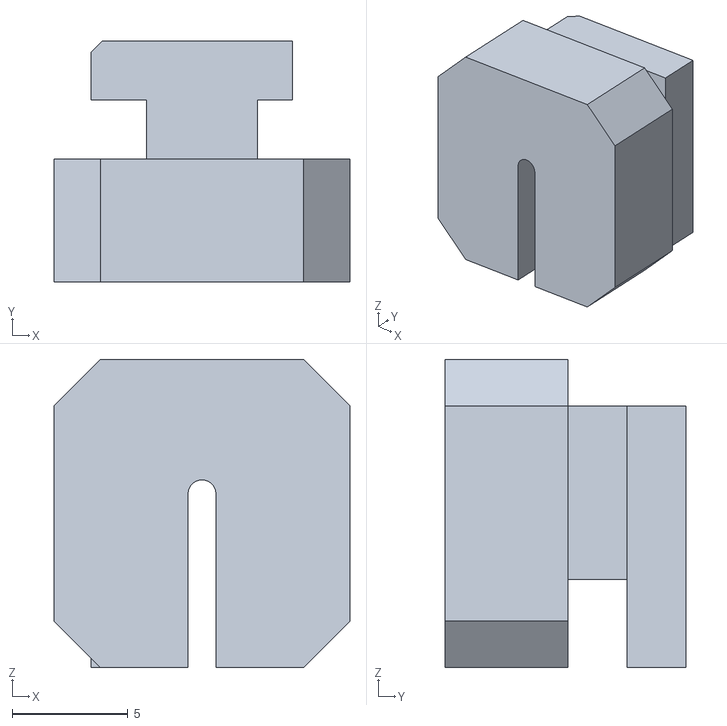
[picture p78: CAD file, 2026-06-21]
3Dfiles/LOLIN-C3-XIAO-C3-C6/support antenna flex free.stl
12.8 x 10.4 x 13.3

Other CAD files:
3Dfiles/D1-MIMI/Version 2/acw02 case bot with air flow.stl
3Dfiles/D1-MIMI/Version 2/acw02 case top air flow.stl
3Dfiles/LOLIN-C3-XIAO-C3-C6/button lolin c3.stl
3Dfiles/D1-MIMI/Version 1/acw02 case bot.stl
3Dfiles/D1-MIMI/Version 1/acw02 case top cable with thermo.stl
3Dfiles/D1-MIMI/Version 1/acw02 case top.stl
3Dfiles/D1-MIMI/Version 1/acw02 v43.f3d
3Dfiles/D1-MIMI/Version 2/acw02 case top cable with thermo plastic card.stl
3Dfiles/D1-MIMI/Version 2/acw02 v68.f3d
3Dfiles/LOLIN-C3-XIAO-C3-C6/acw02 v128.f3d
3Dfiles/LOLIN-C3-XIAO-C3-C6/support antenna rigid part A.stl
3Dfiles/full pcb by Forhorse/acw02 v129.f3d
PCB/esp32_D1_mini_wroom32/v1.0/dxf/PCB_climEspHome_esp32_d1_mini_2025-07-17 (1).dxf

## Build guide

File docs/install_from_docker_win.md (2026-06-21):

# 🔧 Build from Docker (Windows)

## 🐳 Install Docker Desktop on Windows

You can install it from the Microsoft Store or directly from:  
[Docker Windows Install Docs](https://docs.docker.com/desktop/setup/install/windows-install/)

---

## 🐧 Install WSL

Run PowerShell as administrator and execute:  
```powershell
wsl --install
wsl --install -d Ubuntu-22.04
```

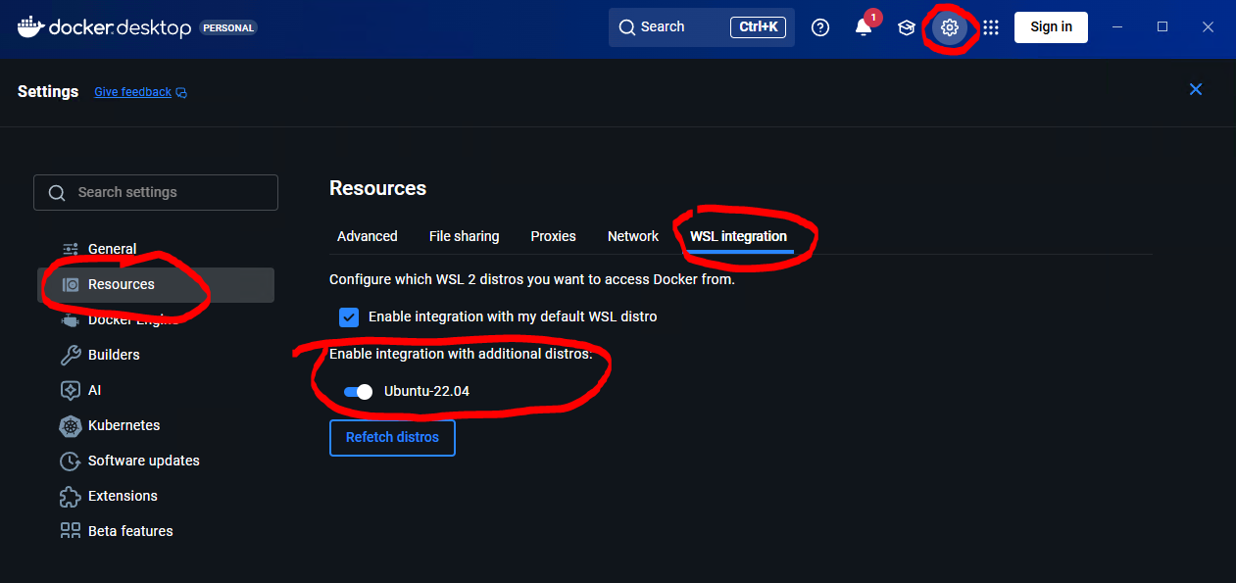
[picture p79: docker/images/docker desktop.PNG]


---

## 🔌 Install usbipd

- [Windows docs](https://learn.microsoft.com/fr-fr/windows/wsl/connect-usb)  
- [GitHub repo for download](https://github.com/dorssel/usbipd-win)

---

## 📦 Share USB to container

### Manually (important for understand script):

1. Connect your ESP via USB  
2. Run PowerShell as administrator  
3. List USB devices:
   ```powershell
   usbipd list
   ```
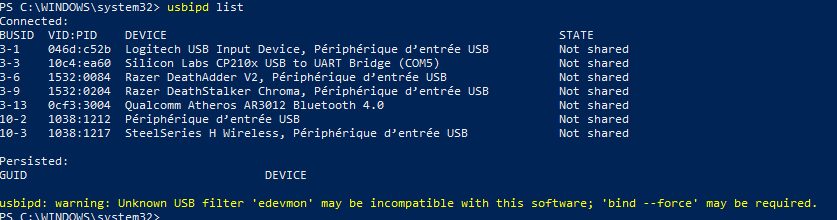
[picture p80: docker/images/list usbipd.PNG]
usbipd list
   

4. Find your ESP (e.g. for ESP32: *Silicon Labs CP210x USB to UART Bridge (COMX)*)  
5. Get the associated BUSID and bind it (replace `3-3` with your BUSID):
   ```powershell
   usbipd bind --busid 3-3
   ```

6. Run the list command again:
   ```powershell
   usbipd list
   ```
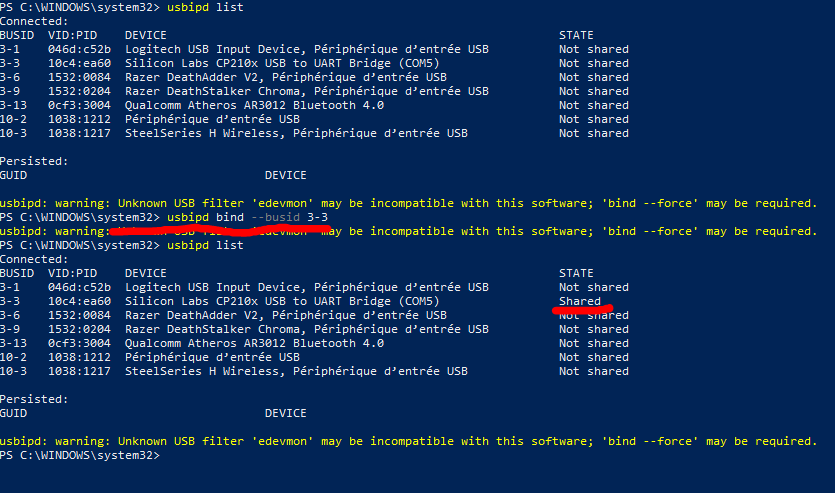
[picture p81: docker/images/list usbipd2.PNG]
usbipd list 2
   

7. Attach USB to WSL:
   ```powershell
   usbipd attach --wsl --busid 3-3
   ```
   usbipd attach

#### 🔁 Reverse commands

```powershell
usbipd detach --busid 3-3
usbipd unbind --busid 3-3
```

---

### With script:

1. Connect your ESP via USB  
2. Run PowerShell as administrator  
3. run cmd bellow for attach usb, this script ask you the BUSID

   ```powershell
   attach-usb.bat
   ```
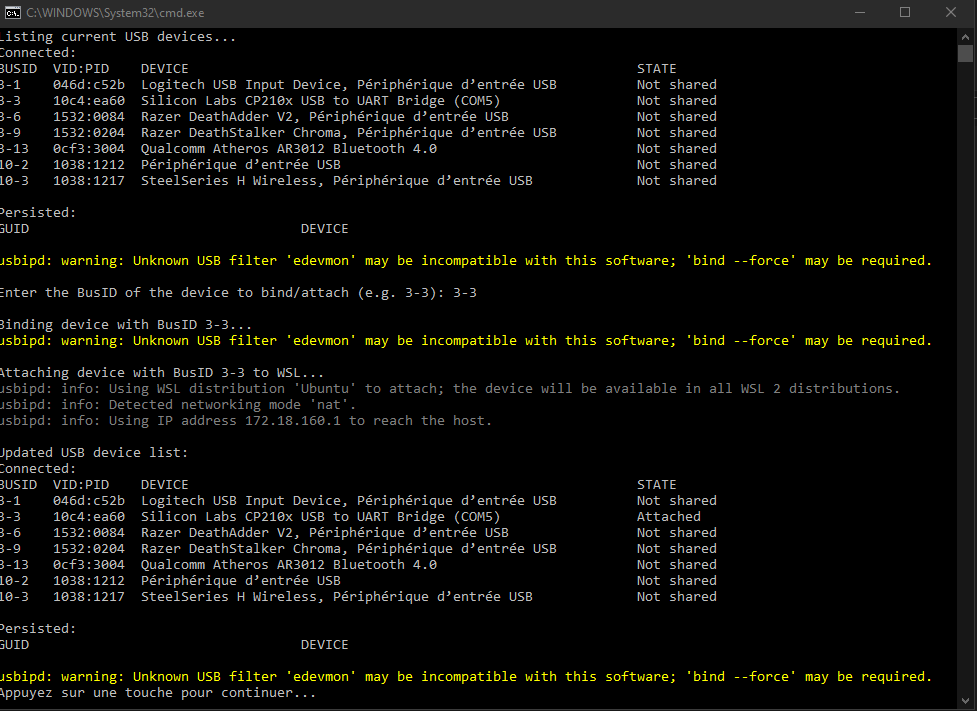
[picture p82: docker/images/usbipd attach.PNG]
usbipd attach
   

#### 🔁 Reverse commands
1. run cmd bellow for attach usb, this script ask you the BUSID

   ```powershell
   detach-usb.bat
   ```
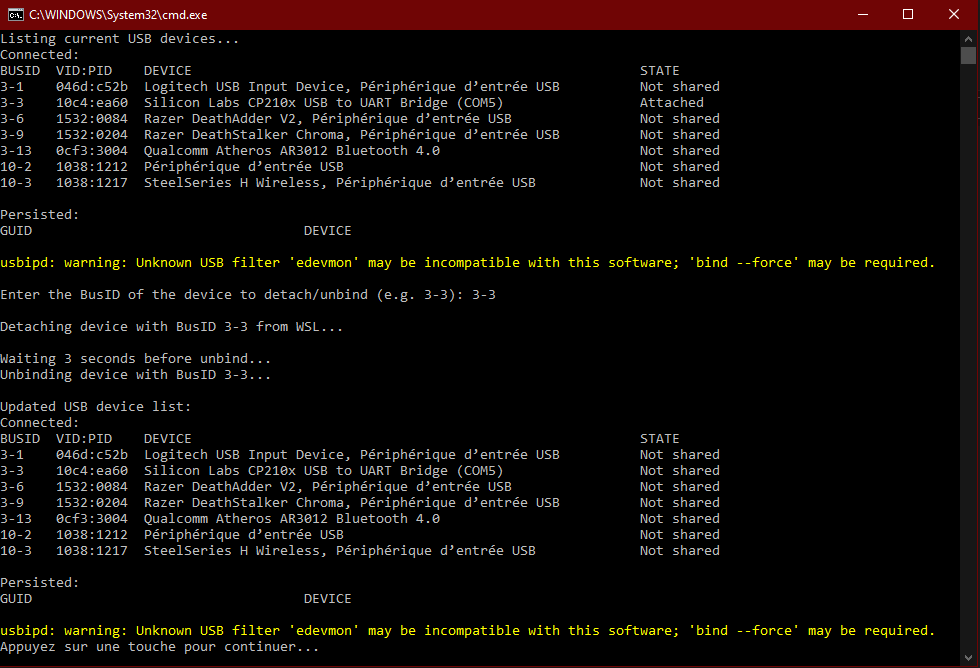
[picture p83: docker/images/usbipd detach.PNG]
usbipd attach
   

---

## 🛠️ Build component

### ⚙️ Install

1. Open PowerShell in the `docker` directory (inside the `acw02_esphome` project)  
2. Run commands one by one:
   ```powershell
   docker compose build
   docker compose up -d esphome-usb
   docker compose up -d esphome-usb-c3c6
   docker compose up -d esphome-ota
   ```
   or use script 
   ```powershell
   build-docker.bat
   start-docker.bat
   ```

3. Build and push firmware to USB (params ota | usb | usb-c3c6):
   ```powershell
   build-fr.bat
   ```
   or (depending on language) (params ota | usb | usb-c3c6):
   ```powershell
   build-en.bat
   ```

### 🧪 Optional commands

- `build-docker.bat` : build docker container
- `build-compile-only-fr.bat` : build only (FR), no flash  
- `build-compile-only-en.bat` : build only (EN), no flash  
- `open-container.bat` : enter Docker container (params ota | usb)
- `start-docker.bat` : only start docker (ota only)
- `stop-docker.bat` : only stop docker (ota + usb + usb-c3c6)
- `attach-usb.bat` : script for attach usb to docker
- `detach-usb.bat` : script for detach usb to docker
- `start-docker-with-attach-USB.bat` : run attach USB to docker and start docker (ota + usb + usb-c3c6)
- `stop-docker-with-attach-USB.bat` : run stop docker and detach USB to docker (ota + usb + usb-c3c6)
- `logs-fr.bat` : show logs OTA (FR)
- `logs-en.bat` : show logs OTA (EN)
- `clear-memory.bat` : reset memorised config  (usb | usb-c3c6)

---

## 📁 Bin files

You can find the generated `.bin` files in:  
```
docker/bin_generated
```

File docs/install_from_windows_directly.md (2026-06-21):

# 🔧 Build from Windows

### 🐍 Python

Install Python 3.11 from the Microsoft Store.

---

## 📦 Update pip

```powershell
pip install --upgrade pip
```

---

## 🧱 Install ESPHome

```powershell
pip install esphome==2025.11.4
```

---

## 🛠️ Build

To build the firmware in French:
```powershell
build-fr.bat
```

Or in English:
```powershell
build-en.bat
```

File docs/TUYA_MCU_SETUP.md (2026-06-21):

# 🌀 ESPHome Configuration for Airton AC with Wi-Fi Module 409945

This guide applies **only to Airton A+++ AC units using the Wi-Fi module 409945**.  
These models use the **Tuya MCU UART protocol** (`55 AA 03 ...`) instead of the custom `7A 7A ...` protocol implemented in this repository.  

## 🧩 Hardware Compatibility

All **hardware parts provided in this repository** — including the **PCB**, **wiring**, and **3D printed enclosure** — remain **fully compatible** with this configuration.  
Only the firmware and communication protocol differ.  

## 📚 More Information

For more details about the Tuya MCU integration in ESPHome, refer to the official documentation:  
👉 [ESPHome Tuya MCU Component](https://esphome.io/components/tuya/)

---

## 💬 Acknowledgments

Special thanks to **[@mrgnsrl](https://github.com/mrgnsrl)** 🙌  
for identifying all the correct **Tuya MCU datapoints (DPIDs)** and for providing the initial working **ESPHome YAML configuration** that made this compatibility possible.  
Your contribution greatly helps other Airton users integrate their AC units with ESPHome! 💡

---

## ⚠️ Known Limitation — Non-Reportable Datapoints

The Tuya MCU used in the Airton 409945 Wi-Fi module does **not** report all datapoints (DPs) back to the ESP module.  
Some DPs are **control-only (write-only)**, meaning they execute a command on the AC but **do not send any state feedback** —  
neither at startup, nor during periodic status updates, nor after remote control changes.

### 🧾 Verified Observation
Based on actual Tuya MCU status dumps, the unit reports the following datapoints:  
`1–5, 8, 20–22, 101–115`  
**DP13 (Display)** and a few others are **absent**, confirming that they are not part of the MCU’s reportable list.

### 🧩 Datapoint Behavior Summary
| Entity | Datapoint | Type | Reported by MCU | Behavior |
|:--|:--:|:--:|:--:|:--|
| **Power** | `1` | switch | ✅ Yes | Fully functional |
| **Target Temp.** | `2` | int | ✅ Yes | Fully functional |
| **Ambient Temp.** | `3` | int | ✅ Yes | Read-only |
| **Mode** | `4` | enum | ✅ Yes | Fully functional |
| **Fan Speed** | `5` | enum | ✅ Yes | Fully functional |
| **Display / Affichage** | `13` | switch | ❌ No | Write-only — never reported |
| **Horizontal Swing** | `106` | enum | ✅ Yes | Reported correctly |
| **Vertical Swing** | `107` | enum | ✅ Yes | Reported correctly |
| **Night / Sleep** | `109` | switch | ✅ Yes | Usually reported, but may lag |
| **Purifier / Health** | `110` | switch | ✅ Yes | Reported correctly |

### 🔍 Technical Explanation
In the Tuya MCU protocol (`55 AA 03 ...`), each datapoint is classified internally as:
- `R` — Readable (reported periodically to Wi-Fi)
- `W` — Writable (can be controlled from Wi-Fi)
- `R/W` — Read & Write
- `Write-only` — Executes an action locally, without feedback

The **Display switch (DP13)** is defined as **write-only**,  
and therefore it never appears in any Tuya MCU status message — confirmed by real UART logs.

### 💡 Recommendations
- Treat these “write-only” datapoints (like Display) as **unidirectional controls**.  
  ESPHome will keep the **last known state**, which might differ from the real device state if changed via remote.
- For such entities, consider using `optimistic: true` or `restore_value: yes` in your YAML configuration.

---

## ❗ Notes

This firmware version does not use **MQTT**, but if you want you can add it yourself in the yaml.

---

## 🧠 Example ESPHome Configuration

Edit the `substitutions` section (in yaml bellow) — you can modify:

- `dev_name`
- `dev_friendly`
- `api_encrypted_key`
- `ota_password`
- `ap_password`
- `web_server_username`
- `web_server_password`

```yaml
substitutions:
  dev_name: acw02-salon
  dev_friendly: ACW02 salon
  api_encrypted_key: "D2oldc0VP++fni6src89tCSC0UwBhNPgyc8vgYN8/mA="
  ota_password: "REPLACE_WITH_YOUR_PASSWORD"
  ap_password: "fallbackpassword"
  web_server_username: admin
  web_server_password: admin
  # ESP32 D1 mini WROOM 32
  board: esp32dev
  TX: GPIO17
  RX: GPIO16
  
  ## LOLIN ESP32 C3 MINI
  # board: lolin_c3_mini
  # TX: GPIO21
  # RX: GPIO20

  ## XIAO (seeeds studio) ESP32 C3
  # board: seeed_xiao_esp32c3
  # TX: GPIO21
  # RX: GPIO20

  ## XIAO (seeeds studio) ESP32 C6
  # board: seeed_xiao_esp32c6
  # TX: GPIO16
  # RX: GPIO17
```

⚠️ **The configuration depends on the ESP32 card chosen (Comment/uncomment the blocks)**  
 - **ESP32 D1 mini WROOM 32**
    ```
    # ESP32 D1 mini WROOM 32
    board: esp32dev
    TX: GPIO17
    RX: GPIO16
    ```
 - **LOLIN ESP32 C3 MINI**
    ```
    # LOLIN ESP32 C3 MINI
    board: lolin_c3_mini
    TX: GPIO21
    RX: GPIO20
    ```
 - **XIAO (seeeds studio) ESP32 C3**
    ```
    # XIAO (seeeds studio) ESP32 C3
    board: seeed_xiao_esp32c3
    TX: GPIO21
    RX: GPIO20
    ```
 - **XIAO (seeeds studio) ESP32 C6**
    ```
    # XIAO (seeeds studio) ESP32 C6
    board: seeed_xiao_esp32c6
    TX: GPIO16
    RX: GPIO17
    ```

🔑 I recommend visiting [this page](https://esphome.io/components/api.html) to generate a unique `api_encrypted_key`.

### FR Example Configuration (French version)

Below is a configuration in French adapted for the 409945 Tuya MCU module.  
It includes network fallback, web interface authentication, and hardware flexibility for various ESP32 boards.

```yaml
substitutions:
  dev_name: acw02-salon
  dev_friendly: ACW02 salon
  api_encrypted_key: "D2oldc0VP++fni6src89tCSC0UwBhNPgyc8vgYN8/mA="
  ota_password: "REPLACE_WITH_YOUR_PASSWORD"
  ap_password: "fallbackpassword"
  web_server_username: admin
  web_server_password: admin
  # ESP32 D1 mini WROOM 32
  board: esp32dev
  TX: GPIO17
  RX: GPIO16

  ## LOLIN ESP32 C3 MINI
  # board: lolin_c3_mini
  # TX: GPIO21
  # RX: GPIO20

  ## XIAO (seeeds studio) ESP32 C3
  # board: seeed_xiao_esp32c3
  # TX: GPIO21
  # RX: GPIO20

  ## XIAO (seeeds studio) ESP32 C6
  # board: seeed_xiao_esp32c6
  # TX: GPIO16
  # RX: GPIO17

esphome:
  name: ${dev_name}
  friendly_name: ${dev_friendly}

esp32:
  board: ${board}
  framework:
    type: esp-idf

web_server:
  port: 80
  auth:
    username: ${web_server_username}
    password: ${web_server_password}
  version: 3
  log: true
  local : true
  include_internal: true

logger:
  level: INFO

api:
  encryption:
    key: ${api_encrypted_key}

ota:
  - platform: esphome
    password: ${ota_password}
  - platform: web_server

wifi:
  ssid: !secret wifi_ssid
  password: !secret wifi_password
  power_save_mode: none
  # networks:
  #   - ssid: !secret wifi_ssid
  #     password: !secret wifi_password
  #   - ssid: !secret wifi_ssid2
  #     password: !secret wifi_password2
  #   - ssid: !secret wifi_ssid3
  #     password: !secret wifi_password3
  ap:
    ssid: ${dev_friendly}
    password: ${ap_password}

captive_portal:
	
uart:
  id: uart_acw02
  tx_pin: ${TX}
  rx_pin: ${RX}
  baud_rate: 9600

tuya:
climate:
  - platform: tuya
    id: acw02
    name: "Climatiseur"
    switch_datapoint: 1
    supports_heat: true
    supports_cool: true
    target_temperature_datapoint: 2
    current_temperature_datapoint: 3
    temperature_multiplier: 0.1
    on_state:
      - lambda: |-
          if (x.target_temperature < 10) {
            id(acw02).target_temperature = x.target_temperature * 10;
          }
    visual:
      min_temperature: 16
      max_temperature: 31
      temperature_step: 1
    active_state:
      datapoint: 4
      heating_value: 3
      cooling_value: 1
      drying_value: 2
      fanonly_value: 4
select:
  - platform: tuya
    name: "Ventilation"
    enum_datapoint: 5
    options:
      0: "Auto"
      1: "20%"
      2: "40%"
      3: "60%"
      4: "80%"
      5: "100%"
      6: "Silencieux"
      7: "Turbo"
  - platform: "tuya"
    name: "Oscillation Vertical"
    enum_datapoint: 107
    options:
      0: "Désactivé"
      1: "Activé"
      2: "Position 1"
      3: "Position 2"
      4: "Position 3"
      5: "Position 4"
      6: "Position 5"  
  - platform: "tuya"
    name: "Unité"
    enum_datapoint: 105
    options:
      0: "°C"
      1: "°F"
  - platform: "tuya"
    name: "Oscillation Horizontal"
    enum_datapoint: 106
    options:
      0: "Désactivé"
      1: "Activé"

switch:
  - platform: "tuya"
    name: "Affichage"
    switch_datapoint: 13
  - platform: "tuya"
    name: "Purificateur"
    switch_datapoint: 110
  - platform: "tuya"
    name: "Nuit"
    switch_datapoint: 109

```

### EN Example Configuration (English version)

Below is a configuration in English adapted for the 409945 Tuya MCU module.  
It includes network fallback, web interface authentication, and hardware flexibility for various ESP32 boards.

```yaml
substitutions:
  dev_name: acw02-salon
  dev_friendly: ACW02 salon
  api_encrypted_key: "D2oldc0VP++fni6src89tCSC0UwBhNPgyc8vgYN8/mA="
  ota_password: "REPLACE_WITH_YOUR_PASSWORD"
  ap_password: "fallbackpassword"
  web_server_username: admin
  web_server_password: admin
  # ESP32 D1 mini WROOM 32
  board: esp32dev
  TX: GPIO17
  RX: GPIO16

  ## LOLIN ESP32 C3 MINI
  # board: lolin_c3_mini
  # TX: GPIO21
  # RX: GPIO20

  ## XIAO (seeeds studio) ESP32 C3
  # board: seeed_xiao_esp32c3
  # TX: GPIO21
  # RX: GPIO20

  ## XIAO (seeeds studio) ESP32 C6
  # board: seeed_xiao_esp32c6
  # TX: GPIO16
  # RX: GPIO17

esphome:
  name: ${dev_name}
  friendly_name: ${dev_friendly}

esp32:
  board: ${board}
  framework:
    type: esp-idf

web_server:
  port: 80
  auth:
    username: ${web_server_username}
    password: ${web_server_password}
  version: 3
  log: true
  local : true
  include_internal: true

logger:
  level: INFO

api:
  encryption:
    key: ${api_encrypted_key}

ota:
  - platform: esphome
    password: ${ota_password}
  - platform: web_server

wifi:
  ssid: !secret wifi_ssid
  password: !secret wifi_password
  power_save_mode: none
  # networks:
  #   - ssid: !secret wifi_ssid
  #     password: !secret wifi_password
  #   - ssid: !secret wifi_ssid2
  #     password: !secret wifi_password2
  #   - ssid: !secret wifi_ssid3
  #     password: !secret wifi_password3
  ap:
    ssid: ${dev_friendly}
    password: ${ap_password}

captive_portal:
	
uart:
  id: uart_acw02
  tx_pin: ${TX}
  rx_pin: ${RX}
  baud_rate: 9600

tuya:
climate:
  - platform: tuya
    id: acw02
    name: "AC"
    switch_datapoint: 1
    supports_heat: true
    supports_cool: true
    target_temperature_datapoint: 2
    current_temperature_datapoint: 3
    temperature_multiplier: 0.1
    on_state:
      - lambda: |-
          if (x.target_temperature < 10) {
            id(acw02).target_temperature = x.target_temperature * 10;
          }
    visual:
      min_temperature: 16
      max_temperature: 31
      temperature_step: 1
    active_state:
      datapoint: 4
      heating_value: 3
      cooling_value: 1
      drying_value: 2
      fanonly_value: 4
select:
  - platform: tuya
    name: "Fan"
    enum_datapoint: 5
    options:
      0: "Auto"
      1: "20%"
      2: "40%"
      3: "60%"
      4: "80%"
      5: "100%"
      6: "Silent"
      7: "Turbo"
  - platform: "tuya"
    name: "Vertical swing"
    enum_datapoint: 107
    options:
      0: "Off"
      1: "On"
      2: "Position 1"
      3: "Position 2"
      4: "Position 3"
      5: "Position 4"
      6: "Position 5"  
  - platform: "tuya"
    name: "Unit"
    enum_datapoint: 105
    options:
      0: "°C"
      1: "°F"
  - platform: "tuya"
    name: "Horizontal swing"
    enum_datapoint: 106
    options:
      0: "Off"
      1: "On"

switch:
  - platform: "tuya"
    name: "Display"
    switch_datapoint: 13
  - platform: "tuya"
    name: "Purifier"
    switch_datapoint: 110
  - platform: "tuya"
    name: "Night"
    switch_datapoint: 109

```

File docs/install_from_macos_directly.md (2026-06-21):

# 🚀 Installation on macOS

## 🖥️ Tested Environment
- Mac Mini 2018
- 3 GHz Intel Core i5 (6 cores)
- 8 GB 2667 MHz DDR4
- macOS 15.7 (24G222)

## 📋 Prerequisites
1. Clone the repository:
   ```bash
   git clone https://github.com/devildant/acw02_esphome.git
   ```
2. Copy the YAML file for your preferred language, for example:
   ```bash
   cp esphome-acw02-fr.yaml my-esphome-acw02.yaml
   ```
   > ℹ️ The file can be `esphome-acw02-fr.yaml` or `esphome-acw02-en.yaml` depending on the language you want.
3. Configure `my-esphome-acw02.yaml` and `secrets.yaml`.

---

# ⚡ ESPHome: Installation, Build, and Flash

## 1️⃣ ESPHome Installation
Install a specific ESPHome version via Homebrew:

```bash
brew install esphome@2025.11.4
esphome version  # should return 2025.11.4
```

---

## 2️⃣ Build and Run
```bash
esphome run my-esphome-acw02.yaml
```

---

## 3️⃣ Choose Upload Method
After compilation, ESPHome will show multiple upload options:

```text
INFO Package configuration completed successfully
INFO Package configuration completed successfully
INFO Successfully compiled program.
Found multiple options for uploading, please choose one:
  [1] /dev/cu.usbserial-0001 (CP2102 USB to UART Bridge Controller - CP2102 USB to UART Bridge Controller)
  [2] Over The Air (acw02-entree.local)
  [3] Over The Air (MQTT IP lookup)
(number): 1
```

- Select the number that fits your situation.

---

## 4️⃣ Startup and Wi-Fi Connection
Be patient during the first connection:

```text
esptool v5.0.2
Connected to ESP32 on /dev/cu.usbserial-0001:
Chip type:          ESP32-D0WD-V3 (revision v3.1)
Features:           Wi-Fi, BT, Dual Core + LP Core, 240MHz, Vref calibration in eFuse, Coding Scheme None
Crystal frequency:  40MHz
MAC:                5c:01:3b:4c:52:50

Stub flasher running.
Changing baud rate to 460800...
Changed.

Configuring flash size...

[...]

[22:50:22.430][W][component:296]: wifi set Warning flag: scanning for networks
[22:50:22.435][W][acw02:2996]: TX: [7A.7A.21.D5.0C.00.00.AB.0A.0A.FC.F9 (12)]
[22:50:22.861][W][wifi_esp32:1001]: esp_wifi_sta_get_ap_info failed: ESP_ERR_WIFI_NOT_CONNECT
[22:50:22.869][W][wifi_esp32:991]: esp_wifi_sta_get_ap_info failed: ESP_ERR_WIFI_NOT_CONNECT
[22:50:22.876][W][wifi_esp32:1012]: esp_wifi_sta_get_ap_info failed: ESP_ERR_WIFI_NOT_CONNECT
[22:50:24.294][W][acw02:872]: Wi-Fi not connected; retrying in 5 s
[22:50:25.023][W][wifi:612]: No matching network found
[22:50:28.297][W][acw02:872]: Wi-Fi not connected; retrying in 5 s
[22:50:32.300][W][acw02:872]: Wi-Fi not connected; retrying in 5 s
[22:50:32.634][W][wifi:612]: No matching network found
[22:50:36.303][W][acw02:872]: Wi-Fi not connected; retrying in 5 s
[22:50:40.245][W][wifi:612]: No matching network found
[22:50:40.307][W][acw02:872]: Wi-Fi not connected; retrying in 5 s
[22:50:44.311][W][acw02:872]: Wi-Fi not connected; retrying in 5 s
[22:50:47.856][W][wifi:612]: No matching network found
[22:50:48.313][W][acw02:872]: Wi-Fi not connected; retrying in 5 s
[22:50:52.317][W][acw02:872]: Wi-Fi not connected; retrying in 5 s
[22:50:55.467][W][wifi:612]: No matching network found
[22:50:56.319][W][acw02:872]: Wi-Fi not connected; retrying in 5 s
[22:51:00.323][W][acw02:872]: Wi-Fi not connected; retrying in 5 s
[22:51:00.480][I][wifi:329]: Connecting to 'Fra...'
[22:51:04.260][I][wifi:675]: Connected
[22:51:04.264][W][wifi:678]: Network 'Fra...' should be marked as hidden
[22:51:04.282][I][app:120]: setup() finished successfully!
[22:51:04.288][W][component:326]: wifi cleared Warning flag
[22:51:04.293][I][app:185]: ESPHome version 2025.9.3 compiled on Oct  2 2025, 22:47:45
[22:51:04.330][W][acw02:863]: Wi-Fi OK; attempting MQTT connection…
[22:51:04.335][W][component:287]: mqtt set Warning flag: unspecified
[22:51:04.336][I][mqtt:268]: Connecting
[22:51:04.382][W][acw02:881]: MQTT connected → publishing discovery and state
[22:51:04.388][W][component:326]: mqtt cleared Warning flag
[22:51:04.389][I][mqtt:309]: Connected
```

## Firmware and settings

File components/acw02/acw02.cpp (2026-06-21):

#include "acw02.h"
#include "esphome/core/log.h"
#include "esphome/core/helpers.h"

#ifdef CONFIG_IDF_TARGET_ESP32C6
#include "driver/gpio.h"
#endif

namespace esphome {
  namespace acw02 {

    void ACW02::setup() {
      #if defined(DLOCALE_LANG)
        app_lang_ = DLOCALE_LANG;
      #else
        app_lang_ = "en";
      #endif
      #if defined(DBOARD)
        app_board_ = DBOARD;
      #endif

      // force use external Wi-Fi antenna (XIAO ESP32-C6)
      #if CONFIG_IDF_TARGET_ESP32C6
        // GPIO3 -> LOW
        gpio_reset_pin(GPIO_NUM_3);
        gpio_set_direction(GPIO_NUM_3, GPIO_MODE_OUTPUT);
        gpio_set_level(GPIO_NUM_3, 0);

        // GPIO14 -> HIGH
        gpio_reset_pin(GPIO_NUM_14);
        gpio_set_direction(GPIO_NUM_14, GPIO_MODE_OUTPUT);
        gpio_set_level(GPIO_NUM_14, 1);

        ESP_LOGW(TAG, "RF switch set for XIAO ESP32-C6: external Wi-Fi antenna enabled");
      #endif

      mqtt_connexion();
      app_name_ = App.get_name();
      app_friendly_name_ = App.get_friendly_name();
      app_sanitize_name_ = sanitize_name(app_name_);
      app_mac_ = get_mac_address();

      send_static_command_basic(keepalive_frame_);
      presets_list_element_config_ = PRESETS_LIST_ELEMENT_CONFIG_DEFAULT;
      presets_list_element_ = get_localized_name(app_lang_, "presetNone");
      mute_pref_ = global_preferences->make_preference<bool>(1U, "ac_mute");
      mute_pref_.load(&mute_);
      disable_mode_auto_pref_ = global_preferences->make_preference<bool>(2U, "ac_disable_mode_auto");
      disable_mode_auto_pref_.load(&disable_mode_auto_);
      disable_mode_heat_pref_ = global_preferences->make_preference<bool>(3U, "ac_disable_mode_heat");
      disable_mode_heat_pref_.load(&disable_mode_heat_);
      disable_mode_dry_pref_ = global_preferences->make_preference<bool>(4U, "ac_disable_mode_dry");
      disable_mode_dry_pref_.load(&disable_mode_dry_);
      disable_mode_fan_pref_ = global_preferences->make_preference<bool>(5U, "ac_disable_mode_fan");
      disable_mode_fan_pref_.load(&disable_mode_fan_);
      disable_swing_vertical_pref_ = global_preferences->make_preference<bool>(6U, "ac_disable_swing_vertical");
      disable_swing_vertical_pref_.load(&disable_swing_vertical_);
      disable_swing_horizontal_pref_ = global_preferences->make_preference<bool>(7U, "ac_disable_swing_horizontal");
      disable_swing_horizontal_pref_.load(&disable_swing_horizontal_);
      option_recalculate_climate_pref_ = global_preferences->make_preference<bool>(8U, "ac_option_recalculate_climate");
      option_recalculate_climate_pref_.load(&option_recalculate_climate_);
      option_G1_MQTT_pref_ = global_preferences->make_preference<bool>(9U, "ac_option_g1_mqtt");
      option_G1_MQTT_pref_.load(&option_g1_mqtt_);
      previous_temp_c_pref_ = global_preferences->make_preference<bool>(10U, "ac_previous_temp_c");
      previous_temp_c_pref_.load(&previous_target_temp_c_);
      previous_temp_f_pref_ = global_preferences->make_preference<bool>(11U, "ac_previous_temp_f");
      previous_temp_f_pref_.load(&previous_target_temp_f_);
      auto_off_options_when_ac_off_pref_ = global_preferences->make_preference<bool>(12U, "ac_auto_off_options_when_ac_off");
      auto_off_options_when_ac_off_pref_.load(&auto_off_options_when_ac_off_);
      mute_next_cmd_after_on_delay_pref_ = global_preferences->make_preference<int>(13U, "ac_mute_after_power_on_delay");
      if (!mute_next_cmd_after_on_delay_pref_.load(&mute_next_cmd_after_on_delay_)) {
        mute_next_cmd_after_on_delay_ = 0;
      }
      mute_next_cmd_delay_pref_ = global_preferences->make_preference<int>(14U, "ac_mute_next_cmd_delay");
      if (!mute_next_cmd_delay_pref_.load(&mute_next_cmd_delay_)) {
        mute_next_cmd_delay_ = 0;
      }
      publish_stats_after_power_on_delay_pref_ = global_preferences->make_preference<int>(15U, "ac_publish_stats_after_power_on_delay");
      if (!publish_stats_after_power_on_delay_pref_.load(&publish_stats_after_power_on_delay_)) {
        publish_stats_after_power_on_delay_ = 0;
      }
      preset_pref_ = global_preferences->make_preference<bool>(16U, "ac_preset");
      preset_pref_.load(&preset_);
      load_presets_from_flash();

      set_timeout("test", 10000, [this]() {
        ESP_LOGD(TAG, "Setup %s ", "INIT");
        ESP_LOGD(TAG, "Board %s ", app_board_.c_str());
        ESP_LOGD(TAG, "MAC %s ", app_mac_.c_str());
        ESP_LOGD(TAG, "name %s ", app_name_.c_str());
        ESP_LOGD(TAG, "friendly name %s ", app_friendly_name_.c_str());
        ESP_LOGD(TAG, "sanitze name %s ", app_sanitize_name_.c_str());
        ESP_LOGD(TAG, "MQTT broker %s ", mqtt_broker_address_.c_str());
        ESP_LOGD(TAG, "MQTT username %s ", mqtt_username_.c_str());
        ESP_LOGD(TAG, "MQTT port %d ", mqtt_port_);
        ESP_LOGD(TAG, "Lang %s ", app_lang_.c_str());
        ESP_LOGD(TAG, "name %s ", get_localized_name(app_lang_, "climate").c_str());
        ESP_LOGD(TAG, "mode json %s ", build_options_json(app_lang_, "mode").c_str());
        ESP_LOGD(TAG, "fan json %s ", build_options_json(app_lang_, "fan").c_str());
        ESP_LOGD(TAG, "swing json %s ", build_options_json(app_lang_, "swing").c_str());
        //  send_static_command_basic(get_status_frame_);
      });
    }

    void ACW02::loop() {
      process_tx_queue();

      while (available()) {
        uint8_t byte = read();
        rx_buffer_.push_back(byte);
        last_rx_byte_time_ = millis();
      }

      // for check size rx buffer
      if (rx_buffer_.size() > rx_max_depth_) {
        rx_max_depth_ = rx_buffer_.size();
        ESP_LOGW(TAG, "RX max depth = %u", (unsigned)rx_max_depth_);
      }

      // Wait at least 10ms of silence before processing buffer
      if (!rx_buffer_.empty() && millis() - last_rx_byte_time_ > 10) {
        static const std::array<size_t, 4> VALID_SIZES = {13, 18, 28, 34};

        size_t offset = 0;
        while (rx_buffer_.size() - offset >= 13) {  // Minimum frame size
          bool found = false;

          for (size_t size : VALID_SIZES) {
            if (offset + size > rx_buffer_.size())
              continue;

            if (rx_buffer_[offset] != 0x7A || rx_buffer_[offset + 1] != 0x7A)
              continue;

            const uint8_t *start = rx_buffer_.data() + offset;
            uint16_t expected_crc = (start[size - 2] << 8) | start[size - 1];
            uint16_t computed_crc = crc16(start, size - 2);

            if (computed_crc == expected_crc) {
              std::vector<uint8_t> frame(start, start + size);
              ESP_LOGW(TAG, "RX: [%s]", format_hex_pretty(frame).c_str());
              decode_state(frame);
              offset += size;
              found = true;
              break;
            }
          }

          if (!found) {
            // Skip invalid start byte and retry
            offset++;
          }
        }
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

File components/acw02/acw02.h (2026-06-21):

#pragma once

#include "esphome/core/component.h"
#include "esphome/components/uart/uart.h"
#include <vector>
#include <cstdint>
#include "esphome/core/preferences.h"
#include <deque>
#include "esphome/components/mqtt/mqtt_client.h"
// #include <esp_wifi.h>
#include <esp_mac.h>
#include "esphome/core/application.h"
#include <algorithm>
#include "esphome/components/wifi/wifi_component.h"
#include "esphome/components/binary_sensor/binary_sensor.h"
#include "esphome/components/text/text.h"
#include "localization.h"

namespace esphome {
namespace acw02 {

using namespace acw02_localization;

  // Enum for mapping action to byte
  enum class Mode : uint8_t { COOL = 0x01, DRY = 0x02, FAN = 0x03, HEAT = 0x04, AUTO = 0x00 };
  enum class Fan  : uint8_t { AUTO = 0x0, P20 = 0x1, P40 = 0x2, P60 = 0x3,
                              P80 = 0x4, P100 = 0x5, SILENT = 0x6, TURBO = 0xD };
  enum class Swing  : uint8_t { P1 = 0x02, P2 = 0x03, P3 = 0x04, P4 = 0x05,
                          P5 = 0x06, SWING = 0x01, STOP = 0x00 };
  enum class SwingHorizontal : uint8_t { STOP = 0x0, AUTO_LEFT = 0x1, P1 = 0x2, P2 = 0x3,
                                         P3 = 0x4, P4 = 0x5, P5 = 0x6, RANGE_P1_P5 = 0xC, AUTO_MID_OUT = 0xD};

  // globals Statics
  static const char *const TAG = "acw02";

  struct Frame_with_Fingerprint {
    uint32_t fingerprint;
    std::string description;
    std::vector<uint8_t> frame;
    uint32_t timestamp_ms;
    int tryCnt;
  };

  static constexpr int maxRetry = 3;


  // globals Statics base frame (keep alive?)
  static const std::vector<uint8_t> keepalive_frame_ = {
    0x7A, 0x7A, 0x21, 0xD5, 0x0C, 0x00, 0x00, 0xAB,
    0x0A, 0x0A, 0xFC, 0xF9
  };

  // globals Statics base frame (ask status AC)
  static const std::vector<uint8_t> get_status_frame_ = {
    0x7A, 0x7A, 0x21, 0xD5, 0x0C, 0x00, 0x00, 0xA2,
    0x0A, 0x0A, 0xFE, 0x29
  };

  // globals Statics byte for °F from 61 to 88
  static const uint8_t fahrenheit_encoding_table_[28] = { 
    0x20, 0x21, 0x31, 0x22, 0x32, 0x23, 0x33, 0x24,0x25,
    0x35, 0x26, 0x36, 0x27, 0x37, 0x28, 0x38, 0x29,0x2A, 
    0x3A, 0x2B, 0x3B, 0x2C, 0x3C, 0x2D, 0x3D, 0x2E, 0x2F, 
    0x3F };

  struct PresetSlot {
    int index;
    std::string name;
    Frame_with_Fingerprint frame_with_fp;
  };

  const std::string PRESETS_LIST_ELEMENT_CONFIG_DEFAULT = "_______________";

class ACW02 : public Component, public uart::UARTDevice {
 public:
  

  //override
  void setup() override;
  void loop() override;
  
  // Setters publics AC
  void set_mode_climate(const std::string &mode);      
  void set_mode(const std::string &mode);
  void set_swing(const std::string &pos);   
  void set_swing_horizontal(const std::string &pos);       
  void set_purifier(bool on);
  void set_mute(bool on);
  void set_unit(const std::string &unit); 
  void set_clean(bool on);

  // Setters publics AC with bool for detect if send cmd is necessary
  bool set_temperature_c(float temp); 
  bool set_temperature_f(float temp);              
  bool set_fan(const std::string &speed);         
  bool set_display(bool on);
  bool set_eco(bool on);
  bool set_eco_internal(bool on, bool force = false);
  bool set_night(bool on);

  // Setters reset option when AC off
  void set_auto_off_options_when_ac_off(bool on);

  // Setters set mute after ac power on with delay
  void set_mute_next_cmd_delay_string(const std::string &value);
  void set_mute_next_cmd_after_on_delay_string(const std::string &value);
  void set_publish_stats_after_power_on_delay_string(const std::string &value);

  
  // Setters G1 : MQTT
  void set_g1_mqtt_options(bool on);

  // Setters publics disable option mode
  void set_disable_mode_auto(bool on, bool published = true);
  void set_disable_mode_heat(bool on, bool published = true);
  void set_disable_mode_dry(bool on, bool published = true);
  void set_disable_mode_fan(bool on, bool published = true);
  void set_disable_swing_vertical(bool on, bool published = true);
  void set_disable_swing_horizontal(bool on, bool published = true);

  // Setters publics, sync element esphome native in yaml to cpp
  void entity_mdns_sync(const std::string &payload);
  void entity_wifi_ip_sync(const std::string &payload);
  void entity_wifi_ssid_sync(const std::string &payload);
  void entity_wifi_bssid_sync(const std::string &payload);
  void entity_wifi_mac_sync(const std::string &payload);
  void entity_esp_version_sync(const std::string &payload);
  void entity_wifi_signal_sync(const std::string &payload);
  void entity_internal_temperature_sync(const std::string &payload);
  void entity_esp_memory_sync(const std::string &payload);

  // Setters publics presets
  void set_preset(bool on, bool published = true);

  // Setters publics option for rebuild climate if mode auto or option eco enable
  void set_option_recalculate_climate(bool on);

  // Setters publics MQTT
  void set_mqtt_broker(const std::string &value);
  void set_mqtt_username(const std::string &value);
  void set_mqtt_password(const std::string &value);
  void set_mqtt_port_from_string(const std::string &value);
  void set_mqtt_connected_sensor(esphome::binary_sensor::BinarySensor *sensor);

  // Setters sensor fault/warn
  void set_filter_dirty_sensor(binary_sensor::BinarySensor *sensor);
  void set_warn_sensor(binary_sensor::BinarySensor *sensor);
  void set_error_sensor(binary_sensor::BinarySensor *sensor);
  void set_warn_text_sensor(esphome::text_sensor::TextSensor *sensor);
  void set_error_text_sensor(esphome::text_sensor::TextSensor *sensor);
  void set_cmd_ignore_tx_sensor(esphome::text_sensor::TextSensor *sensor);
  void set_cmd_ignore_rx_sensor(esphome::text_sensor::TextSensor *sensor);

  // Setters sensor for mute with delay and condition
  void set_mute_next_cmd_delay_text(esphome::text::Text *text);
  void set_mute_next_cmd_after_on_delay_text(esphome::text::Text *text);
  void set_publish_stats_after_power_on_delay_text(esphome::text::Text *text);


  // Send command UART
  void reload_ac_info();

  // Getters publics globals
  std::string get_mac_address();
  std::string get_address();

  // Getters publics AC
  std::string get_mode_string_climate() const;
  std::string get_mode_string() const;
  std::string get_fan_string() const;
  std::string get_swing_string() const;
  std::string get_unit() const;

  float get_target_temperature_c() const;
  float get_target_temperature_f() const;
 
  bool is_power_on() const;
  bool is_eco_on() const;
  bool is_night_on() const;
  bool is_purifier_on() const;
  bool is_display_on() const;
  bool is_mute_on() const;
  bool is_clean_on() const;
  bool is_using_fahrenheit() const;

  // reset option when AC off
  bool is_auto_off_options_when_ac_off() const;

  // mute with delay and condition
  int get_mute_next_cmd_delay() const;
  int get_mute_next_cmd_after_on_delay() const;
  int get_publish_stats_after_power_on_delay() const;
  
  // G1: MQTT
   bool is_g1_mqtt_options() const;
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

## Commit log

2025-07-12 remove option disable cool (useless) + reorder persist var + fix clean option + log origin cmd (remote or esp) + force cool option if disable mode select by remote
    [acw02.cpp, acw02.h]
2025-07-12 sensor origin cmd
2025-07-12 fix available for eco if ac off
    [acw02.cpp]
2025-07-13 sensor connectivity MQTT
2025-07-13 filter dirty detection + sensor
2025-07-15 filter to clean in mqtt + tag version esphome use in readme
2025-07-17 info pcb
2025-07-18 qrcode adapt to case, for print scale 1/1
2025-07-18 3d files
    [acw02 case top.stl, acw02 v42.f3d, button.stl]
2025-07-18 option cable with thermo (3D)
    [acw02 case top cable with thermo.stl, acw02 v42.f3d, acw02 v43.f3d]
2025-07-18 add offset for printer
2025-07-23 update stl + qrcode gen for add label
    [acw02 case top air flow.stl, acw02 case top cable with thermo air flow.stl, acw02 case top cable with thermo plastic card.stl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]
2025-07-23 esphome 2025.7.3 + lock min max climate mode auto or option eco + fix target temp to 25°C if mode auto (and restaure prev value if mode change) + adjust option auto recalc for apply only for eco (fan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
    [acw02.cpp, acw02.h]
2025-07-23 calculate range for mode auto, force setTemperature to 20 if current temp < 20 and 25 if current temp >= 20 and force send this temps to ac if send from remote
2025-07-24 optimize + fix bug when wrong rx (add retry) + fix conflics with remote
    [acw02.cpp, acw02.h]
2025-07-24 fix bug with uart introduce in 2025.7.x
    [acw02.cpp]
2025-07-27 add error and warning sensor
    [acw02.cpp, acw02.h]
2025-07-27 update doc for add sensor error and arn
2025-07-31 fix climate power (on/off)
    [acw02.cpp]
2025-08-02 fingerprint for detect if cmd change stat and not send to ac if same + qos 1 for all mqtt element + option mute tmp cmd with delay or with delay if ac On
2025-08-02 order function + fix bug + rename
    [acw02.cpp, acw02.h]
2025-08-02 fix to delay to 10min max + opti + add mqtt version for 2 new g1 option (mute with delay)
    [acw02.cpp, acw02.h]
2025-08-02 fix issue + update doc
    [acw02.cpp, acw02.h]
2025-08-02 remove [Z-Mute] bracket for good position in ha
2025-08-04 split 2 delay for manage classic cmd and after power on + add delay for publish stat after power on + security
2025-08-04 add option for defined delay publish after power on + rename Z-mute in Z-CMD + update doc
2025-08-04 fix bug + update doc
    [acw02.cpp]
2025-08-04 fix issue origine cmd detection, with remote if display is enable the hexa code is 0x88....
    [acw02.cpp]
2025-08-05 fix little bug time_publish_stats_after_power_on_ and add yaml for build with esphome buider on ha
    [acw02.cpp]
2025-08-08 fix icon swing H
    [acw02.cpp]
2025-08-08 preset init
    preset clean and opti
    split in 2 select preset+ fix bug with preset swing H in preset
    fix bug + rename boolean presets
    change icon preset
    preset option for change name + auto reset preset if ac recieve another cmd
    send preset + fix bug
    fix bug with present in english
    update doc for preset
    fix limit name preset
    [acw02.cpp, acw02.h]
